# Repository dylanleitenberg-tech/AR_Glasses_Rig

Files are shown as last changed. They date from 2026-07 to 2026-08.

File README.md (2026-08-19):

# AR Eye Calibration Rig

AR glasses drift on your face all day, and every millimeter of slip moves where a display
pixel lands in the real world. This project is a camera rig and learning system that
measures how the glasses sit on your face in real time and corrects the overlay, so that
a pixel meant to land on a real object actually lands on it.

I designed and built this from scratch: the physics simulation, the calibration math, the
3D printed camera mount, the electronics and safety design, and the verification tooling
that checks all of it. 

I was able to achieve results with 4 cams so 6 may not be necessary. 
I mostly did this because the 6th cam arrived weeks later. 
Also, my power hub struggled on four so unless you have 
some heavy-duty hardware, 4 may be the way to go.

## Build overview and results

The rig is a 6-camera clip-on carrier for the XREAL One Pro AR glasses:

- 2 forward color cameras (global shutter) that triangulate a target drawn on paper
- 2 cameras watching the corners of your eyes, which is how the rig knows the glasses
  pose on your face at every instant
- 2 near-infrared cameras imaging each pupil, with 940 nm illumination behind hardware
  safety interlocks
- an IMU for slip and bump detection, all on one printed part that clamps to the glasses
  brow with padded jaws shaped to the measured curve of the frame

I drew up two versions of this carrier, an eight-camera one that adds a stereo pair and the
six-camera one above, and started with six. When the first cameras arrived I built a
four-camera rig from them, the two forward and the two watching my eye corners, and every
measurement in this repository so far was taken on those four. The fifth camera has arrived
and the sixth is on its way; the near-infrared pupil pair is the last thing to go in. The
parts lists still cost out the eight-camera version, which is where the sub-pixel work would
go.

Results so far, from a physics simulation built to be pessimistic about human error:

- With a naive calibration interface, deployed accuracy is about 13 pixels. Most of that
  error is the human in the loop, not the optics.
- With the interface I built instead (a vernier alignment task plus a per-user offset
  stage), simulated deployed accuracy is about 4.3 pixels as the user perceives it, on a
  1080p display per eye.
- The same pipeline with ideal inputs reaches 0.89 pixels, so the hardware and math
  support sub-pixel registration. Closing that gap requires a multi-distance
  calibration protocol that only works on real hardware, which is now implemented:
  the best measured result so far is 5.3 pixels median overlay error, cross-validated
  leave-one-out on a 33-sample run, using the physics geometry plus a quadratic
  learned residual. That is one evening on one seating, not a characterized average,
  and it sits close to the simulated 4.3.
- Just as important are the negative results. I tested and rejected several appealing
  shortcuts (bias-invariant fingerprints, richer per-user correction models, direct
  geometry refinement on user labels) because the simulation showed each one quietly
  overfits. The failures shaped the design as much as the successes.

 I also got the rig to draw an outline around a star shape on my wall, matching its 
 orientation and size, and the outline held on the shape as I moved my head. That is the closest
 the project has come to my end goal of real-world object overlay: not placing a marker at a point, 
 but tracing the boundary of an actual object and keeping it there under motion. My computer then 
 failed and that code was lost. I rebuilt it two days later on a replacement machine, and the
 new version is stronger than the one I lost: it traces the star's detected boundary point by
 point through the calibrated geometry, so orientation and size match by construction, and it
 held the outline on the shape for 99.8% of frames while my head moved.

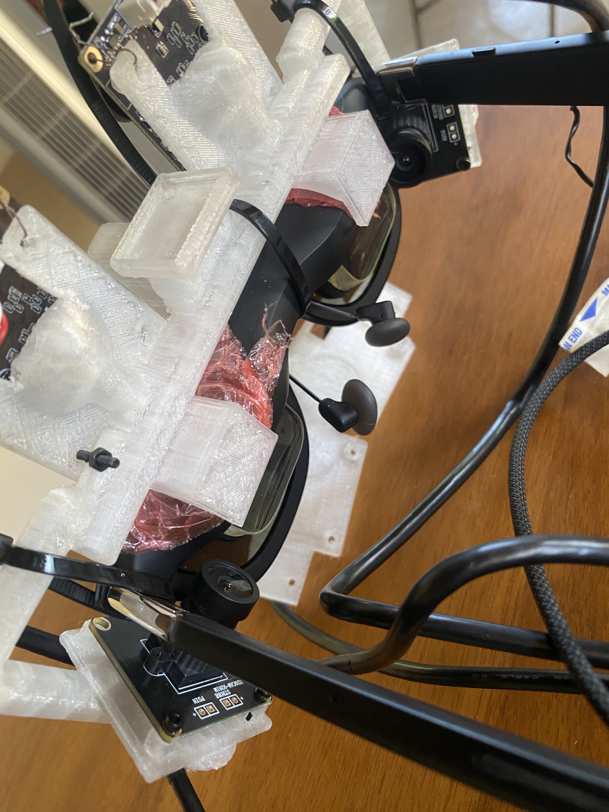
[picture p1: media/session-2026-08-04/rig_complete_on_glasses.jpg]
The rig


Current status: the rig is built and running on my face, now on a replacement computer
after the first one died. The forward pair finds the target and measures its distance at
30 frames per second with sub-pixel detection jitter, the calibration loop runs at over
80, and I have real calibration samples stored and a cross-validated overlay error rather
than a simulated one. The eye landmark model is trained on a fresh corpus of 2,588 frames
I captured and hand-labelled on the new machine, with a separate head that reports when
the eye is closed. One practical note from the rebuild: a single powered hub carries only
three of these camera streams at once, so calibration currently runs on the world pair
alone and the eye cameras run in their own sessions, until the cameras are split across
two host ports.

What the hardware phase actually produced, all measured on the rig:

- Overlay latency went from 196 ms to 62 ms once I worked out that most of it was my own
  smoothing rather than the cameras.
- I reverse engineered the IMU inside the glasses, which streams over TCP at about 1100 Hz.
  Nobody had documented the format, so I read raw packets and found the gyroscope and
  accelerometer by checking a stationary reading against gravity: 9.773 against 9.81.
- The overlay is now computed from physics rather than learned from scratch. A polynomial
  fit on few samples was throwing the marker across the display, so geometry became the
  backbone and learning became a correction that has to prove it helps before it is used.
- The display field of view had been assumed at 50 degrees since the project started. I
  measured it two ways and got closer to 48, which was worth more error than getting a
  user's eye spacing wrong by two standard deviations. Measuring again on the new machine
  went further: in follow mode the glasses render the desktop as a virtual screen of
  about 22 degrees, sitting below the forward axis, and both numbers depend on the
  glasses' display mode and screen-size setting. The constants are measured per session
  now, and every round of measuring this number has bought more accuracy than any model
  change.

## Why this problem

An AR display pixel corresponds to a ray leaving your eye through the optic into the
world. Where that ray lands depends on three things: the pixel you light up, the fixed
optics of the display, and where the glasses currently sit relative to your eyeball
(eye relief, slip down your nose, a few degrees of tilt, your IPD). That third item is
the killer. Shift the glasses 2 mm and the same pixel lines up with a different point in
the world. This is why one-time AR calibration never holds.

The key idea, which came out of an early design discussion with our robotics coach Chiem,
is to measure the glasses-on-face pose continuously by watching the corners of your
eyes. The inner canthus, the tear duct corner, is a stable facial landmark fixed to the
skull rather than to the eyeball, so its position in a glasses-mounted camera tells you
exactly how the glasses are seated right now without being confused by where you are
looking. I checked that property rather than assuming it: the landmark my model tracks
correlates with pupil position at 0.19, where the hand-tuned tracker it replaced sat at
0.99.

Reading the eye tracking literature later confirmed this was the right call for a reason
I had not known. Trackers that build a 3D model of the eye can compensate for the headset
sliding around, and purely 2D video methods have no known solution for it. Since my mount
is zip tied and does not sit the same way twice, that compensation is not a nice extra.
It is the only thing keeping a calibration valid for more than one session. The
system then learns a function from (target direction, eye corner geometry) to the
display pixel that lands on the target, using samples the user labels:

1. The forward camera pair finds a dot drawn on paper and triangulates it.
2. The model predicts a pixel and renders a red dot there.
3. You nudge with the arrow keys until the red dot sits on the real dot.
4. On approve, the rig snapshots the eye corner cameras at that instant and stores the
   sample.
5. Retrain, move the dot, re-seat the glasses, repeat.

After enough samples the function generalizes and places pixels correctly on its own,
even as the glasses move. Precision comes from the interface: the alignment task is a
vernier judgment (lining up segments, which people do several times more precisely than
covering a dot), because the simulation showed calibration accuracy is gated by the
quality of human corrections more than by any sensor.

## Why the XREAL One Pro

I originally wanted to modify Meta glasses, since they already carry cameras. They turn
out to be closed systems: Ray-Ban Meta has no display, and Meta Ray-Ban Display exposes
no framebuffer or camera access. The XREAL One Pro presents to the host as a normal
USB-C DisplayPort monitor, so the overlay renders to it with zero reverse engineering.
It is see-through with a display per eye, and it has a rigid front frame the printed
carrier clamps onto. The software is display-agnostic, and the CAD supports the Rokid
Max as a drop-in alternative.

## What is in the repo

- `software/` is the simulation and application code. The physics simulator models eye
  anatomy across a population, glasses slip, camera noise, lens distortion, blinks, and
  human error in the calibration loop. The application runs the live calibration with
  real cameras or fully simulated ones. Everything has self-tests.
- `cad/` is the parametric OpenSCAD model of the carrier. Camera positions are locked to
  the simulator's geometry file, and a parity check fails the build if the CAD and the
  simulation ever disagree about where a camera sits or points.
- `software/verify_all.py` is the release gate: one command that compiles everything,
  runs every self-test, checks CAD-to-simulation parity, verifies the printed solids
  against 35 pairwise clearance checks (parts against each other, the glasses body, the
  eyeballs, and the see-through view cones), exports the STL, and confirms it is a
  single connected solid.
- `ORDER_LIST.md`, `WIRING.md`, `ASSEMBLY.md`, `SAFETY.md`, and `EYE_TRACKING.md` cover
  parts, wiring with the power and interlock architecture, build steps, the hazard
  review, and the IR eye-safety design.
- `RESEARCH.md` maps the project onto the published state of the art (corneal-imaging
  calibration, PCCR gaze tracking, slippage-robust methods, synthetic training data,
  Quest Pro and Vision Pro benchmarks).

## The build

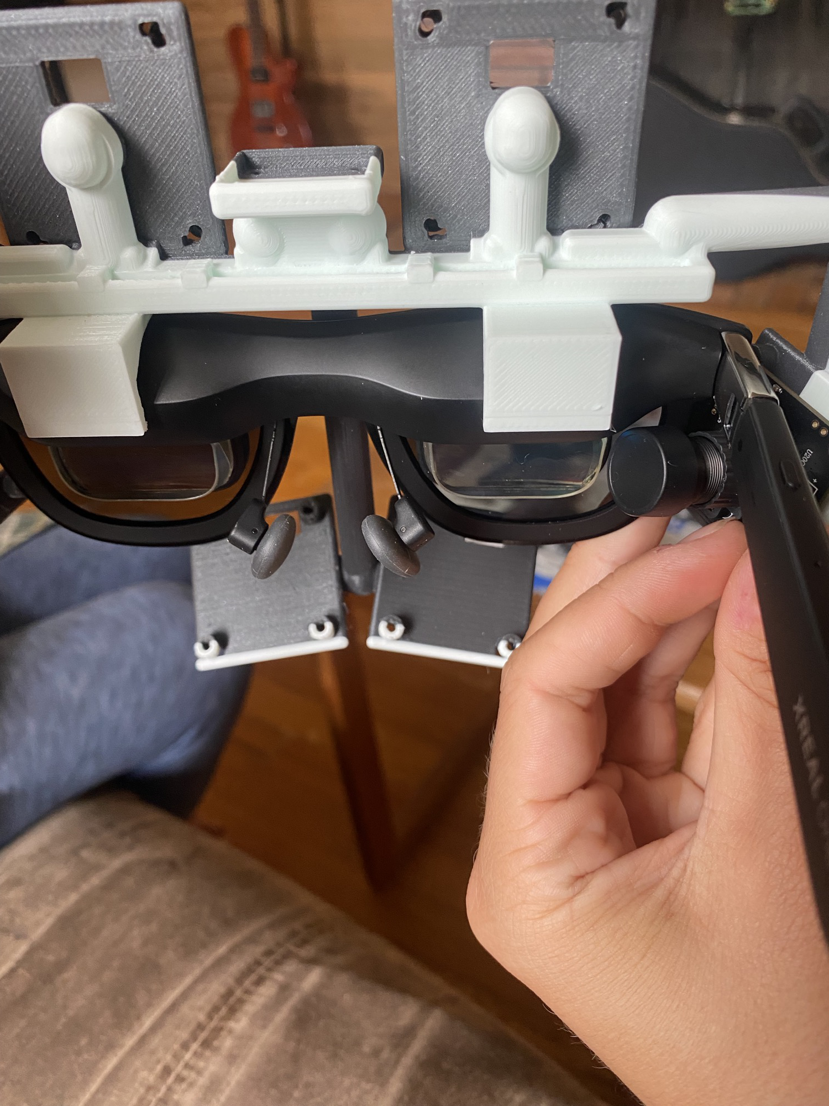
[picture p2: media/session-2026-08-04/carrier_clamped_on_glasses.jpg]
Carrier clamped on the glasses


Every mount dimension came off a pair of calipers rather than a datasheet, because the
camera boards did not match their published drawings closely enough to trust.

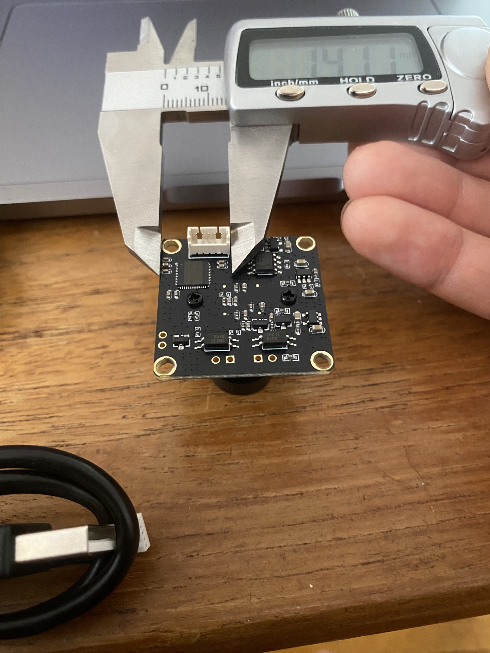
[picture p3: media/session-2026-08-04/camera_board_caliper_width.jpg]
Measuring a camera board


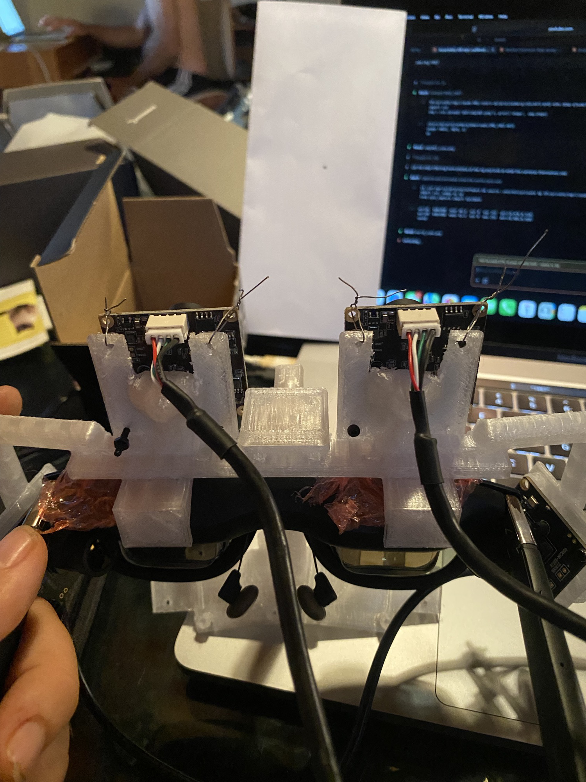
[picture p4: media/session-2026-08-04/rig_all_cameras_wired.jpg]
All cameras wired


The zip ties are load bearing. The carrier was designed for M3 thumbscrews and the printed
clamps did not hold well enough, so the working mount is zip tied. That is not tidy, but it
is honest about what the software has to survive: the mount does not sit the same way twice,
which is exactly the problem the eye corner cameras exist to solve.

More photos and what each shows: `media/session-2026-08-04/README.md`.

## Try it without hardware

The whole loop runs in simulation. It fakes the cameras and synthesizes ground truth, so
you can watch the model learn:

```bash
cd software
python3 -m venv .venv && source .venv/bin/activate
pip install -r requirements.txt
python3 main.py --simulate     # arrow keys nudge, ENTER approves, Q quits
```

`python3 verify_all.py --fast` runs the release gate's quick tier. See
`software/README.md` for the full module breakdown.

## Building the hardware

1. Print the carrier from `cad/xreal_one_mount.scad` and the IR rings as a second small
   print. The clamp jaws are shaped to caliper measurements of the actual glasses brow,
   taken from a hand-drawn dimensioned sketch and fitted with a spline.
2. Buy parts per `ORDER_LIST.md`. Cameras: 4 global-shutter mono modules for the eye
   side, 2 global-shutter color modules for the world side. Color matters there because
   the world cameras are the color reference for generated overlay content.
3. Clamp the carrier on, wire everything through a powered USB hub (one USB-C cable to
   the computer), and read `SAFETY.md` and the IR interlock section of `WIRING.md`
   before powering any LED.
4. Run the corner calibration once, then run the loop.

The safety design assumes failure: the IR LED current limits are set so that even a
stuck-on illuminator stays under conservative exposure limits, with the strobe and
watchdog as extra margin rather than the safety mechanism.

## Large-scale simulation studies

The repo includes the tooling I used to answer design questions with data instead of
guesses: population studies across thousands of simulated eyes, a pixel-by-pixel sweep
that walked 100 eye geometries times 100 glasses positions across the display (about
198 million labeled corrections), and ablations that measured what each sensor actually
contributes. Several cameras earned their place in the build this way, and one proposed
sensor (an IMU for pose estimation) was demoted to bump detection because the data said
it added nothing to registration.

That last conclusion turned out to be half right and worth revisiting. The IMU adds
nothing to registration accuracy, which the simulation had correctly shown. What it does
add is speed, and I only understood that after measuring latency on real hardware. The
cameras run at about 18 frames per second while the glasses' own IMU runs at 1100, and
overlay error from lag scales with how fast you turn your head. So the sensor the
simulation demoted came back as the fix for a different problem than the one I had
tested it against.

## What went wrong, and what that taught me

The most useful part of this project has been the failures, so they are documented in the
repo rather than quietly fixed.

The pattern that cost the most time, roughly ten separate instances, is a check passing for
a reason unrelated to what it claims to measure. A camera bring-up printed "BANK UP" with
two cameras returning nothing. A stereo geometry check took the absolute value of disparity
and so could not see that the two cameras were swapped. A template scored 0.99 on a patch of
blank skin. Three separate self-tests measured nothing at all until I rewrote them, one
because the synthetic signal ran off the edge of the frame within twenty frames and the rest
of the test window was a flat line.

The habit I built from that: when adding a check, write the failing case first and confirm
it actually goes red against the broken version. And when a number and an image disagree,
believe the image. Nearly every wrong turn I took came from trusting a measurement taken
while the glasses were sitting on my desk instead of on my face.

The second lesson is about tools versus problems. I spent a long time tuning a filter to fix
overlay lag, trading smoothness against delay and never getting both. A filter has one knob
and cannot do it. The answer, which the literature has known since the 1990s, is to predict
where your head will be when the light actually reaches your eye. That is not a better
filter, it is a different category of solution, and no amount of tuning would have found it.

## Acknowledgments

The eye-corner measurement idea came from our robotics coach, Chiem. Much of the early
speculation and problem-solving came out of design discussions with him.

I built this with AI assistance, which is why several commits carry a co-author trailer.
It wrote code alongside me and helped draft documentation. What it did not do is decide
what to build or what the results mean: the architecture, the experiments, the decision to
demote the IMU after an ablation showed it added nothing to registration, the negative
results above, and the corrections I have had to make to my own earlier conclusions are
mine. I have tried to write down the wrong turns as carefully as the working ones, because
on a project like this those are the part worth reading.

## License

Personal research project. Do what you like with it.

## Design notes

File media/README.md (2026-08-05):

# Media

CAD renders of the 6-camera binocular carrier, exported from
`cad/xreal_one_mount.scad` with the OpenSCAD CLI (2026-07-14):

- **`assembly_front34.png`**, `part="preview"`: the carrier on the XREAL One Pro
  stand-in (dark frame + translucent optic), with eyeball stand-ins. Orange = printed
  holders/booms, grey = rail + brow clamps, green = IMU pocket.
- **`assembly_top.png`**, the same preview from above (boom routing over the brow).
- **`carrier_only.png`**, `part="carrier"`: the single printable part, as sliced.

Regenerate: `openscad -o out.png --imgsize=1920,1440 --autocenter --viewall
-D 'part="preview"' cad/xreal_one_mount.scad`

## session-2026-08-04

Rig photos after the August software work: camera boards being measured with calipers, the
carrier clamped to the glasses, the eye corner camera on its boom, and the complete wired rig.
See `session-2026-08-04/README.md` for what each one shows.

## session-2026-08-03

Frames captured straight off the eye cameras during the August 3 session, including the
worn and not worn comparisons that the brightness normalisation work came out of. These are
raw sensor output, not photographs.

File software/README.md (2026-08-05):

# Software

Real-time human-in-the-loop calibrator that learns to place an AR pixel on a
real-world dot, using the corners of your eyes to sense how the glasses are seated.

## Install

```bash
cd ~/ar-eye-calibration/software
python3 -m venv .venv && source .venv/bin/activate
pip install -r requirements.txt
```

The learning core needs only `numpy`, so the **self-test runs without installing
opencv/pygame**:

```bash
python3 main.py --selftest        # prints a learning curve, should end in PASS
```

## Modules

| File | Role |
|---|---|
| `config.py` | all defaults + the canonical feature order |
| `calibrator.py` | polynomial-ridge regression `f(dot, eye-corners) -> pixel` (numpy only) |
| `dataset.py` | SQLite store of approved samples (numpy + stdlib) |
| `synth.py` | synthetic ground-truth physics for sim/self-test (numpy only) |
| `cameras.py` | OpenCV capture wrapper; `snapshot()` = the high-speed approval grab |
| `dot_detector.py` | finds the drawn dot in the world frame -> normalized (x,y) |
| `eye_tracker.py` | template-matches your eye corner -> normalized (x,y) |
| `pupil_tracker.py` | **eye-tracking upgrade**: IR pupil + glint detection -> gaze features (`--selftest`; see `../EYE_TRACKING.md`) |
| `overlay.py` | black canvas + red dot (+ green truth target in sim) on the AR display |
| `input_ctl.py` | keyboard nudge/approve/quit (gamepad optional via pygame) |
| `main.py` | the integrated loop + all the modes |

### Hardware bring-up layer (connect · sync · adjust · mesh)

The host-side stack that gets the 6 cameras running on the Mac, see **[../HARDWARE_BRINGUP.md](../HARDWARE_BRINGUP.md)**. Every module has a headless `--selftest` (in the release gate):

| File | Role |
|---|---|
| `connect.py` | auto-classify the 6 USB cams (color/mono, res), assign roles, persist `data/rig_cameras.json` |
| `sync_capture.py` | `SyncBank`: barrier-aligned **synchronized** grab across all cameras + measured jitter |
| `autoexpose.py` | per-role **continuous** exposure/gain control (world sharp, pupil glints hot / field dark) |
| `world_mesh.py` | **real-world mesh tracking**: stereo triangulate + robust Kabsch VO + IMU-fused pose + Delaunay mesh |
| `imu_serial.py` | `GyroIntegrator`: XIAO gyro → per-frame rotation increment for the mesh |
| `rig_test.py` | one-command bring-up test: enumerate · fps · sync jitter · IR test · focus |
| `snapshot.py` | save one synchronized frame-set (6 PNGs + trustworthy `meta.json`) |
| `live_rig.py` | the integrated driver: sync grab → auto-expose → mesh track → feature capture, live telemetry |

```bash
python3 connect.py --auto && python3 connect.py --identify   # map cameras -> roles (once)
python3 rig_test.py --run        # is the rig fit to calibrate on?
python3 live_rig.py --run --imu  # everything running together
```

## Running

```bash
# 1) See the model learn, no hardware:
python3 main.py --simulate            # align RED onto GREEN, ENTER approves

# 2) On hardware, one-time: teach it your eye corners
python3 main.py --list-cams
python3 main.py --calibrate-corners --eye-cam-left 1 --eye-cam-right 2

# 3) Run for real
python3 main.py --world-cam 0 --eye-cam-left 1 --eye-cam-right 2 --fullscreen
```

### Controls
- `w a s d`: fine (pixel-level) nudge · `W A S D`: coarse jump
- arrow keys, nudge (shift = fine) · ENTER/SPACE, approve · Q, quit (vernier.py UI; gamepad optional)
- `ENTER`: approve & snapshot · `R`: recalibrate corners · `Q`/`ESC`: quit

## How a sample is captured (the core loop)

1. `read_real_features()` → dot in both world cams (x,y ×2) + both eye corners (x,y ×2)
   = 8 numbers (the two world cams give stereo parallax on the dot).
2. `calibrator.predict()` → where it *thinks* the pixel should go.
3. You nudge the red dot onto the real dot.
4. `ENTER` → `snapshot_features()` does the **high-speed eye snapshot** (flushes
   the camera buffer, grabs the freshest frame so a small head move doesn't blur the
   canthus), pairs those features with the pixel you approved, writes it to SQLite,
   and refits the model. Nudge resets; draw/move the dot and go again.

As samples accumulate across different dot positions *and* different ways the glasses
sit on your face, the prediction in step 2 lands closer and closer to the real dot,
until you barely nudge at all. Inspect progress any time:

```bash
sqlite3 ../data/samples.db "SELECT COUNT(*), AVG(pixel_x), AVG(pixel_y) FROM samples;"
```

## The mapping model (calibrator.py)

Degree-2 polynomial regression from the 8 features to the display pixel, hardened so
it stays accurate on a small, human-collected, noisy dataset:

- **Standardized** features + polynomial terms → well-conditioned fit; the
  regularization means the same thing everywhere on screen.
- **Auto-regularization (GCV)**: the ridge penalty `lambda` is chosen automatically
  each refit via one SVD (Generalized Cross-Validation). No hand-tuning; it
  self-adjusts from 6 samples to thousands. The chosen `lambda` shows in the HUD.
- **Robust (Huber IRLS)**: a single mis-tracked eye corner or fat-fingered approve is
  down-weighted instead of warping the whole map. In the self-test, with 12% gross
  outliers, naive least-squares lands ~32 px off vs ~10 px for the robust fit.
- **Confidence-weighted**: each sample carries the eye-tracker's match score
  (`weight` column); crisp captures count more. Approvals below `eye_conf_min` are
  rejected outright so junk never enters the dataset.
- **Smoothing**: live eye features (`feat_smooth`) and the shown prediction
  (`pred_smooth`) are EMA-filtered to kill jitter.

Check the held-out accuracy any time with `holdout_error()` (k-fold; returns RMS +
median in normalized units), or watch it live in `--selftest`.

## Tuning notes
- Finer nudges: lower `nudge_gain` in `config.py`, or use the stick.
- Add features (pupil position, IMU tilt): extend `config.feature_names` and the
  readers, the calibrator adapts to any feature count automatically.
- Below `min_samples_for_model` (6) it predicts the confidence-weighted mean pixel;
  keep approving and it switches to the learned model.
- Robustness/where regularization can roam: `robust_iters`, `huber_k`,
  `lambda_lo/hi/steps` in `config.py`.

```bash
sqlite3 ../data/samples.db "SELECT COUNT(*), AVG(weight) FROM samples;"   # dataset health
```

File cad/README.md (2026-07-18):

# CAD, the camera carrier

The build needs `xreal_one_mount.scad`: the **removable clamp-on carrier** (padded brow clamps
+ M3 thumbscrews; bonding is the later rigid-phase upgrade) that holds all 6 cameras and the IMU.
Print TWO parts from it: `part="carrier"` and `part="ir_ring"` (the rings mount at the lens rims).

| File | Status | What it is |
|---|---|---|
| **`xreal_one_mount.scad`** ⭐ | **THE part, print this** | Removable clamp-on **6-camera BINOCULAR** carrier for the **XREAL One Pro**: 2 world (outward) + 2 eye-corner + 2 NIR pupil (one of each per eye) + the IMU tower; separate `part="ir_ring"` print for the 940 nm rings (baffled, ≥10 mm standoff). `build_stereo=true` adds the 2 stereo cams → 8-cam FULL upgrade. |
| `eye_tracking_bridge.scad` | optional / legacy | A clip-on nose + IMU support. **Not required**: the IMU and face padding are on the carrier now; the XREAL's own nose pads carry the face. |
| `glasses_frame.scad` | legacy / Path B | A full from-scratch Meta-style frame for the DIY-combiner fallback (no XREAL display). |

> **Default display = XREAL One Pro** (57° diag FOV, 87 g, flat X-prism optic, front frame
> ~11 mm, IPD size M 57-66 / L 66-75 mm). Set `target` (`"xreal_one_pro"` / `"xreal_one"` /
> `"rokid_max"`) and `xr_size`. XREAL publishes no mechanical CAD, **confirm gripped edges with
> calipers** before printing.

The authoritative camera geometry is `software/rig.py`; `xreal_one_mount.scad` places each
camera's optical centre at `sim2cad(rig.py position)`, and `software/cad_fit.py` verifies every
real board clears the see-through cone, the eyeball, and the face.

## Install OpenSCAD

```bash
brew install --cask openscad        # macOS  (or download from https://openscad.org)
```

## Preview

Open `xreal_one_mount.scad` and press F5 (preview) / F6 (render). `part = "all"` shows the
assembly with translucent glasses + eye stand-ins, colored by subsystem:

- grey = rail + brow clips      · green boards = the camera modules you buy
- orange = camera holders/booms · red = IR LED rings (baffled)
- seagreen = IMU pocket         · gold = epoxy bond pads

The red cone is each eye's see-through keep-out (no camera may sit inside it).

## Export STLs for printing

One print covers everything (cameras + IR baffles + IMU pocket are all on the carrier):

```bash
cd ~/ar-eye-calibration/cad
openscad -D 'part="carrier"'   -o carrier.stl   xreal_one_mount.scad   # the whole carrier
openscad -D 'part="bond_pads"' -o bond_pads.stl xreal_one_mount.scad   # (optional, separate pads)
# build_stereo=true on the carrier export adds the 2 stereo cams (8-cam FULL upgrade)
```

`part` options: `all` | `carrier` | `board_cam` | `bond_pads` | `imu_mount`.

## Tune before you print (important)

Measure your unit and edit the parameters at the top of `xreal_one_mount.scad`:

| Parameter | What to measure | Typical |
|---|---|---|
| `target`, `xr_size` | your XREAL model + size | `"xreal_one_pro"`, `"M"` |
| `ipd` | your interpupillary distance | 64 (M) / 69 (L) mm |
| `xr_brow_z` | front-to-back thickness of the brow edge the clip grips | ~11 mm |
| `clip_x` | a flat span on the brow to clamp | ~38 mm |
| `OPTIC_DROP` | how far the optic centre sits below the brow rail | measure |
| `cf_rod_d` | carbon-fibre stiffening rod diameter (0 = none) | 1.5 mm |
| `ir_ring_r`, `ir_min_standoff` | IR ring radius + min LED-to-eye clearance (safety) | 13 / ≥10 mm |

Print one cheap draft, dry-fit on the brow, confirm in OpenSCAD that the eye-facing lenses
frame the pupils/canthi and no camera enters the cone (run `python3 software/cad_fit.py` after
any position change). The pupil/canthus aim is the part most worth iterating.

## Material & print notes

- **Stiff material, SLA resin or PC / nylon-CF filament, NOT plain PETG/PLA** (the carrier must
  hold camera-to-frame motion < 0.2 mm). 0.2 mm layers, 3 perimeters / high infill.
- Glue **1.5 mm carbon-fibre rods** into the boom channels (`cf_rod_d`) for stiffness; the booms
  are trussed so they can't sag/resonate.
- **Pad any printed surface that touches the face** (the `brow_pad` recess) with soft
  silicone/foam, the XREAL's own pads carry the nose. No bare hard plastic on skin.
- **IR safety is mechanical too:** each LED sits in a baffle (`ir_baffle`) that recesses it and
  keeps the ring ≥ `ir_min_standoff` mm from the eye, see `EYE_TRACKING.md §3`.

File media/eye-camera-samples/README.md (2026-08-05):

# What the eye cameras see

Raw frames from the two inward-facing cameras, with the tracker's lock drawn on.

These are the input to the whole glasses-on-face measurement. The green box is where the
model thinks the inner eye corner is. The dark shape at the top of each frame is the nose
bridge support, which blocks the top third of the view and is the reason the search band
sits below it.

The left and right frames look different because the room is lit from one side. That
asymmetry is not a fault, it is the normal case, and it is why every frame is brightness
normalised before the model sees it.

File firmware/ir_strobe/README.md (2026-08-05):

# firmware/ir_strobe: IR strobe + safety interlock MCU

Reference firmware for the strobe MCU (**Seeed XIAO** RP2040/SAMD21, or any Arduino) that
drives the 940 nm IR LED rings and **enforces the eye-safety envelope**. It is the concrete
implementation of the interlocks documented in `WIRING.md` and `EYE_TRACKING.md §3`.

## What it does (all fail-safe: default IR OFF)

| Interlock | How |
|---|---|
| **Strobe in sync with the shutter** | IR fires only as a bounded **pulse** on a host `P <us>` command issued at each exposure |
| **USB/host drop kills IR** | heartbeat watchdog, no host line within `HB_TIMEOUT_MS` forces both gates low (and aborts a pulse mid-flight) |
| **Voltage safeguard** | the 5 V rail is read every loop; outside `[VMIN,VMAX]` IR is disabled |
| **IR cutoff on blinks** | host `B L|R|0` flags a closed eye; that ring is held off |
| **Dose / duty caps** | pulse clamped to `MAX_PULSE_US`; `MIN_OFF_US` enforces a low duty cycle |
| **Any anomaly / reset → OFF** | gates default LOW + an external **100 k gate pull-down** guarantees OFF through power-up and MCU reset |

The **300 mA PTC polyfuse** (overcurrent) and the **TVS clamp** (transients) are hardware on
the IR branch, see `WIRING.md`. The MOSFET is a **2N7002** (logic-level, not a 2N2222 BJT).

## Host serial protocol (115200 baud, newline-terminated)

```
HB            heartbeat (send at >= 20 Hz so the watchdog stays satisfied)
EN  / DIS     arm / disarm strobing
P <us>        fire one IR pulse of <us> microseconds at the current exposure (clamped)
B L | R | 0   blink state: left / right eye closed, or 0 = both open
```

Any recognized line also refreshes the heartbeat. The host loop: send `EN` once, then each
camera frame send `P <exposure_us>` right before grabbing, send `HB` if idle, and send `B …`
from `software/blink.py`. On exit send `DIS` (and just closing the port trips the watchdog).

## Wiring (summary: full topology in WIRING.md)

- `IR_GATE_L/R` → 2N7002 gates (each with a **100 k pull-down to GND**); LED ring sources on
  the drains, rings to the 5 V rail **through the 300 mA polyfuse**.
- `RAIL_SENSE` → the 5 V rail through a **2:1 divider** into an ADC pin (set `RAIL_DIV`/ADC
  scaling to your board; XIAO ADC ref 3.3 V).
- IR power pair **twisted + star-grounded**, routed away from the USB data cables.
- IMU (ICM-20948) on I2C → the XIAO bridges it to USB (stub at the bottom of the sketch).

## Bring-up

1. Flash, set the pin numbers / ADC scaling for your board.
2. **Verify fail-safe FIRST:** with no host connected, gates read LOW (IR off). Open a serial
   monitor: `EN` then `P 1000` pulses; stop sending and the watchdog cuts IR within
   `HB_TIMEOUT_MS`.
3. Only then enable in the live pipeline, at the lowest IR current that tracks (see
   `EYE_TRACKING.md §3`).

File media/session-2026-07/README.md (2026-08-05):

# Session images: July 2026 (build + overlay work)

| Image | What it shows |
|---|---|
| `rig_mounted_on_glasses.jpg` | The printed **v9 carrier** clipped onto the real **XREAL One Pro**, with a camera mounted, physical proof the mount fits the frame (the shot that showed the eye-cam sits tight at the hinge). |
| `carrier_led_shelves.png` | Carrier render (underside), the **LED mounting shelves** on the two pupil holders that the separate bracket bolts onto. |
| `led_bracket.png` | The separate `led_bracket` print, **2 baffled 940 nm LED pockets per eye**, flush arm roots (no domes through the plate). |
| `carrier_underside.png` | Carrier underside (plates + boom bosses). |
| `overlay_monkeys_demo.png` | `augment_rig.py` output, two people rendered as **world-locked monkeys** (nearer one larger, depth-sorted), on the black = transparent overlay canvas. |
| `monkey_sprite.png` | The procedural monkey placeholder asset (swap a PNG / rigged 3D model for "realistic"). |

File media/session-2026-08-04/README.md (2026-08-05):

# Rig photos, August 2026

The rig as it stands after the software work of August 3 and 4.

| photo | what it shows |
|---|---|
| `camera_board_bare.jpg` | One of the global shutter camera boards before mounting |
| `camera_board_caliper_width.jpg` | Measuring the board so the CAD pocket fits it, not a datasheet drawing |
| `camera_board_caliper_thickness.jpg` | Same board, thickness. Every mount dimension came from calipers |
| `carrier_clamped_on_glasses.jpg` | The printed carrier clamped onto the XREAL One Pro brow |
| `eye_camera_mounted_on_boom.jpg` | An eye corner camera on its boom, aimed at the inner canthus |
| `sabrent_usb_hub_six_ports.jpg` | The hub every camera shares. One USB 2.0 bus is the reason capture modes matter |
| `rig_wired_bench_test.jpg` | All cameras wired, running on the bench |
| `rig_all_cameras_wired.jpg` | The full four camera bank before a calibration run |
| `rig_complete_on_glasses.jpg` | The complete rig, which is what actually goes on my face |

The zip ties in these photos are load bearing. The carrier was designed for M3 thumbscrews,
but the printed clamps did not hold well enough, so the working mount is zip tied. That is
why the software has to measure how the glasses sit rather than assume it: the mount is not
repeatable between sessions, and a calibration that assumes a fixed seat expires the moment
the rig shifts.

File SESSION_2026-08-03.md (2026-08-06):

# SESSION 2026-08-03: what changed, why, and the numbers

Written so none of it has to be re-derived. Every figure here was measured on this rig or against
its simulator; assumptions are labelled as such.

*Working notes, written up with AI assistance as the session happened. The measurements, the
decisions, and the conclusions are mine.*

---

## THE ARC OF THE SESSION
Started trying to run a calibration. Found and fixed **six distinct blockers**, then discovered the
architecture itself was wrong (a learned polynomial where physics belonged), then measured the
constant that had been guessed since the project began.

## BLOCKERS FOUND AND FIXED

| # | blocker | evidence | fix |
|---|---|---|---|
| 1 | `CanthusTracker.__init__` never created `self.anchor` | `--use-model` raised on frame ONE of both eye cams, while 38 checks stayed green | init the state; selftests build through `__init__`; added a PRODUCTION-PATH check |
| 2 | Loop discarded every keypress on a not-live frame | polled `.quit` only, then `continue`d before nudge and approve | one input path with a `live` flag; the reason NAMES the failing camera |
| 3 | `_gate_dot` had no escape | a jump returned `prev` without updating it → feature froze forever; ruined a 35-sample set (all 8 features spanned 0.013–0.052) | `DOT_MAX_HELD=8`: a sustained new position is accepted |
| 4 | Model trained at one seating | offline error 224 px; live miss ~0.12 frame | retrained on 87 fresh clicks → **23 px** |
| 5 | Per-sensor capture modes | asking AR0234 for 640×400 silently returns NATIVE 1920×1200 → starved half the bank ("only 2 cams running") | `cameras.ROLE_MODE` table + a warning when requested ≠ actual |
| 6 | Dot detector picked per-camera | the real dot ranked 2nd/3rd; two cams locked different furniture | `detect_pair` chooses the stereo pair JOINTLY |

## THE ARCHITECTURAL INVERSION
A 45-term quadratic over 8 features was **replacing** geometry once 6 samples existed. Fitted to a
cluster, it extrapolated violently: the dot flew off with the smallest movement.

Measured, trained on a clustered set and tested across the whole field:

| samples | polynomial replaces geometry | **geometry + residual** |
|---|---|---|
| 8 | median 383 px, **p95 999 px** | median **122**, p95 **319** |
| 15 | 349, **1037** | **172**, **352** |
| 35 | 212, 660 | 202, **399** |

A p95 of 999 px on a 1080-tall display is off-screen. **Geometry is now the backbone**, learning a
bounded residual, and `Calibrator.fit` k-folds the residual against geometry-alone and **discards
it unless it wins**. On the real 17 samples it discards (pure geometry, 27 px); in the 240-sample
sim it keeps it (11.8 px).

## LATENCY: the largest registration error
Holloway (Presence 6, 1997): system delay is the **largest single registration error**, because
every other term is constant while latency scales with **head angular velocity**.

| source | before | after |
|---|---|---|
| capture + process (17.9 fps) | 56 ms | 56 ms |
| `feat_smooth` EMA | 84 ms | **0** (world dot now unsmoothed, it IS the fast signal) |
| `pred_smooth` EMA | 56 ms | 6 ms |
| **total** | **196 ms** | **62 ms** |

Then, because a causal filter can only trade lag against jitter, **prediction** replaced filtering.
Measured at PHOTON time (against where the target *will* be, comparing to "now" rewards lag):

| | fast | turns | overall | jitter@rest |
|---|---|---|---|---|
| raw | 40 px | 6 | 30 | 0.0040 |
| One Euro only | 74 | 9 | 57 | 0.0014 |
| **predicted** | **23** | 10 | **21** | 0.0018 |

## THE XREAL IMU: decoded from scratch
**Not HID** (those interfaces open and produce nothing). The glasses are a **USB network device**:
`en8`, host 169.254.2.10, **glasses at 169.254.2.1, TCP 52998**, streaming on connect.

```
134-byte records, magic 28 36 00 00, ~1100-1400 Hz
offset 0x22  3x float32 LE  GYRO   rad/s
offset 0x2e  3x float32 LE  ACCEL  m/s^2
```
**Confirmed by physics:** stationary |accel| = **9.773 m/s²** vs gravity 9.81, 0.38% off. A wrong
offset would still decode to finite floats, which is why `--live` re-checks it.

**Axis map measured** (`--map`): `du←wy(yaw) +`, `dv←wx(pitch) −`, |corr| **0.99**, fitted/theoretical
0.97, independently confirming `WORLD_FOV=70`. Three fixes got it from 0.13 to 0.99: **optical flow
not the dot**, **integrate not differentiate**, **constrain the fit to the physics** (a free 2×3 fit
attributed u to ROLL with a coefficient of −2.76 where the whole plausible range is 0.82).

## LIGHTING: solved in software, no hardware
Corpus spanned brightness **139–161**. Live eyeR sat at **49**, entirely outside it.

| | normal | dark ×0.5 | dark ×0.34 |
|---|---|---|---|
| none | 25 px | 206 | 715 |
| mean-normalised | 26 | 25 | 23 |
| **median-normalised** | **21** | **21** | **21** |

Median beats mean because a blown-out corner drags the mean up (eyeL: mean 39, **median 11**).

Then **gradient augmentation** at retrain, ramps 0.15–0.75, gamma 0.6–1.4, gain 0.30–1.50:

| model | clean | dark | **side-lit** |
|---|---|---|---|
| old | 24 px | 25 | **269** |
| new | 34 | 29 | **76** |

3.5× better where it was catastrophic, 42% worse where it was fine. **Illumination flattening was
tested and REJECTED**, fixes gradients but destroys clean (26→243 px), because the model never saw
flattened images.

## DISPLAY SCALE: the constant that had been guessed
Two methods: wall (46.71°) and fitting to the 17 ground-truth samples (**48.25°**, 27 px vs 32 px at
the old 50.0). They do **not** fully reconcile, D was measured from the cam lens, 50.5 mm forward of
the eye, which pushes the physical value *down* to ~45.2°.

**Resolution: `DISPLAY_FOV_DEG` is an EFFECTIVE SCALE, not the physical FOV.** It is the only free
scale between direction and pixel, so it absorbs unmodelled distortion (k1/k2 still placeholders),
the eye-position assumption, and residual world-camera error. **Do not "fix" it to the physical
value**, that is more faithful and measurably worse (43 px vs 27 px).

## THE EYE-CORNER FEATURES: wired in, inert, and why
`geometric_pixel` had been reading only `x[0:4]` and **discarding the eye features entirely**. The
whole canthus pipeline was gating frame usability and contributing nothing to where the pixel goes.
Now implemented (`eye_offset_mm`), guarded, and **`EYE_SHIFT_GAIN = 0.0`**.

Swept against the real samples: gain 0.00 → **26.9 px** (best), 0.50 → 27.3, 1.00 → 27.6.
**The reason is in the data:** eye-feature spread was sd **0.032 / 0.0085**, the glasses barely
moved. A glasses-position correction cannot help when the glasses did not move.
**→ RE-SEAT THE GLASSES between batches next run, then re-run the sweep.**

## SENSITIVITY OF THE GEOMETRY (px of 1920)
| perturbation | cost |
|---|---|
| IPD wrong 3.5 mm (1 sd) | 4 px |
| IPD wrong 7 mm (2 sd) | 7 px |
| eye depth wrong 5 mm | 2 px |
| eye height wrong 3 mm | 11 px |
| **DISPLAY_FOV wrong 2°** | **18 px** |
| **DISPLAY_FOV wrong 5°** | **49 px** |

## NEW MODULES
`depth.py` (metric stereo depth + uncertainty), `geometry.py` (closed-form pixel),
`smoothing.py` (One Euro), `predictor.py` (latency compensation), `xreal_imu.py` (IMU driver),
`eye_check.py` (worn-rig diagnostic). New docs: `LATENCY_AND_TRACKING.md`, `DOMAIN_REFERENCE.md`,
`CAPABILITIES.md`.

## THINGS I GOT WRONG (kept so they are not repeated)
- Claimed saturation detects worn-vs-desk. It does not, a dim room read 0.2% and passed.
- Claimed flat-skin separates worn from room. Classes **overlap** (worn 83–92, room 77–83); it
  false-negatived a rig locking 88%. Now an advisory corroborated by lock state.
- Claimed `cameras.py`'s 4:3 assumption "measured not to matter", I had tested a software resize,
  not the camera.
- Inferred an eye-camera swap from OFF-FACE data and had to withdraw it.
- Switched the display to Extended with the mirror master/follower backwards.
- Re-aimed at a target that was already correctly in frame, at 1–3 m it is ~30 px wide,
  and a full-frame glance cannot settle presence. **Zoom before doubting the setup.**
- Three separate selftests measured nothing until rewritten (a ramp that clipped; a steady ramp
  where a fixed EMA looks fine; nominal values taken from the wrong source).

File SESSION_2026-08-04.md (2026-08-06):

# SESSION 2026-08-04: the 17 samples were 13, and last session ran in the wrong display mode

*Working notes, written up with AI assistance as the session happened. The measurements, the
decisions, and the conclusions are mine.*

**Two parts.** PART 1 was offline (the XREAL was unplugged): re-analysis of the stored samples,
closed-form properties of `geometry.py`, and simulation, **none of it a worn measurement, and
labelled as such throughout.** PART 2 is the hardware session that followed, written up at the
bottom, and it contains the single most consequential finding of the day:
**last session was run in LOCKED (anchor/3DoF) mode, not follow**, which my notes had recorded
the opposite way, and which taints the 17 samples and the constant fitted to them.

Part 1 turned out to be the right place to look anyway, because two of the things this project
believed about its own only real dataset are wrong.

---

## 1. FOUR OF THE SEVENTEEN SAMPLES ARE UNSTORABLE, AND THEY CARRIED THE SPREAD CLAIM

`data/samples.db` samples **1, 11, 14, 15** have the world dot at u≈0.96-0.97, v≈0.05-0.07, the
extreme corner of the world frame. That is **36-37° off axis, against a display half-angle of
24.1°**. The display physically cannot show anything there.

**Why nobody saw it:** `geometry.geometric_pixel` CLIPS to [0,1]. An off-screen target silently
became an edge pixel, the operator nudged the overlay onto whatever they could actually see, and
the sample stored looking entirely ordinary. Sample 1 even scored the **best error in the set,
0.9 px**, because the human had pushed the dot into the same corner the clip produced. *A check
agreeing with a clamp is not a check.* This is the ninth-and-tenth instance of a pattern I have
been logging all along: a number went green for a reason unrelated to what it claimed to measure.

| | all 17 | the clean 13 |
|---|---|---|
| world-dot u span | **0.467** | **0.056** |
| approved display-u span | 0.617 | 0.126 |
| geometry error, median | 26.9 px | 25.9 px |
| geometry error, p95 | **693 px** | 60 px |

**The recorded claim "world dot span 0.37-0.48 … the feature spread is finally healthy" was
produced entirely by the four poisoned samples.** Without them the run covered **5.6% of the
world field**, barely better than the 0.026-0.052 of the runs it was being contrasted against as
"degenerate". Three of the four also carry the only gross errors in the set (640, 690, 706 px).

**FIXED, and it cannot recur:**
- `geometry.offscreen(features)` / `geometry.offaxis_deg(features)`, with
  `geometric_pixel_raw` exposing the unclipped pixel. `geometric_pixel` still clips, because a
 render loop cannot draw off-canvas, the bug was never the clip, it was that nothing else could
  see it had happened.
- `main.py` **refuses the approve** and says why, and draws it **on the display** , 
 `TARGET IS 37 DEG OFF AXIS / OUTSIDE THE 48 DEG DISPLAY / turn towards it`, because the
  operator is wearing the rig and the terminal does not reach them.
- The `geometry.py` selftest pins the **four literal stored feature vectors** as must-reject and
  four real good ones plus a legitimate display-edge target as must-keep. A guard that throws away
  real data would be worse than the problem.
- `reseat.py --check` reports contamination FIRST, before any statistic computed over the samples.

## 2. `DISPLAY_FOV_DEG = 48.25` IS NOT PINNED TO ±0.1: IT IS PINNED TO ABOUT ±3°

Bootstrapping the fit that produced it (400 resamples):

| set | best fit | 95% CI |
|---|---|---|
| clean 13 | 49.00° | **47.2 – 52.8** |
| all 17 | 49.00° | 46.7 – 52.8 |

The profile is not a parabola, it is bumpy noise: 25.9 px at 47.0°, 26.5 at 48.0, 20.6 at 49.0,
25.6 at 50.0. **Thirteen samples spanning 5.6% of the field cannot pin an angular scale**, there
is almost no lever arm.

**What stays true:** 48.25 beats the old assumed 50.0 *in sample*, and the "keep the fitted value,
do not substitute the physical one" reasoning in `geometry.py` is unchanged and still right.
**What changes:** the *precision* implied by quoting "48.25" was never there, and since 2° of FOV
error costs 18 px, the constant carries roughly as much uncertainty as the residual it was
credited with removing. **Removing the 4 poisoned samples does not move it** (48.20 → 49.00, both
deep inside the CI), so the contamination did not bias this constant, it just never had the
spread to determine it. **Pinning it needs a run that spans the field**, which is now the second
requirement on the next calibration.

## 3. THE EYE-CORNER CORRECTION IS A NEAR-FIELD TERM. IT IS PARALLAX, AND IT DIES AS 1/DISTANCE

Measured off `geometry.py`, overlay shift for a **3 mm** change in how the glasses sit:

| target distance | 0.4 m | 0.7 m | 1 m | 2 m | 5 m | **20 m** |
|---|---|---|---|---|---|---|
| overlay shift | 14.3 px | 8.6 px | 6.1 px | 3.1 px | 1.3 px | **0.3 px** |

**This is strategically important and was not previously written down.** The end goal is overlaying
people and cars that are FAR AWAY. Out there the eye-corner correction is worth **a third of a
pixel**, it cannot be an accuracy lever for the actual product goal. Its value is near-field, plus
what it already does: gating whether a frame is usable, and detecting slippage on a zip-tied mount.
This is the same shape as the existing far-field note (the ~34 mm camera-to-eye offset subtends
0.096° at 20 m), and for the same reason: both are parallax.

## 4. THE 2026-08-03 GAIN SWEEP WAS UNDERPOWERED, NOT A NULL RESULT: AND NOW IT SAYS SO

`reseat.py --check` reproduces the old sweep exactly (26.9 px at gain 0.00, rising monotonically , 
the recorded numbers) and then shows why it decided nothing:

```
seat span            0.00 mm across 1 seating
effect of gain 1.0   median 0.85 px, max 1.91 px
regression gain      23.22 +- 61.77
VERDICT              CANNOT DECIDE
```

The term could move the overlay by **less than one pixel** on that data. Writing "the eye-corner
correction does not help" would have been a claim the data cannot support, and `EYE_SHIFT_GAIN`
would have stayed 0.0 for a reason that was never tested.

**`reseat.py` can now return three answers, and the third is the one the old sweep could not
express: SET IT, LEAVE IT OFF (a real null), or CANNOT DECIDE.**

## 5. THE MEDIAN-ERROR GRID IS THE WRONG ESTIMATOR. USE THE REGRESSION

Sweeping gains and taking the lowest median error is far too blunt for a term worth a few px under
a ~27 px systematic. Instead, fit the gain directly:

```
Y - pixel(gain=0)  =  A . [1, world_u, world_v]  +  g . (pixel(gain=1) - pixel(gain=0))
```

The affine term absorbs every registration error that is a smooth function of target direction , 
display scale, distortion, kappa, world-camera error, i.e. exactly the ~27 px this project has
been unable to see past. `g` is then identified only by samples pointing the same way whose eye
features differ, which is what re-seating creates and a single seating does not contain.

Measured over 10 seeds per design, recovering a **planted gain of 1.0**:

| protocol | grid rms error | **regression rms error** |
|---|---|---|
| recommended (6 mm re-seat, 0.4-1 m, n=32) | 0.34 (mean 0.90) | **0.12 (mean 0.99)** |
| marginal (3 mm re-seat, 1-3 m, n=32) | 0.56, **mean 0.53** | 0.54, mean 0.91 |

The grid does not merely scatter, **it reads LOW**, towards zero, because a small term cannot move
the median of a widely-scattered distribution. That is the shape of the 2026-08-03 result.

## 6. THE PROTOCOL FOR THE NEXT RUN, DERIVED RATHER THAN GUESSED: `reseat.py --power`

| protocol | n | effect | recovered gain | SE | detects a true gain |
|---|---|---|---|---|---|
| 2026-08-03 (no re-seat, 1-3 m) | 17 | 0.2 px | 1.17 | 3.50 | **0%** |
| off-and-on re-seat, 1-3 m | 32 | 1.8 px | 0.86 | 0.38 | **50%** |
| off-and-on re-seat, 1-3 m | 64 | 2.1 px | 0.97 | 0.20 | 100% |
| **re-seat BIG (6 mm), 1-3 m** | 32 | 3.6 px | 0.90 | 0.19 | 83% |
| **re-seat BIG, CLOSE 0.4-1 m** | **32** | **9.3 px** | **0.94** | **0.09** | **100%** |

**The handoff's plan, "take them off and put them back on between batches", would have been a
coin flip** (50% at 32 samples). Two free changes make it certain at the same sample count:

1. **RE-SEAT DELIBERATELY DIFFERENTLY, not just off-and-on.** Move the glasses up/down/left/right
   on the nose by several mm between batches. The mount is zip-tied, so this is easy and it is
 also realistic, it is the slippage the correction exists for.
2. **KEEP THE TARGET CLOSE, 0.4-1.0 m, for this measurement.** The term is parallax; at 2-3 m it
   is worth ~3 px and is invisible. (This is only for measuring the gain. The gain is a
   dimensionless constant, so it transfers to far targets even though its *effect* there is small.)
3. **COVER THE SAME PART OF THE FIELD AT EVERY SEATING.** If each seating looks at only one
   target, the seat is perfectly aliased with target direction and no estimator can separate them
, measured: independence drops to 1%, gain scatter to ±1.2. `reseat.py` detects this and
   refuses to answer rather than reporting a confident wrong number.
4. **SPAN THE FIELD** (item 2 above): the last run covered 5.6% of it.

## WHAT WAS BUILT

| | |
|---|---|
| `software/reseat.py` | the whole analysis: contamination, seat spread in mm, effect size, regression gain with SE + aliasing diagnostic, power table. `--check --joint --power --selftest`, 15 checks incl. 3 negative controls |
| `geometry.offscreen` / `offaxis_deg` / `geometric_pixel_raw` | the clip is now visible to callers |
| `main.py --reseat-every N` | on-screen re-seat prompt, per-batch seating index, approve blocked until confirmed |
| `Overlay.render(banner=...)` | large centred instructions for someone wearing the rig |
| `dataset.samples.seat` | migrated column + `load_seats()`; pre-existing rows read 0, which is correct |
| approve guard | refuses an off-screen target, names the angle, on screen and in the terminal |

## WHAT IS STILL UNVERIFIED: DO NOT LET THIS BE READ AS DONE

- **Nothing here was measured on a worn rig.** The XREAL was not plugged in.
- **The world-pair order is NOT verified for this session.** `--scan` gave
  `worldL=2 worldR=3 eyeL=0 eyeR=1`; last session it was `worldL=3 worldR=2`, i.e. the scan's
  guess was reversed. Run `calib_preflight.py --run` and check the `world dot` row before storing
  a single sample.
- `EYE_SHIFT_GAIN` is **still 0.0**, correctly: no data yet exists that can set it.
- The re-seat loop path has been exercised by `--input-test` and compile checks, **not by a run**.

---

# PART 2: THE HARDWARE SESSION (rig worn, XREAL connected)

Recorded as it happened.

## >>> THE BIG CORRECTION: LAST SESSION RAN IN **LOCKED** MODE, NOT FOLLOW <<<

My notes from 2026-08-03 said I had follow mode on and that this was correct. **I had LOCKED
on.** I never verified it at the time; I wrote it down as settled and then reasoned from it for
a day.

**This reaches further than the note:**
- **The 17 real calibration samples were captured in ANCHOR/3DoF**, the mode my own argument says
  makes the map ill-posed, because the optics displace the image by a head-pose-dependent amount
  before it reaches the eye. They are not a clean (features -> pixel) set.
- **`DISPLAY_FOV_DEG = 48.25` was fitted to those samples**, so it absorbed the glasses' internal
  stabiliser too. A candidate explanation for the unreconciled gap between the wall measurement
 (46.71 deg) and the data fit (48.25), previously blamed on distortion and eye position alone.
- **It explains today's regression with no software cause.** On the first run in FOLLOW mode the
  overlay followed my head movements instead of countering them. That is what follow mode plus a
  17.9 fps / 62 ms loop does. Last session the glasses' stabiliser did the counter-rotation in
  hardware at near-zero latency. **Tracking felt better in locked mode because the hardware was
  doing the work, not because anything was better calibrated.**

## THE HARDWARE FAULTS FOUND AND FIXED, IN ORDER

| # | symptom | diagnosis | evidence |
|---|---|---|---|
| 1 | all 4 rig cameras vanished when the XREAL was plugged in | hub off the bus entirely | `ioreg` listed 9 devices, no SABRENT, no `USB Camera`, no `Global Shutter Camera`. Recovered after re-plugging |
| 2 | `--scan` gave `worldL=2 worldR=3` | **REVERSED, as last session** | preflight: −42.5 px disparity at 2/3; swapped to `worldL=3 worldR=2` and the warning cleared, depth 723 mm ±4 mm, epipolar rows agreeing |
| 3 | whole bank at ~1 fps, eyeL dead | **eyeL's CABLE, not the bus** | dropping eyeL took the other three to 38 fps / 0 misses / 7.13 ms jitter; eyeL then gave 0/30 frames opened ALONE at 640x400, 640x480 and 1280x800, each read blocking a full second. **Intermittent**, it fed `--scan`, died, and came back on its own |
| 4 | preflight `world dot` at u=0.987 | detector locking a dark fitting on the white door | the target was not in frame at all, confirmed by opening the PNG |
| 5 | preflight `model lock` failing | **the rig was on a desk** | eyeR's frame showed a framed picture on a wall, cables and a desk edge. Caught by looking at the image, which is the rule |

Once worn and aimed: **preflight 6/6 READY**, dot at (0.538,0.395)/(0.504,0.383), **depth 1384 mm**,
eyeL u=0.109 (0.891 mirrored), eyeR u=0.810.

## WHAT WAS MEASURED WHEN THE RUN CAME BACK EMPTY (0 samples, no ENTER pressed)

Two hypotheses raised and **both killed by measurement**, recorded because the wrong fix was
nearly applied twice:

1. **"My off-screen banner is hiding the dot."** `Overlay.render` does suppress the red dot while a
   banner shows, which would look exactly like the reported fault. **Measured: `offscreen` fired on
   0% of 89 live frames.** Not the cause.
2. **"Deleting the 4 outliers let the learned residual survive cross-validation."** Plausible, a
   residual fitted to 13 samples spanning 5.6% of the field would extrapolate violently.
   **Measured: `W is None`, `_residual_helps = False`, pure geometry.** Not the cause.

A third scare was self-inflicted: `cal.predict` measured **438 px** of scatter against
`geometry.geometric_pixel`'s 4 px, from two runs taken minutes apart. Re-measured **on the same
frames in the same loop**, they are **bit-identical (max diff 0.000000)**, both at 7 px. The 438 px
was real head motion. *Never compare two live measurements taken at different times.*

**Everything measurable is healthy and matches last session:**

| | 2026-08-04 | 2026-08-03 |
|---|---|---|
| dot detector | sd 0.004, 40/40, 0 edge picks | "stable when well framed" |
| eye lock | eyeL **93%** (99% in band), eyeR **91%** (100%) | ~90% |
| saturation worn | 4.1% / 1.0% | 0.7% / 0.7% |
| geometry vs `cal.predict` | bit-identical, sd 7 px | pure geometry |
| IMU | ON, R² 0.99/0.85, velocity sd 0.025 frame/s at rest | same |

**So there was no software regression. The difference was the display mode**, which no measurement
of ours could have found because it happens inside the glasses.

## THE RUN SIZED AT THE MEASURED DISTANCE (1384 mm, not the assumed 0.4-1.0 m)

| protocol at 1.38 m | n | effect | SE | detects |
|---|---|---|---|---|
| plain off-and-on re-seat (~3 mm) | 32 | 2.0 px | 0.40 | **38%** |
| **deliberate ~6 mm re-seat, 4 seatings** | **32** | **4.0 px** | **0.20** | **100%** |
| deliberate ~6 mm, 6 seatings | 48 | 5.3 px | 0.12 | 100% |
| big ~9 mm, 4 seatings | 32 | 3.5 px | 0.17 | 100% |

So 1.38 m is workable **provided the re-seat is deliberate**. A plain off-and-on at that distance
fails 62% of the time.

## HOUSEKEEPING
- 4 off-screen rows purged from `data/samples.db` (ids 2, 12, 15, 16); backup at
 `data/samples_pre20260804.db.bak`. 13 remain, **and per the correction above, all 13 were
  captured in locked mode and should be treated as suspect.**
- `main.py` now starts a run at `max(existing seat) + 1`: a new run is a new seating by definition,
  and merging it into the previous one would destroy the between-seat contrast the protocol creates.
- `bank_bringup` no longer blames the bus unconditionally when a camera dies, see
  `dead_camera_advice`, with the bus case kept as a negative control.

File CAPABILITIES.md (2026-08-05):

# RIG + XREAL CAPABILITY INVENTORY

**Why this file exists.** I was underutilizing what I had already built. Capability was
scattered across 78 modules, `rig.py`, three hardware docs and several sessions' worth of
measurements, so it was genuinely hard to know what the rig could already do. Every number here is
either measured on this hardware or read from `rig.py` (the single source of truth), where
something is **assumed or unverified it says so explicitly**, because an inventory that mixes the
two is worse than none.

Regenerate the depth figures with `python3 software/depth.py --table`.

---

## 1. WHAT THE HARDWARE PHYSICALLY IS

| | spec | source |
|---|---|---|
| Glasses | XREAL One Pro, birdbath optical see-through | |
| Display to host | second monitor, **1920×1080** | measured |
| Display FOV | ~50° (used for px↔deg) | assumed, **not measured** |
| World cams | 2× ELP **AR0234**, 1920×1200 native, global shutter | |
| World FOV / res used | **70°**, 1280 px → focal **914 px** | `rig.py` |
| World baseline | **67.0 mm** (= `NOMINAL_IPD`) | `rig.py` |
| World cam position | x ±33.5, up 49.0, fwd 22.0 mm | `rig.py` |
| Eye cams | 2× **OV9281**, 1280×800 native, mono **NoIR**, global shutter | |
| Eye FOV / res | **45°**, 640 | `rig.py` (measured, was wrongly 90) |
| Eye cam position | x ±69.5, up −5.0, fwd −6.0 mm; aim down 6.0, out 3.0 | `rig.py`, as printed |
| Tracked landmark | **inner canthus** (`rig.TRACKED_LANDMARK`) | settled |
| Pantoscopic tilt | −3.5° | `rig.py` |
| Carrier | ASA/PETG, **FINAL, no printer access** | settled |
| Mount | **ZIP TIES**, not the M3 thumbscrews `ASSEMBLY.md` describes | measured 2026-08-03 |
| IMU | mount exists in CAD, **NOT wired** | |
| IR LEDs | **none wired** | settled |
| Bus | one SABRENT hub, **USB 2.0**, all four cams share it | measured |

### Hard limits, all measured
- **Four streams do not fit at native.** Three at native ≈ 37 fps is the ceiling; a fourth starves
  and stalls the bank to ~1 fps via `sync_capture`'s barrier.
- **640×400 for four streams**, *not* 640×480, see §5, this is a correctness issue, not just bandwidth.
- **No software exposure control on macOS.** AVFoundation rejects `CAP_PROP_EXPOSURE`,
  `AUTO_EXPOSURE`, `GAIN`, `BRIGHTNESS`; every `set()` returns False. Exposure is a physical lever only.
- **Full-load profile:** track 45.7 ms / sync 19.6 ms / overlay 8.8 ms = **73.6 ms/frame**, CPU 9%
 of 16 cores. The loop is **I/O-bound, not CPU-bound**, throwing quality away does not buy speed.

---

## 2. WHAT THE RIG CAN DO THAT THE GLASSES CANNOT

This is the section that matters for architecture.

| capability | rig | XREAL alone |
|---|---|---|
| Cancel head **rotation** | yes (IMU once wired, or world cams) | **yes**, near-zero latency, in the display pipeline |
| Cancel head **translation / parallax** | **yes, stereo depth** | **no**, needs a depth it cannot obtain |
| Measure **metric depth** | **yes**, 67 mm baseline | **no** built-in world cams (believed; *verify*) |
| Know **where a real object is** | yes | no, anchor holds where it was *placed* |
| Know **how the glasses sit on the face** | **yes, eye cams**, unique to this rig | no |
| Sub-50 ms motion-to-photon | no (73.6 ms loop) | yes |

**Why the glasses cannot get depth:** an IMU integrates rotation cleanly, but translation requires
double-integrating acceleration, which drifts quadratically, metres within seconds. Physics, not
firmware. A 3DoF stabiliser therefore cancels rotation *exactly* and translation *not at all*.

**Consequence (decided 2026-08-03):** keep the XREAL in **head-following (0DoF)**, never
anchor/locked, and do low-latency rotation compensation with **my own IMU** as late as possible
before drawing. Anchor mode inserts a transform we can neither query nor calibrate, which breaks
the calibration *and* the rendering.

---

## 3. DEPTH SENSING: what the stereo pair is actually good for

`software/depth.py`. Regenerate with `--table`.

| distance | disparity | depth σ (0.5 px) | needed for 1 px parallax | uncorrected parallax per 10 cm |
|---|---|---|---|---|
| 0.3 m | 204 px | 1 mm | 0.4 mm | **708 px** |
| 0.5 m | 122 px | 2 mm | 1 mm | **434 px** |
| 1 m | 61 px | 8 mm | 5 mm | 219 px |
| 2 m | 31 px | 33 mm | 18 mm | 110 px |
| 5 m | 12 px | 204 mm | 114 mm | 44 px |
| 20 m | 3.1 px | 3.3 m | 1.8 m | **11 px** |
| 100 m | 0.6 px | 82 m | 45 m | 2 px |

**The design result:** stereo depth error and the depth accuracy *required* for sub-pixel parallax
**both scale as Z²**, so their ratio is **constant with range**, 1.80 at a realistic 0.5 px
disparity precision, 0.90 at an optimistic 0.25 px. The 67 mm baseline is matched to the task at
*every* distance, not merely up close. "Stereo dies at range" is only a problem if you forget that
distant objects are correspondingly forgiving of depth error.

**Honest reading:** at 0.5 px the ratio is 1.8, i.e. **~2 display px** of parallax error, fine to
look at, not "sub-pixel". Only the optimistic 0.25 px reaches sub-pixel, with 10% headroom. Both
are reported; neither is hidden.

**Refusals are first-class.** `StereoDepth.measure` returns `ok=False` with a named cause for an
epipolar violation, a **negative disparity** (reversed pair, never `abs()`'d, that bug let a
swapped pair pass a full preflight at 2054 mm), or disparity below the noise floor.

---

## 4. SOFTWARE CAPABILITY INVENTORY (78 modules)

**Perception**
- `depth.py`, metric stereo depth + uncertainty + refusal *(new 2026-08-03)*
- `world_mesh.py`, stereo VO/mesh tracking, `triangulate_stereo`, Kabsch. **0 map points on real
 frames**, a geometry problem (rotation-dominant motion, far landmarks vs 67 mm baseline), not a bug
- `world_memory.py`, rolling TSDF, forgets old geometry
- `people_track.py`, detect + track people in 3D
- `dot_detector.py`, calibration target; `detect_pair()` picks the stereo pair **jointly**
- `canthus_net.py`, learned inner-canthus landmark, pure numpy 13 ms/frame, + mount fiducial
- `pupil_tracker.py` / `pupil_sensor.py`, IR pupil + glint (**no IR LEDs wired**)
- `blink.py`, `eye_tracker.py`, closure detection, classical corner tracker
- `imu.py`, `imu_serial.py`, IMU filter + XIAO serial feed (**not wired**)

**Calibration**
- `calibrator.py`, `main.py`, the learning core and live loop
- `calib_preflight.py`, six preconditions, names the failing one
- `eye_check.py`, worn-rig eye diagnostic *(new)*
- `canthus_data/label/train/auto`, corpus → labels → model
- `intrinsics.py`, checkerboard per-camera calibration
- `display_calib.py`, measure real XREAL FOV + distortion
- `kappa*.py`, `vernier.py`, angle-kappa study, hyperacuity alignment
- `preset.py`, `identify.py`, `match.py`, `complete_geometry.py`, per-user eye geometry ID

**Rendering**
- `overlay.py`, the AR surface (black = transparent)
- `anchor.py`, world-locked projection
- `content_anchor.py`, surface placement + occlusion + persistence
- `avatar.py`, `augment_rig.py`, the people→monkeys runtime

**Infrastructure**
- `cameras.py`, `sync_capture.py`, `snapshot.py`, `bank_bringup.py`, `connect.py`, `rig_view.py`
- `perf.py`, frame budget, adaptive quality with an **effectiveness probe** (reverts a down-step
 that does not buy frame time, this rig is I/O-bound)
- `autoexpose.py`, per-role control (**inert on macOS**, see §1)
- `verify_all.py`, the release gate, **40 checks**

**Simulation**, `autosim.py`, `optics.py`, `anatomy.py`, `rig.py`, `megarun.py`, `accuracy_map.py`,
`pixel_sweep.py`, `autotrain.py`, `realtime.py`, `stereo_test.py`, `binocular.py`

---

## 5. UNDER-USED RESOURCES: the actual point of this file

1. **The IMU is unwired and solves THREE problems at once:** late-stage reprojection latency
   (73.6 ms loop = **283 px** of lag at a normal 100 °/s glance), `WorldTracker`'s 0 map points,
   and the rotation-dominant motion the SLAM literature says breaks stereo init. Mount is in the
   CAD. **Highest-value unbuilt work in the project.**
2. **The world cams were never used as a depth sensor** until `depth.py`, only for the dot and a
   mesh that returns 0 points. Depth is the rig's unique advantage over the glasses.
3. **640×480 wastes 70% of the eye sensor.** It is a **CROP** at scale 1.00, not a downscale , 
   eyeL's 640×480 covers only x[288..928], y[50..530] of 1280×800. `640×400` is a true 2× downscale
   keeping the **full FOV**, at **less** bandwidth. Fixed in `cameras.py`, `rig_view`, `eye_check`.
4. **Native resolution is available for 2-camera work.** The bus limit applies to four streams; the
   corpus is captured at full 1280×800.
5. **A pupil head on the canthus net is free**, auto-labelled by `pupil_tracker` (96–100% reliable).
   Literature: presence/absence 92.8% → 99.6%, which is exactly the weak closed-eye head. Do **not**
   expect registration gains (`eyetracker.py`: 9.9 px corner-only vs 10.1 px +pupil).
6. **The mount is a free fiducial.** Bolted to the camera, so it lands on the same pixels regardless
 of the face, `canthus_net.MountAnchor` uses it for drift. With a **zip-tie mount that is not
   repeatable between sessions**, making the plausibility band **mount-relative** rather than
   sim-derived would cancel seating entirely.
7. **Global shutter on all four cameras**, unexploited. Enables motion-robust capture and, with
   the IMU, proper rolling-shutter-free reprojection.
8. **`perf.py`'s effectiveness probe** already knows the loop is I/O-bound; the real speed lever is
   fewer/smaller reads, not lower quality.

---

## 6. KNOWN-UNVERIFIED: do not treat as fact
- **Display FOV ~50°** is assumed. `display_calib.py` exists to measure it and has not been run.
- **XREAL has no built-in world cameras** (XREAL Eye believed to be a clip-on), reasoned, not verified.
- **Whether follow mode is rigid or damped.** If damped, the image lags during fast head turns,
  which would fit "big head shifts make it not work". Unmeasured.
- **The 0.09 eye asymmetry is real geometry** (two independent labelling passes, gap 0.102 and
 0.084), but *why* the rig is asymmetric is unknown, and `rig.py`'s symmetric prior does not
  describe it.
- **The accuracy corpus is STALE**, `data/mega_prior*`, `calibration_db.npz`, the 1.88 px
  `accuracy_map` figure were all generated at `EYE_FOV=90` tracking the **outer** canthus.

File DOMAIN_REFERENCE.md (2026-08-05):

# DOMAIN REFERENCE: eye anatomy, eye tracking, optics, and overlay mechanics

Written 2026-08-03 to give myself depth across the fields this rig sits in. Organised
around **what changes a decision here**, not around textbook completeness. Every section ends with
what it implies for my hardware.

Three findings up front, because they matter most:

1. **The canthus approach is the literature's answer to slippage, not a workaround.** 3D
   model-based trackers compensate for headset slip; 2D video-based ones have *no known solution*.
   We built the right thing for the right reason.
2. **The correct rendering viewpoint depends on what you are optimising**, and our design has
   already implicitly chosen. That choice explains a measurement we took but never accounted for.
3. **Display FOV is not a constant.** Pupil swim makes it vary with eye position in the eyebox , 
   which means `geometry.DISPLAY_FOV_DEG = 50.0` is wrong in a way no single number can fix.

---

## 1. THE EYE: the anatomy that actually enters the maths

### 1.1 Two axes, not one
- **Optical axis**, the line through the eyeball centre, corneal centre, iris centre and pupil
  centre. It is what a camera can *see*.
- **Visual axis**, the line from the **fovea** through the corneal centre to the fixation point.
  It is where the person is actually looking.
- They are **not the same line.** The offset is **angle kappa** (its components alpha and beta),
  typically **~5° horizontal and ~1.5° vertical**, and it **varies between individuals**.

**Why it matters:** any tracker that measures the pupil measures the *optical* axis. Converting to
gaze requires kappa, which is a per-person constant needing at least single-point calibration.
This is exactly what `kappa.py` and `KAPPA.md` are about, and why the project measured
cross-distance error of 13 px → 2.4 px with multi-distance calibration.

### 1.2 The eye rotates around a point ~10 mm behind the pupil
The centre of rotation sits roughly **10 mm behind the pupil**. So as gaze changes, the **pupil
sweeps an arc of ~10 mm radius** while the rotation centre stays put.

This is the single most consequential fact in §3.

### 1.3 The canthus
The inner canthus (medial, tear-duct side) is a **skin/soft-tissue landmark fixed to the skull**,
not to the globe. It moves with the face and not with gaze. `rig.TRACKED_LANDMARK = "inner"` and
the measured pupil-correlation drop from **+0.99 (classical tracker) to +0.19 (learned model)** is
precisely the property being exploited: a face-fixed reference is only useful if it is genuinely
gaze-independent, and that number is the proof it is.

Limitation to keep honest: it is **soft tissue**. `rig.SOFT_TISSUE_SD = 0.15 mm` is a
"holding still" placeholder, and squinting, talking or smiling exceed it. Hence the standing
instruction to hold a neutral face while calibrating.

---

## 2. EYE TRACKING: the methods, and where each breaks

### 2.1 The dominant method: PCCR (pupil–corneal reflection)
IR LEDs make **glints** on the cornea; the vector between pupil centre and glint gives gaze.
**Dark pupil** (off-axis illumination, pupil appears dark) vs **bright pupil** (on-axis, retroreflection
makes it glow), many systems alternate to segment the pupil robustly by differencing.

Universal in commercial trackers, and IR is used for a reason that is **not** about the pupil: an
IR bandpass filter makes the eye image **independent of ambient light**. Our rig has no IR LEDs, no
filter, and **no software exposure control on macOS**, which is why exposure is a physical lever
here and why blowout has repeatedly wrecked measurements.

### 2.2 2D vs 3D, and the finding that matters most
- **2D / appearance-based**, regress gaze directly from image features. Simple, but the mapping is
  only valid for the head-to-camera geometry present at calibration.
- **3D / model-based**, reconstruct an eye model (corneal centre, optical axis) in 3D, then apply
  kappa.

**The slippage result:** eye trackers using **3D models of the eye can compensate for slippage**,
and there is **no known solution for slippage compensation in 2D video-based eye tracking.**
Measured slippage penalties in the literature run **0.8–3.1° of added gaze error**, and slippage
happens constantly, pushing glasses up the nose, brushing hair, talking.

**This is the strongest external validation of our architecture.** We do not track gaze at all; we
track a **face-fixed landmark to recover the glasses' pose on the head**, which is the slippage
term itself. With a **zip-tied, non-repeatable mount**, that is not a nice-to-have, it is the only
thing standing between us and a calibration that expires the moment the rig shifts.

### 2.3 What a canthus tracker cannot do
It gives **glasses-relative head geometry**, not gaze. So it cannot supply the entrance-pupil
position for a given fixation (§3), cannot apply kappa, and cannot know where the user is looking.
My own `eyetracker.py` study measured the consequence honestly: corner-only **9.9 px** vs
+pupil **10.1 px** for registration, i.e. **no registration gain from adding the pupil.** §3
explains *why* that result is not surprising.

---

## 3. THE VIEWPOINT QUESTION: where the virtual camera actually goes

This is the deepest item here and it has a real consequence for us.

To render an overlay you need a **projection centre**: the point the virtual camera sits at. There
are three candidates and they are not interchangeable:

| candidate | property | cost |
|---|---|---|
| **Entrance pupil** | **highest angular accuracy** | **moves with gaze** (~10 mm arc, §1.2) |
| **Centre of rotation** | **gaze-independent**, stable | slightly worse angular accuracy |
| Optics' nodal point | matches the lens design | not where the eye is; mismatch causes distortion |

The literature states it directly: depending on whether **angular** or **positional** accuracy
matters, either the centre of rotation or the centre of the entrance pupil is chosen, and **the
entrance pupil yields higher angular accuracy.** Distortion, separately, results from the pupil
sitting away from the **nodal points of the optics**.

### What this means for our rig
**We render from a gaze-independent point, because that is the only thing a canthus can give us.**
That is a real choice with real consequences:

- ✅ It is stable, needs no gaze tracking, and does not require kappa.
- ✅ **It explains the 9.9 vs 10.1 px result.** Adding a pupil feature did not help registration
 because our whole formulation is built around a gaze-independent viewpoint, the pupil's
  information has nowhere to go. That measurement was never a fluke; it is structural.
- ❌ It gives up angular accuracy at **large gaze angles**, where the entrance pupil has swung
  furthest from the rotation centre. Worst case: a 10 mm displacement. At **0.5 m** that subtends
  **~1.1°** (44 px); at **20 m**, **~0.003°** (negligible).

**And that maps onto the stated goal.** The end goal is people and cars **far away**, where the
entrance-pupil-vs-rotation-centre distinction is worth ~0 px. **The design choice is well matched
to the application**, near-field content is where it would cost, and near-field is not the target.

---

## 4. THE DISPLAY: birdbath optics, and why FOV is not a number

The XREAL One Pro is a **birdbath**: a display panel, a beamsplitter, and a spherical
mirror/combiner. It is the same family as XREAL Air, Rokid Air, Huawei Vision Glass.

Key parameters, all of which we currently treat as constants and none of which are:
- **Eye relief / exit pupil distance**, the design distance from eyepiece to eye.
- **Eyebox**, the region the eye may occupy and still see the full FOV. Move outside it and the
  image vignettes or vanishes.
- **Pupil swim**, **aberrations across the pupil mean the image distorts as the eye moves within
  the eyebox.** The literature is explicit that this **exists in all near-to-eye display systems**.

### The uncomfortable implication for us
`geometry.DISPLAY_FOV_DEG = 50.0` is (a) **assumed, never measured**, and (b) **not even a
constant**, the effective mapping from angle to pixel varies with where the eye sits in the
eyebox. A single scalar cannot represent it.

**But our architecture can absorb this, and here is the part worth noticing:** the learned residual
takes the **eye-corner features as inputs**. Those features encode *where the glasses sit relative
to the eye*, which is exactly the variable pupil swim depends on. So a residual model on top of
geometry can in principle learn a **position-dependent** correction that no fixed FOV constant
could. That is a genuine architectural argument for geometry-plus-residual over either alone, and
it was not the reason we adopted it.

**Action:** `display_calib.py` exists to measure real FOV and distortion (K1/K2) and **has never
been run.** It is the highest-value unrun tool in the repo.

---

## 5. REGISTRATION ERROR: the budget, and what dominates

From Holloway's end-to-end analysis (already in `LATENCY_AND_TRACKING.md`, restated because it
frames everything above):

1. **System latency, the largest single term.** Unlike the rest, it scales with **head angular
   velocity**, so it is invisible standing still and dominant in motion. We measure 62 ms against a
   modern target of <20 ms.
2. **Eye position / viewpoint error**, §3. Bounded by ~10 mm, and negligible in the far field.
3. **Optical distortion**, §4. Currently unmodelled and unmeasured.
4. **Tracker noise**, measured ~0.003–0.004 frame-units on our dot detection.
5. **Calibration/parameter error**, what the sample-driven fit addresses.

**Priority follows directly:** latency first (in progress), then measure the display, then worry
about the rest. Chasing calibration accuracy while (1) and (3) are unaddressed is optimising the
smallest terms.

---

## 6. CONSOLIDATED IMPLICATIONS FOR THIS RIG

**Validated by the literature, keep doing:**
- Tracking a **face-fixed landmark for slippage compensation**. This is the 3D-model approach, and
  2D methods have no answer to slippage. With a zip-tied mount it is essential.
- **Gaze-independent viewpoint.** Well matched to a far-field application; costs ~nothing at 20 m.
- **Geometry as backbone + learned residual.** §4 gives an additional, stronger reason: the
  residual has access to eye-position features and can therefore learn pupil-swim-like effects.

**Corrected or newly explained:**
- The **9.9 vs 10.1 px pupil result is structural**, not a null finding, a gaze-independent
  formulation has no way to use gaze information.
- **Display FOV is not a constant**, so no single `DISPLAY_FOV_DEG` is right; the residual must
  carry the position-dependent part.

**Now clearly worth doing, in order:**
1. **Finish latency work**, the dominant term (§5).
2. **Run `display_calib.py`**, measure real FOV and distortion. It is written, unrun, and feeds
   the second-largest unmodelled term.
3. **Wire the XREAL IMU**, serves latency *and* `WorldTracker`.
4. **Pupil head on the canthus net**, worth it for **blink/presence detection and geometry ID**,
   explicitly *not* for registration (§3 says why it cannot help there).

**Known-unverified, do not treat as fact:**
- Display FOV ~50° (assumed), eyebox size and eye relief (unmeasured), our actual position within
  the eyebox, and whether the One Pro's follow mode is rigid or damped.

---

## 7. HOW OTHERS FIX THE LIGHTING PROBLEM (researched 2026-08-03)

My room is lit from one side, so `eyeL` shadows while `eyeR` does not, mean 94 vs 49, and
`eyeL` fluctuating 94→39 within minutes. That is an ordinary operating condition, not a fault, and
the field has three answers. We have implemented the cheapest; the other two are the real ones.

### 7a. WHAT WE DID: normalise the input (free, done, measured)
Median-normalise every frame to the corpus median before inference. **21 px flat across a 3×
brightness range**, versus 715 px unnormalised at ×0.34. See §4 of `canthus_net.predict`.

**Limit:** it corrects a LEVEL, not a GRADIENT, and cannot invent signal. `eyeL` at median 11/255
is past saving by any preprocessing.

### 7b. WHAT THE ML LITERATURE DOES: augment the training data
Every serious CNN eye tracker trains with **photometric augmentation**, because a model trained in
one lighting band is brittle outside it, exactly our failure. Published recipes
([Improving real-time CNN-based pupil detection through domain-specific data augmentation](https://dl.acm.org/doi/10.1145/3314111.3319914),
ETRA 2019) use:

- **random gamma** γ ∈ {0.6, 0.8, 1.2, 1.4}
- **exposure offset** up to **±25 levels**
- **Gaussian blur** 2 ≤ σ ≤ 7
- random brightness/contrast, plus noise

Related work ([EllSeg](https://arxiv.org/pdf/2007.09600),
[LEyes](https://arxiv.org/pdf/2309.06129)) reports the same theme: models tested on high-appearance-
variability data benefit from multiset training, while narrow-band training generalises only within
its band.

**Directly applicable to us.** Our corpus spans **139–161**, a range of 22, which is precisely a
narrow band. Retraining with gamma and exposure jitter costs **no new labelling** (augment the
frames we already have, keep the same 87 clicks) and would harden the model where normalisation
cannot. **This is the cheapest remaining robustness win and should be done when the model is next
retrained.**

### 7c. WHAT THE HARDWARE PEOPLE DO: and it is the real answer
**Active NIR illumination plus a matched bandpass filter**, which is universal in commercial
head-mounted eye tracking. The point is not the pupil: it is that **the eye image stops depending
on the room at all.**

- **850 nm** is the standard choice, among the brightest IR LED wavelengths, and just outside
  visible so it does not distract.
- A **narrow 850 nm bandpass filter** between lens and sensor blocks visible light, so sunlight,
  lamps and side-lighting simply do not reach the sensor. Transmission ≥85–90%
  ([Edmund 54809](https://www.edmundoptics.com/p/narrow-nir-850nm-c-mount-bandpass-filter/54809/),
  [MidOpt BP850](https://fjwoptical.com/products/bp850)).
- Consumer headsets do exactly this: the user sees a display while the tracking cameras see a scene
  lit only by invisible NIR, **regardless of display content or ambient light**
  ([KUPO Optics guide](https://www.kupooptics.com/en/blogs/optics-playbook/ir-pass-filters-vr-ar-tracking-guide)).

**Why this matters so much for us specifically:** our eye cams are **NoIR** (IR-sensitive, no IR-cut
filter), already the right sensor, and macOS gives us **no software exposure control at all**
(AVFoundation rejects every `set()`). So we have neither of the two software levers a normal system
would use, and the one hardware lever that removes the problem entirely is unfitted. IR LEDs are
listed in `WIRING.md` and `SAFETY.md` but **none are wired**.

### 7d. Order of value for this rig
1. **Photometric augmentation at next retrain**, free, no labelling, hardens the 139–161 band.
2. **Fill light on the right side**, LED not daylight; getting `eyeL`'s median from 11 to ~40 puts
   it inside what normalisation already handles.
3. **850 nm LEDs + bandpass filters**, the actual fix, and the one that makes lighting irrelevant
   forever. Note it also delivers the pupil/glint path the incoming pupil cams need, so the two
   upgrades share the same hardware work.

**Safety note, non-negotiable:** IR is invisible, so the blink reflex does not protect the eye.
`SAFETY.md` and `WIRING.md` already specify the power-anomaly cutoff and exposure limits, follow
them before energising anything near the eye.

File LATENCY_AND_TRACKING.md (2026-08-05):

# HOW EVERYONE ELSE SOLVES THIS: and what it means for our rig

Written 2026-08-03 after a session spent fighting overlay lag and jitter by tuning filters. The
short version: **filtering is the wrong class of tool for latency, and the field has known this
since the 1990s.** A filter can only trade lag against jitter. The standard answer is to
**predict forward, then reproject late**, which removes lag *without* adding jitter, because it
adds information rather than smoothing it away.

Our measured numbers are in §6. Everything before that is what other people do.

---

## 1. THE FRAMING: latency is not one error among many, it is THE error

Holloway's *Registration Error Analysis for Augmented Reality* (Presence 6, 1997) did the
end-to-end error budget for an optical see-through HMD and found **system delay is the largest
single contributor to registration error**, larger than tracker noise, larger than calibration
error, larger than optical distortion. The reason is simple and applies exactly to us: every other
error is roughly constant, while the latency error is **proportional to head angular velocity**.
Stand still and a laggy system looks perfect. Turn your head and it is the only error you can see.

That reframes our whole session. We measured 196 ms and treated it as a tuning problem. In this
literature 50 ms was considered typical for a mid-range 1990s system, and modern XR targets
**under 20 ms motion-to-photon**. We were 10x off the modern target and calling it smoothing.

**Consequence for us:** effort spent on calibration accuracy is wasted while latency dominates.
My instinct, that this must run perfectly before anything else can be done, matches the
literature exactly.

---

## 2. WHAT EVERYONE ACTUALLY DOES: predict, then reproject late

Two distinct mechanisms, usually stacked. Neither is a filter.

### 2a. POSE PREDICTION (removes lag before rendering)
Estimate where the head **will be** when the photons actually land, and render *that* pose. The
look-ahead equals the measured end-to-end latency. This is why every XR runtime's tracking API
takes a **target display time** rather than "now", OpenXR's `xrLocateViews` is explicitly
predictive, and the runtime is expected to extrapolate.

The reference open implementation to read is **[`fraunhoferhhi/pred6dof`](https://github.com/fraunhoferhhi/pred6dof)**
(Gül et al., ACM MM 2020), which is a Kalman-filter 6DoF head-motion predictor evaluated at
**20/40/60/80/100 ms** look-ahead against an autoregressive baseline and a no-prediction baseline,
over 14 real HoloLens motion traces. Reported: the Kalman predictor beats autoregression by
**~0.5° at 60 ms look-ahead**. Structure is small and readable, `runners.py` holds the predictors,
`evaluator.py` the MAE/RMSE metrics, and the traces are resampled to 200 Hz.

The critical property, and the reason this beats filtering: **prediction removes lag without
adding jitter.** A filter must smooth to reduce noise, and smoothing *is* lag. A predictor
extrapolates, so it can be simultaneously smooth and current. It fails differently, badly at
turn onsets and reversals, where extrapolation overshoots, which is why the recent work
([Predictability-Aware Motion Prediction, arXiv 2507.13179](https://arxiv.org/html/2507.13179))
is about knowing *when* the motion is predictable and backing off when it is not.

### 2b. TIMEWARP / LATE-STAGE REPROJECTION (removes the lag that remains)
Just before the display scans out, take the frame that was already rendered and **warp it using
the freshest tracker data**. Rotation-only warp is a cheap 2D homography, which is why it is
affordable at field rate. This is Asynchronous Timewarp (ATW) on the consumer headsets, and the
literature describes early+late two-stage variants that additionally fix pose error in the
received frame and cut colour separation.

The key insight for us: **the warp runs at display rate and is decoupled from the render loop.**
Our render loop is 17.9 fps; a reprojection stage does not care, because it only needs the latest
rotation and the last completed frame. That is precisely the structure that makes a slow camera
loop acceptable.

Open-source runtime to read: **[Monado](https://monado.freedesktop.org/)**, the FOSS OpenXR
runtime, `src/xrt/compositor` is where distortion and reprojection live, `src/xrt/auxiliary` has
the tracking/filtering utilities. It is the most directly readable production implementation of
this whole stack.

---

## 3. THE SENSOR ARCHITECTURE: fast IMU + slow camera, fused

Nobody tracks head motion at camera rate. The universal pattern is:

- **IMU at 100–1000 Hz** → propagation. Gyro integrates cleanly over short intervals; this is what
  gives low-latency rotation.
- **Camera at 10–60 Hz** → correction. Fixes the drift the IMU accumulates, and supplies absolute
  position/scale.

This is Visual-Inertial Odometry. The three open implementations worth reading, all with published
comparisons ([arXiv 2108.01654](https://ar5iv.labs.arxiv.org/html/2108.01654)):

| system | approach | note |
|---|---|---|
| **[OpenVINS](https://docs.openvins.com/)** | MSCKF (filter): IMU propagates, camera updates | cleanest reference for the filter formulation; best-in-class monocular |
| **[VINS-Mono / VINS-Fusion](https://github.com/HKUST-Aerial-Robotics/VINS-Mono)** | sliding-window optimisation | IMU pre-integration with bias correction, online extrinsic calibration, loop closure |
| **Basalt** | graph-based | fastest of the three; best stereo accuracy |

**This is the same conclusion the project already reached from the other direction.** My earlier
notes record that `WorldTracker` builds 0 map points because stereo initialisation degrades under
rotation-dominant motion with far landmarks, and that an IMU is the standard fix. The latency work
and the SLAM work want *the same component*.

---

## 4. FILTERING: what it is legitimately for

Filtering is not useless, it is for **sensor noise on an interaction signal**, not for latency.

The One Euro filter (Casiez, Roussel & Vogel, CHI 2012) is the standard here and is what we now
use: `cutoff = min_cutoff + beta * |velocity|`, smoothing hard when still and opening up when
moving. It is ~20 lines and is in `software/smoothing.py`.

But note what it does **not** do: it cannot remove the 56 ms our pipeline takes to capture and
process a frame. No causal filter can. That is what §2 is for.

---

## 5. THE CALIBRATION SIDE, for completeness

- **SPAAM** (Tuceryan & Navab), align a marker to a single 3D point from many viewpoints, solve
  the projection. This is what our calibration loop is. Known weakness: user alignment noise, and
  the need for varied viewpoint *and distance*.
- **INDICA** (Itoh & Klinker, 3DUI 2014), split calibration into an **offline display part** and
  an **online eye-position part**, so a re-seat does not require recalibration. Directly relevant
  to our zip-tied, non-repeatable mount.
- **Corneal-imaging calibration** (Itoh & Klinker, TVCG 2015), uses the display's reflection on
  the cornea, removing landmark tracking entirely.
- **Parallax-free OST-HMD work** ([PMC7806030](https://www.ncbi.nlm.nih.gov/pmc/articles/PMC7806030/))
, conditions under which short-focal-distance OST displays mitigate parallax registration error.

---

## 6. WHAT THIS MEANS FOR *THIS* RIG, with our measured numbers

Measured on hardware 2026-08-03:

| quantity | value |
|---|---|
| full pipeline (4 cams + dot pair + 2 canthus) | **55.9 ms/frame = 17.9 fps** |
| overlay latency after the smoothing fix | **62 ms** |
| overlay latency before it | 196 ms |
| lag at a gentle 30 °/s head turn | 72 px (was 225 px) |
| modern XR motion-to-photon target | **< 20 ms** |

**We are ~3x over the target, and no amount of filter tuning will close it.** The remaining 56 ms
is capture-and-process; a causal filter cannot remove it, and the One Euro filter is already at the
point where reducing jitter costs lag back.

### The three things the field says to do, in order of value to us

1. **PREDICT FORWARD BY THE MEASURED LATENCY.** We know the number (62 ms). The literature says
   head motion is predictable at that horizon and that a Kalman predictor at 60 ms look-ahead is
   accurate to well under a degree. This is a software change with no new hardware, and
   `pred6dof` is a readable reference. **Highest value per unit of work.**
2. **USE THE XREAL'S IMU FOR LATE-STAGE ROTATION CORRECTION.** Already established as readable:
   the glasses enumerate as USB VendorID 13080 with HID interfaces, and there is working prior art
   (`SamiMitwalli/One-Pro-IMU-Retriever-Demo`, `adidoes/xrealair-sdk-macos`). An IMU at 100–1000 Hz
   against our 17.9 fps loop is exactly the fast/slow split in §3. **This is the piece that makes
   the slow camera loop stop mattering.**
3. **THEN the camera loop speed is nearly irrelevant**, which is the whole point of the
   architecture. Do not optimise the vision pipeline for latency before doing 1 and 2.

### What we should stop doing
- **Tuning filters to fix lag.** We now have the measurement to know it cannot work.
- **Treating calibration accuracy as the bottleneck** while 62 ms of latency dominates the
  registration error (§1). Holloway's analysis says the latency term swamps the rest under motion.

### Honest caveat
Prediction has a characteristic failure: it overshoots at motion onset and reversal, which will
look like a *different* kind of instability from what we have now. The recent literature is
explicitly about detecting when motion is unpredictable and reducing the look-ahead then. Expect
to need that, and expect the first naive implementation to feel worse at turn reversals before it
feels better overall.

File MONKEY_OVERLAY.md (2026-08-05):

# Real-world overlay on moving people ("turn people into monkeys")

A world-locked AR effect: detect and track people through the world cameras, place a monkey on
each one, and keep it glued to them as **they and your head move**, rendered through the
**calibrated** glasses.

```bash
cd ~/ar-eye-calibration/software && source .venv/bin/activate
python3 augment_rig.py --selftest     # whole pipeline, headless (no cameras)
python3 augment_rig.py --run --imu    # live on the glasses (needs calibration + cameras)
python3 avatar.py --save-texture ~/Desktop/monkey.png   # see the placeholder sprite
```

## Precondition (important)

**The glasses must already be calibrated.** This runtime *consumes* the calibration, it does not
create it. Before it works you need:

1. `connect.py --auto && --identify`, cameras mapped to roles.
2. The human-in-the-loop calibration loop run (`main.py`) so the pixel map (`calibrator`) is
 trained, this is what turns "a person at 3D point X" into "the right display pixel."
3. A rigid, bring-up-tested rig (`rig_test.py`).

## The pipeline (per frame)

| Stage | Module | What it does |
|---|---|---|
| synchronized grab | `sync_capture` | all cameras captured together, with jitter |
| adjust image | `autoexpose` | keep the world frames well-exposed + sharp |
| head pose in world | `world_mesh` | where the glasses are in the world (VO + IMU) |
| find + track people | `people_track` | detect in both world cams → stereo 3D → **stable IDs**, dead-reckon through dropouts |
| world-lock | `anchor` | 3D world point → display pixel via mesh pose + the **calibrated map** (parallax-correct, uses stereo depth) |
| monkey | `avatar` | pose/scale/orient a monkey billboard to each person, depth-sorted for occlusion |
| display | `augment_rig` | composite (black = transparent) → AR display |

Because every corner of each monkey is a **world point re-projected each frame**, the monkeys stay
locked to the people. A fixed display pixel would smear off as the head turns (proven in
`anchor.py --selftest`: 252 px drift over one head move, 0.00 px with re-projection).

## Honest scope: what's real, what's a placeholder

- **Registration + tracking are complete and proven in sim** (stereo 3D recovery, stable IDs,
 occlusion coasting, parallax-correct world-lock, all in the release gate). This is the hard part.
- **Detector**: the default is OpenCV's built-in HOG pedestrian + Haar face (no downloads), it
  *works* but is modest (misses odd poses, ~real-time). Drop a YOLO/MediaPipe model into the
  `detect(frame) -> [Detection]` seam for robust, full-pose detection. The geometry is
  detector-agnostic.
- **"Realistic" monkey**: the asset is a **procedural billboard sprite** (a placeholder, see
  `monkey_sprite.png`). Realistic means swapping in (a) a real textured PNG via
  `MonkeyAvatar(texture=...)`, or (b) a **rigged 3D monkey** articulated to body-pose keypoints
  (feed keypoints as extra anchor points). A billboard already tracks position/scale/orientation;
  articulation (matching limb motion) needs a body-pose model.
- **Display FOV**: the AR display is ~50°, a person closer than ~3.3 m won't fit head-to-toe, so
  the monkey is **clipped** to the display window (their visible part still shows).
- **Nothing has run on hardware yet.** All sim-validated.

## Making it look good later

1. Swap the sprite for a real monkey texture / 3D model.
2. Add a body-pose model (MediaPipe Pose / YOLO-pose) → articulate the monkey to the person's limbs.
3. Add face-landmark alignment so the monkey face maps onto the real face (head turns, expressions).
4. Temporal smoothing on the monkey pose (already have velocity prediction) to kill jitter.

The registration backbone doesn't change for any of these, they're all asset/detector swaps at
the seams this pipeline already exposes.

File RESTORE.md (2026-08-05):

# Restore / backup guide: AR eye-calibration project

This is the full project: the **XREAL One Pro eye-calibration rig**, parametric CAD, the
simulation + calibration + capture + world-mesh/overlay software, firmware, wiring/assembly
docs, and the parts list. This file explains how to restore it on any computer.

## What's in the backup archive

- **Everything committed to git** (full history, `.git/` is included).
- `cad/`, OpenSCAD parametric carrier + LED bracket (`xreal_one_mount.scad`).
- `software/`, all Python (sim, calibrator, capture, world_mesh, people_track, avatar,
  augment_rig, verify_all, etc.) + `requirements.txt`.
- `firmware/`, the XIAO IR-strobe firmware.
- Docs: `README.md`, `HARDWARE_BRINGUP.md`, `WIRING.md`, `ASSEMBLY.md`, `ORDER_LIST.md`,
  `EYE_TRACKING.md`, `SAFETY.md`, `KAPPA.md`, `MONKEY_OVERLAY.md`, `RIGID_MOUNT_BUILD.md`, …
- `data/`, the **distilled** artifacts kept (trained prior/identifier `*.npz`, `meta.db`,
  `calibration_db.npz`, `pixel_map.npz`, templates, checkerboard, logs).
- `_printable_stls/`, the ready-to-print parts (also regenerate from `cad/`, see below).

## What's intentionally EXCLUDED (regenerable: to keep the archive small)

| Excluded | Size | How to regenerate |
|---|---|---|
| `software/.venv/` | ~200 MB | `pip install -r requirements.txt` (below) |
| `data/mega_samples.npz` | ~227 MB | `python3 software/megarun.py 100000` (~2.5 h; research only, not needed to build) |
| `data/pixel_sweep_guesses.bin` | ~38 MB | `python3 software/pixel_sweep.py` (research only) |
| `data/*.old_geom_*`, `*.old_fwd12` | ~36 MB | superseded DB backups; not needed |
| `__pycache__/`, `*.pyc` | | recreated on run |

None of the excluded files are needed to **build the hardware** or run the release gate.

## Restore on another computer

1. **Extract** the archive:
   ```
   tar xzf ar-eye-calibration-backup-*.tar.gz
   cd ar-eye-calibration
   ```
2. It's a live **git repo** with full history:
   ```
   git log --oneline | head        # see the commit history
   ```
3. **Recreate the Python environment** (needs Python 3.9+):
   ```
   cd software
   python3 -m venv .venv && source .venv/bin/activate
   pip install -r requirements.txt        # numpy + opencv
   ```
4. **Verify everything works** (headless, no hardware):
   ```
   python3 verify_all.py --fast           # should end: RELEASE GATE: ALL CHECKS PASS
   ```

## Where to start (entry points)

- **Build the rig:** `ORDER_LIST.md` (parts) → print `cad/` → `ASSEMBLY.md` + `WIRING.md`.
- **Bring up the cameras on a Mac:** `HARDWARE_BRINGUP.md`
  (`connect.py` → `rig_test.py` → `live_rig.py`).
- **The overlay app:** `MONKEY_OVERLAY.md` (`augment_rig.py`).
- **The science / accuracy:** `README.md`, `KAPPA.md`, `software/AUTOTRAIN.md`.

## Regenerate the printable STLs from CAD

```
OSC=~/Applications/OpenSCAD.app/Contents/MacOS/OpenSCAD    # or your openscad path
$OSC -D 'part="carrier"'     -o carrier.stl     cad/xreal_one_mount.scad
$OSC -D 'part="led_bracket"' -o led_bracket.stl cad/xreal_one_mount.scad
```

## Making a fresh backup later

From the project root, re-run the same archive command (see the parent folder), or simplest , 
because it's all in git, `git bundle create ../ar-eye-cal.bundle --all` makes a single-file,
full-history backup you can restore with `git clone ar-eye-cal.bundle`.

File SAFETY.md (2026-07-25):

# Safety review, 6-cam binocular clip-on (2026-07-03 design)

Hazard-by-hazard review of the CURRENT design (removable clamp carrier, L-booms, IMU tower,
separate IR rings). IR specifics live in `EYE_TRACKING.md §3/3a`; electrical interlocks in
`WIRING.md`. This file is the consolidated checklist, walk it before every wear session
during bring-up, then before any change.

## 1. IR / eye (the governing hazard) , engineered, verify at build
- 940 nm only, ≥10 mm rim standoff (enforced by an `assert` in the CAD), recessed baffles,
  per-LED resistor 330-470 Ω (≈5-15 mA), 300 mA polyfuse branch, low-side MOSFET with
  default-OFF gate + watchdog. **NEW RULE 7 (EYE_TRACKING §3): resistor current must be
  safe for CONTINUOUS stuck-on**, never lean on the strobe/watchdog for safety.
- The interlock **logic** is verified in simulation: `firmware/ir_strobe/safety_model.py`
  self-tests every fault condition (host drop, under/over-voltage, blink, dose/duty caps,
  disable/reset) and asserts IR is forced OFF on each, all checks pass (2026-07-13). That
  proves the logic only; the same conditions must be bench-tested on real hardware at bring-up.
- ✅ At build: verify fail-safe FIRST (host app off ⇒ IR off; USB unplug ⇒ IR off), then
  **measure corneal-plane irradiance with the IR power meter** (ORDER_LIST), aggregate of
  ALL 2 LEDs per eye (on the under-eye illuminator bracket), target ≪ 1 mW/cm² average, and check the stuck-on (continuous) case.
- ⚠️ The retina cannot feel IR, never "check by feel"; never substitute security-camera
  IR illuminators.

## 2. Mechanical, near the face
- **Impact:** the carrier is rigid and worn on the face. Mitigations: desk use only , 
  do NOT walk around, drive, or do anything athletic wearing the rig; the padded clamps are
  a friction mount that can shear off upward in an impact (do not convert to the bonded
  mount until the desk-use phase is done); all printed ends are rounded (spheres/rbox).
- **Pointy bits audit:** M2 screw tips end inside the standoff bores (point away from skin);
  the clamp thumbscrews point FORWARD (away from the face); CF rod ends, trim flush and
  bury in the channel with adhesive, never leave a proud rod end (splinter hazard).
- **Nose-bridge drop legs** (pupil booms at x=±6): they hang 14.6 mm FORWARD of the lens
  plane, clear of the nose, but they are near the midline. ✅ Dry-fit check: put the draft
  on, look down/converge (reading posture) and confirm no contact at the nose in any pose.
- **Resin prints:** if SLA, fully wash + post-cure, uncured resin is a skin sensitizer.
  Pad every skin-contact surface (the jaws get silicone pads; the One Pro's own nose pads
  carry the face).

## 3. Electrical
- All logic/camera power is USB bus 5 V through the self-powered hub; no LiPo, no mains on
  the head. The 12 V brick stays on the desk.
- IR branch behind its own 300 mA polyfuse; star ground; twisted pair for the IR run
  (see WIRING). Insulate every joint near skin (heat-shrink, not tape).
- ✅ Before first wear: continuity + short check of the IR branch with LEDs disconnected;
  power the rig OFF-face for 10 min and touch-check every board.

## 4. Thermal
- 6 cameras ≈ 1-2 W each worst case; boards sit millimetres from skin at the temple and
  under-eye. ✅ During the first ON-face session, break every 10 min and touch-check the
  eye-corner + pupil boards; if any board is more than warm (>40 °C-ish), add standoff foam
  or reduce resolution/framerate. PLA softens ~55 °C, another reason drafts are PLA but
  the wear version is PETG/resin.

## 5. Weight + ergonomics
- The loaded carrier adds roughly 100-150 g to 87 g glasses, cantilevered forward. Expect
  nose-pad pressure and neck fatigue: limit early sessions to ~15-20 min, stop on pressure
  marks or headache. ✅ Weigh the loaded rig at build and record it (affects slip modelling
  too, heavier rig slips more).
- Cable drag: route per WIRING (groove + tie slots, one temple), leave a service loop at
  the temple tip, and make the hub-side connector the breakaway point (a snagged cable
  must unplug at the desk, not yank the head).

## 6. Vision
- The see-through cone is verified clear of every solid (cad_overlap.py), but only within
  the modelled 50°/29° display FOV, booms and boards DO obstruct far peripheral vision.
  Treat the rig as tunnel-vision equipment: seated desk use, no locomotion.

## 7. Hygiene
- NIR cams + IR rings sit close to the eyes: wipe the pads and any near-eye surface with
  isopropyl between users; don't share during illness; lash-contact with any lens = stop
  and re-fit (also ruins the images).

## Session checklist (run before every wear session at bring-up)
1. Verify the IR fail-safe (app off ⇒ dark on the NIR view).
2. Check thumbscrews snug, pads present, nothing loose (shake test off-face).
3. Run the 10-min thermal touch-check for this configuration.
4. Confirm seated use, cables strain-relieved, breakaway at the hub.
5. Set a timer (≤20 min early sessions).

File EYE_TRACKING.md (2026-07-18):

# Eye-tracking upgrade, design, placement, comfort, and safety

This **adds** real **eye tracking**: near-infrared (NIR) cameras + IR LEDs that image each
eye's **pupil and corneal glints**: **alongside** the eye-**corner** (canthus) cameras. In
the canonical **6-camera binocular** build (XREAL One Pro, a display per eye) the four
eye-facing cameras are **2 eye-corner + 2 NIR pupil** (one of each per eye); the two outward
world cameras see the AR dot. The pupil/glint cameras are an upgrade, not a detour, because
they give exactly what the AR registration needs, and more, while the corner cameras keep
pinning the glasses-on-face pose.

---

## 0. Why this is the right move (not just a cooler sensor)

The whole project's goal is: place an AR pixel so it lands on a real point, surviving the
glasses shifting on your face. That needs two things about the eye:

1. **Where the eye is** relative to the optic (eye relief, how the glasses sit).
2. **Where the eye is looking** (so the overlay can be foveated / registered to gaze).

Eye-corner cameras gave a weak proxy for (1) and nothing for (2). **Pupil + corneal
glints give both, directly:**

- **Glint geometry** (reflections of known IR LEDs off the cornea) pins the eyeball's 3D
  position relative to the glasses, far better than canthi.
- **Pupil-center → glint vector** gives gaze direction.

So this single sensor change makes the calibration *more* solvable, and unlocks foveated
rendering, auto-IPD, slip detection, and iris biometrics as free byproducts.

### Honest scope of "see inside the eye"
- **Iris** (the colored ring) and **pupil/limbus**: **yes**: NIR iris imaging is standard
  (it's how iris biometrics work). With a close camera + IR light you get a usable iris.
- **Retina / fundus** (back of the eye): **no.** That requires ophthalmoscope optics, a
  camera whose axis passes *through* the pupil with coaxial illumination, using the eye's
  own lens to focus on the retina. It cannot be done with a tiny off-axis camera on
  glasses. Anyone claiming glasses-mounted retinal imaging is overselling. We image the
  **anterior** eye (iris, pupil, sclera, glints). That is plenty.

---

## 1. Camera placement, the real analysis

The eye is a ~12 mm sphere with the cornea bulging at the front; the pupil sits at the
front center and the eyeball rotates (typically ±30°, up to ±50° at extremes) to fixate.
A tracking camera must keep the pupil + glints in view across that range. The constraints:

- **Occlusion:** the **upper lid + lashes** are the worst offenders (they cover the eye
  from above, especially when looking down). The lower lid moves less. The **nose** and
  medial canthus occlude from the nasal side.
- **Viewing angle:** the closer to on-axis (looking along the gaze), the rounder the pupil
  and the easier/more accurate the detection. Oblique angles make the pupil an ellipse
  (still trackable by ellipse-fitting) but at *extreme* angles the limbus edge clips it.
- **Comfort + optics intrusion:** cameras must not sit in your forward view, must not add
  pressure points, and must be light and balanced.

### The three candidate placements

| Placement | Pupil view | Occlusion | Comfort | Build difficulty | Notes |
|---|---|---|---|---|---|
| **Lower rim, looking up** (industry standard: Quest Pro, Pupil Labs, Varjo) | good, mild ellipse | **best**: lashes point away from a bottom-up view | good (weight on rim, not nose) | easy | the proven default |
| **Nose bridge / nasal**, looking out at the eye | ok, but oblique nasal view; worse when looking nasally; caruncle/nose can clip | medium | weight on the nose (already the contact point), must be light | easy, compact, central, hidden, one module feeds both eyes | the compact/central option |
| **Temple + hot mirror** (IR-reflective fold on the lens) | **best**: on-axis | low | good | **hard**: needs an IR mirror coating on the lens you don't own | best optics, worst DIY |

### Decision (SUPERSEDED): originally a nose-bridge module with camera arms, the CURRENT
### design mounts the NIR pupil cams UNDER-EYE on the one-piece carrier (see
### `cad/xreal_one_mount.scad` + RIGID_MOUNT_BUILD.md); the optical reasoning below still applies

The original nose-bridge design put the module at the bridge while borrowing the
lower-rim advantage:

- **Mount on the nose bridge** (central, hidden, one small module, short symmetric wiring,
  sits where the glasses already contact).
- **But the camera sits at the lower-nasal corner of each eye and looks up-and-out**, so it
  inherits the bottom-up placement's low lash occlusion and a workable pupil angle , 
  instead of a pure nasal side view (which struggles when you look toward your nose).
- Each eye gets its **own** camera (one bridge cam trying to cover both eyes is too
  wide-angle and too oblique for either). The bridge module carries both.

Net: central/comfortable mounting + near-lower-rim tracking quality. The NIR pupil cameras
sit under each eye looking up-and-out at the pupil, realised on the bonded carrier
(`cad/xreal_one_mount.scad`, `pupil_cam`, aimed with a look-at at the eye's centre of
rotation). The carrier is the single printed part, it also carries the eye-corner and world
cams, the IR rings, and the IMU.

### IR LED placement
Tracking quality depends more on **illumination** than on the camera. Place **3-4 IR LEDs
per eye**, spread around the eye (some on the bridge module, some on the lens rim) so you
get **multiple glints** (better eye-pose solve) and **even, shadow-free** pupil
illumination. Spread > clustered. Aim them at the eye, diffuse them slightly.

---

## 2. Comfort

The nose bridge is the comfort-critical contact, so:

- **Keep it light.** The two micro-cameras (~1 g each) + LEDs + thin wiring is only a few
  grams. Print the module thin-walled. Don't over-build the arms.
- **Soft, broad nose pads.** The module carries **stick-on silicone nose pads** (or
  reuses the XREAL One pads) on a slightly widened footprint to spread pressure, narrow
  hard plastic on the nose is what hurts.
- **Balance.** Mount cameras symmetrically; route the cable bundle straight back over the
  bridge so it doesn't tug one side.
- **No skin contact from hot/sharp parts.** Round all edges (the CAD does), keep LEDs and
  camera bodies off the skin, strain-relieve the cable so a snag doesn't yank the nose.
- **Removable.** It clips to the existing bridge, take it off without tools.

---

## 3. ⚠️ IR EYE SAFETY, read before powering any IR LED

You are putting infrared light next to the eye. **The retina cannot feel IR**, so there is
no pain or blink reflex to warn you of overexposure, this is exactly why IR sources can be
dangerous and why you must be conservative.

Rules this design follows:

1. **Use 940 nm LEDs**, not 850 nm. 940 nm is invisible (no red glow) and more of it is
   absorbed by the eye's water before reaching the retina. (850 nm has better camera SNR
   but a faint visible glow and slightly higher retinal hazard.)
2. **Low power.** Drive each LED at a **low current (≈5-15 mA)**, not its max. Commercial
   eye trackers sit far below safety limits; so do we. The BOM sizes resistors for this.
3. **Diffuse and spread** the light (multiple low-power LEDs, frosted) rather than one
   bright point, lower peak irradiance, better images.
4. **Strobe, don't stare.** Ideally pulse the LEDs only during the camera's exposure
   (sync), so average power is a fraction of continuous. At minimum, don't leave them on
   when not tracking.
5. **Stay well under the limit.** The relevant standard is **IEC 62471 / ICNIRP** infrared
   ocular exposure. As a conservative DIY rule of thumb, keep corneal irradiance **well
   under ~1 mW/cm²** average. If you can, measure it with an IR power meter; if you can't,
   stay at the low end of the current range and keep LEDs ≥10 mm from the eye.
6. **No high-power IR emitters.** Do **not** substitute IR illuminator modules meant for
   security cameras (hundreds of mW, meters of range), those are unsafe near the eye.
7. **Size the hardware for STUCK-ON.** The per-LED resistor must set a current that is safe
   for CONTINUOUS exposure at the mounted distance, never rely on the strobe duty cycle or
   the software watchdog for safety. Failure model: MOSFET fails short / MCU crashes with the
   gate asserted → the LEDs run continuous at the resistor-set current, and that state must
   already be under the limit. Strobing then only buys SNR and headroom, not safety.

If in doubt, use fewer/dimmer LEDs. The cameras are sensitive; you need less light than you
think. When you build it, verify the eye is comfortably illuminated in the camera at the
*lowest* current that works.
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

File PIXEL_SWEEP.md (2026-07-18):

# Pixel-by-Pixel Calibration Sweep

`software/pixel_sweep.py`: the large-scale data-generation run, stated as an algorithm
and grounded in the same physics as the rest of the rig.

## The protocol

100 eye geometries. Place the glasses (the CAD) on each face, use the glasses' own
cameras to make position guesses, and generate 100 different glasses positions on each
face. Then go pixel by pixel: guess a point that lies on a straight line that intersects
the dot, the pixel, and the location where light enters the eye. A user-AI corrects the
guessing-AI until it guesses correctly twice in a row, then the sweep moves to the next
pixel, for every pixel, for each of the 100 eye geometries, and within each eye
geometry, the 100 glasses positions.

The resulting dataset is **100 faces × 100 glasses positions × pixels × avg
guesses-to-correct**; `sum(guess_counts)` *is* that product.

## How each clause is realized (and where it comes from)
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

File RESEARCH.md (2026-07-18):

# State of the art, how others approach this, and what we should take

A survey of the relevant literature and products, mapped to *our* project (auto-calibrating
an optical see-through display using eye tracking). The short version: **what we're building
is a recognized research problem with a 20-year literature, the design choices here mostly
match it, and there are specific, proven techniques we should adopt.** Sources are linked inline.

---
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

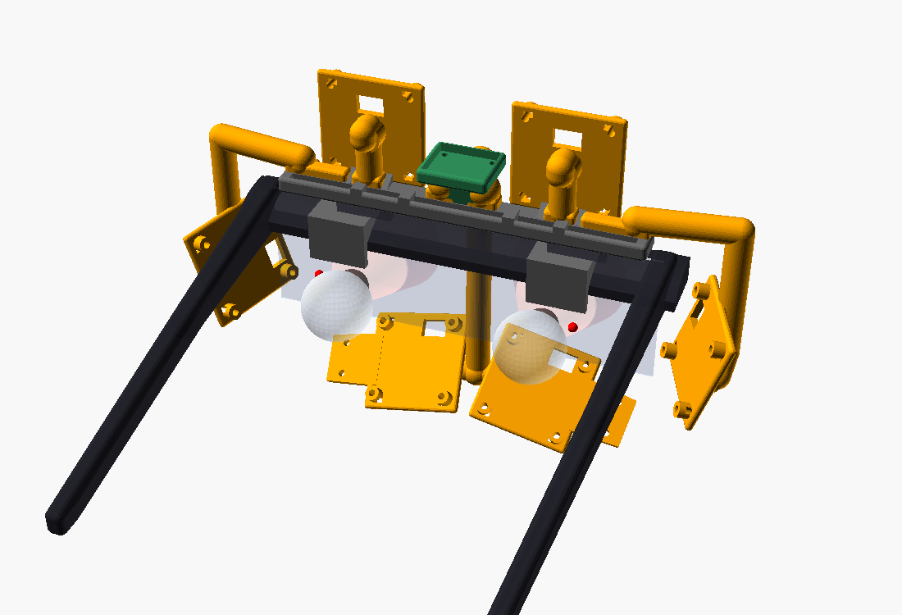
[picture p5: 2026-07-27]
media/session-2026-07/carrier_underside.png

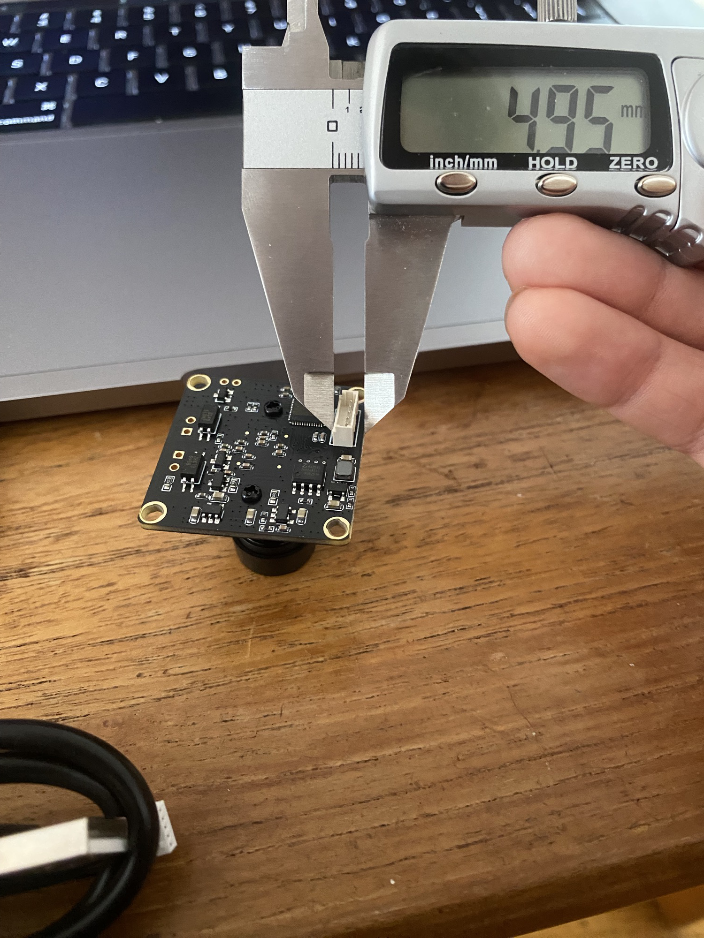
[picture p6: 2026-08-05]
media/session-2026-08-04/camera_board_caliper_thickness.jpg

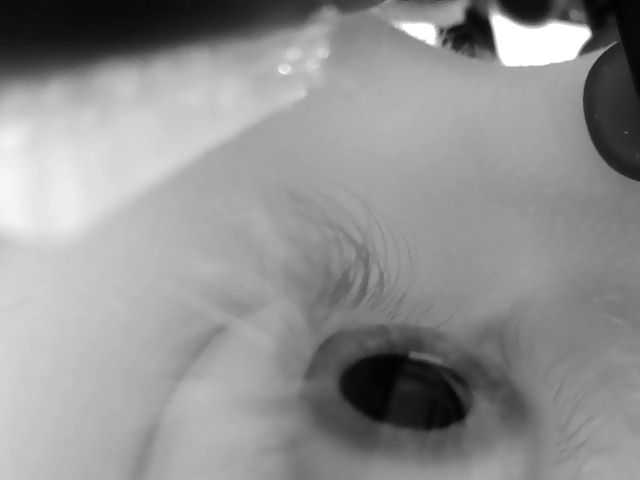
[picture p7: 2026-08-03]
media/session-2026-08-03/eyeR_worn.png

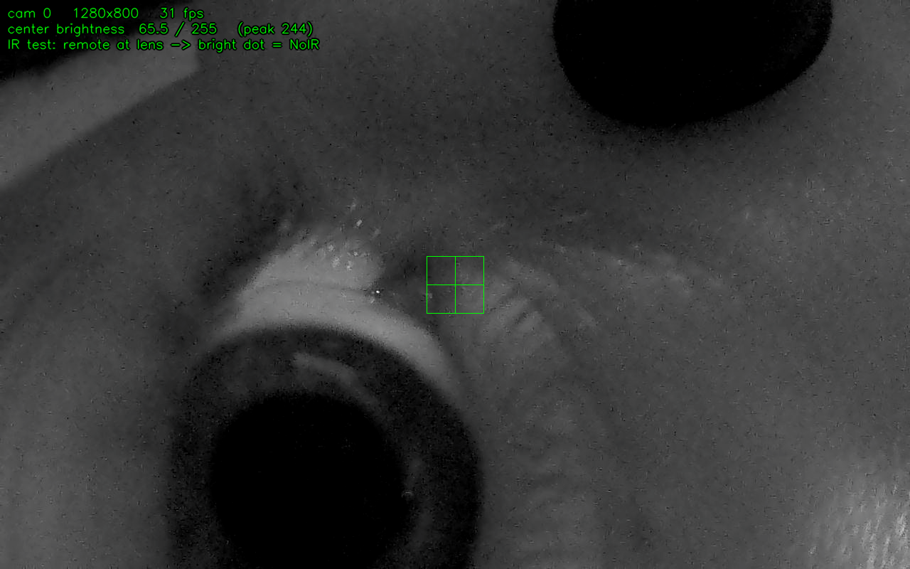
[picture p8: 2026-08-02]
media/eye-camera-samples/eyeL_canthus_tracked_2.png

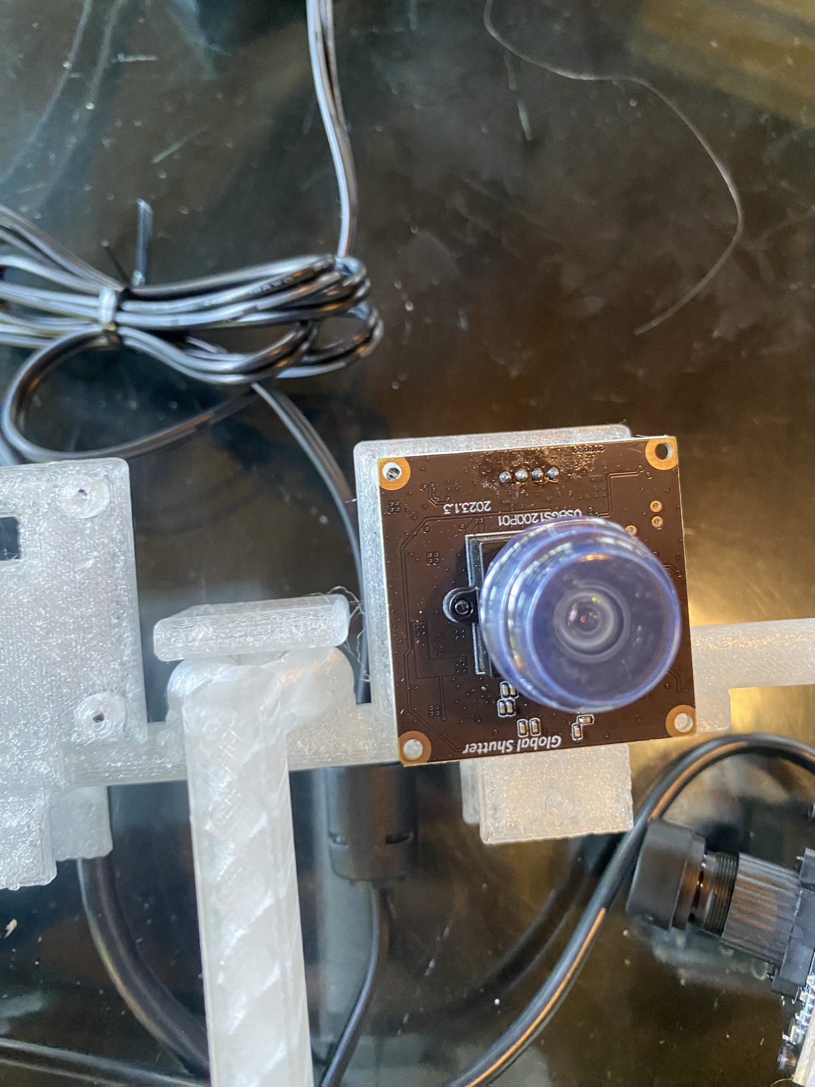
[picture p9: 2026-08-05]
media/session-2026-08-04/eye_camera_mounted_on_boom.jpg

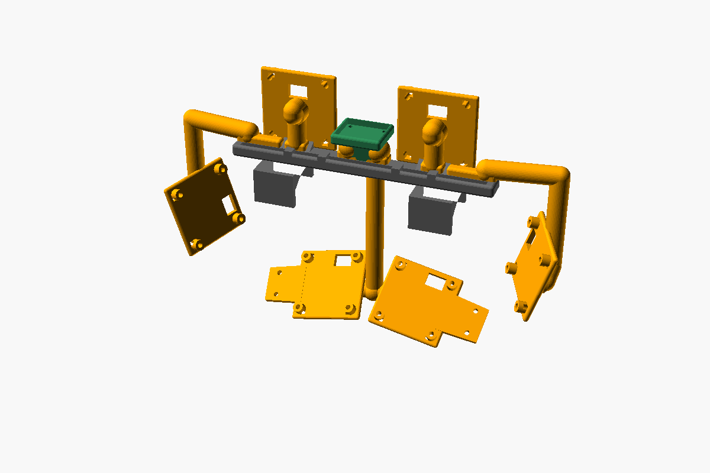
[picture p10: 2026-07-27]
media/session-2026-07/carrier_led_shelves.png

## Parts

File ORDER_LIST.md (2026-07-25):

# Order list, every part, with links

Sourced for **Canadian delivery**. Confirmed products link to the vendor; everything else is an
**Amazon.ca search link** (always resolves to current in‑stock Canadian listings, no stale
URLs). Verify price/stock/variant at checkout. **CORE** = 6‑camera binocular build; **▲** = upgrades
(stereo 8‑cam accuracy upgrade; Jetson; kinematic mount; power meter).

> Camera variant warning: get the **USB / UVC** version of every camera (for the Mac). The
> Arducam OV9281 and ELP AR0234 also come in **MIPI/CSI** versions, those are for a Pi/Jetson.

## A. Display + compute
| ✔ | tier | part | qty | link |
|---|---|---|---|---|
| ☐ | core | **XREAL One Pro** (US$599; 1080p, 57° diag) | 1 | https://us.shop.xreal.com/products/xreal-one-pro · https://www.amazon.ca/s?k=XREAL+One+Pro |
| ☐ | core | Mac (host), runs the **6‑cam binocular CORE** over 1-2 powered USB3 hubs | have |, |
| ☐ | ▲ | NVIDIA Jetson Orin Nano dev kit, for the **8‑cam FULL** (USB bandwidth; cameras stay UVC) | 1 | https://www.amazon.ca/s?k=NVIDIA+Jetson+Orin+Nano+developer+kit |

## B. Cameras + lenses , **BINOCULAR** (XREAL One Pro has a display PER EYE; both eyes are tracked)
| ✔ | tier | part | qty | link |
|---|---|---|---|---|
| ☐ | core | **Arducam OV9281** 1MP global‑shutter **mono NoIR USB**: eye‑corner ×2 + NIR pupil ×2 (**one per eye**) | 4 | https://www.arducam.com/product/arducam_ov9281_1mp_global_shutter_usb_camera_evaluation_kit_ek026/ · https://www.amazon.ca/s?k=Arducam+OV9281+USB+global+shutter+mono |
| ☐ | ▲ | OV9281 NoIR USB, **stereo** eye‑corner pair (one per eye; the FULL accuracy upgrade) | +2 | (same link) |
| ☐ | core | **ELP AR0234** 2MP global‑shutter wide‑angle **USB** world cam (**shared** by both eyes) | 2 | https://www.amazon.ca/s?k=ELP+AR0234+global+shutter+USB+camera |
| ☐ | core | M12 lens assortment (90° eye / 55° pupil / 70° world, if stock lenses don't match) | 1 |
| ☐ | core | M12 **lens locking rings** (verify included with the camera modules first) or removable threadlocker, lock focus after calibration | 1 | https://www.amazon.ca/s?k=M12+lens+kit+camera+module |

> **Camera count:** binocular CORE = **6 cams** (2 world + 2 eye‑corner + 2 NIR pupil); FULL =
> **8 cams** (+2 stereo). Honest accuracy: ~4.3 px PERCEIVED deployed (vernier UI + per-user offset, simulated with realistic user error), 0.89 px pipeline bound; the <1 px pathway (stereo + multi-vergence kappa) awaits hardware validation. 2 world + 2 eye‑corner already register
> BOTH eyes; the 2 NIR cams add per‑eye geometry‑ID + the inter‑eye (dichoptic) alignment.

> **Module dimensions the printed holders are built for (verify with calipers before printing):**
> ELP AR0234 USB = **38 × 38 mm** PCB + M12 lens; Arducam OV9281 USB = **36 × 36 mm** PCB (≈28 mm
> mount‑hole pattern) + M12. The carrier (`cad/xreal_one_mount.scad`) holds each as a real board:
> a backing plate + 4 M2 standoffs at the mount pitch, lens clearance, cable notch, NOT an abstract
> pocket. `software/cad_fit.py` verifies every real board clears both the see‑through cone AND the
> eyeball at its rig.py position (the camera positions were nudged so the 36-38 mm boards fit; the
> 24 mm **Mini OV9281 is MIPI** and would need the Jetson, so it's not the USB/Mac path).

## C. NIR illumination
| ✔ | tier | part | qty | link |
|---|---|---|---|---|
| ☐ | core | 940 nm IR LEDs, 3 mm (NOT 850): **2 per eye = 4** on the under-eye `led_bracket` (buy a pack for spares) | 1 pack | https://www.amazon.ca/s?k=940nm+IR+LED+3mm |
| ☐ | core | IR‑pass filter 850-1000 nm, one per NIR **pupil** cam (**2** binocular; +stereo optional) | 2 | https://www.amazon.ca/s?k=IR+pass+filter+850nm+10mm |
| ☐ | core | Resistor kit (need 330-470 Ω for the LED strings **+ one 10 kΩ MOSFET-gate pull-down**) | 1 | https://www.amazon.ca/s?k=1%2F4W+resistor+assortment+kit |
| ☐ | core | **Seeed XIAO** (RP2040/SAMD21), strobes **both** LED rings + IMU I²C→USB bridge + safety watchdog | 1 | https://www.amazon.ca/s?k=Seeed+XIAO+RP2040 |
| ☐ | core | **2N7002 logic‑level MOSFET** (low‑side IR strobe switch, NOT a 2N2222 BJT) | 1 pack | https://www.amazon.ca/s?k=2N7002+MOSFET |
| ☐ | core | **300 mA PTC resettable polyfuse** (overcurrent protection on the IR branch) | 1 pack | https://www.amazon.ca/s?k=300mA+PTC+resettable+fuse |
| ☐ | core | **470 µF 10 V electrolytic caps** + 0.1 µF ceramics (5 V rail decoupling) | 1 pack | https://www.amazon.ca/s?k=470uF+10V+electrolytic+capacitor |
| ☐ | core | **TVS diode / 5 V clamp** (rail transient protection, voltage safeguard) | 1 pack | https://www.amazon.ca/s?k=5V+TVS+diode+SMBJ5.0A |
| ☐ | core | Perfboard | 1 | https://www.amazon.ca/s?k=perfboard+prototype+board |

## D. IMU
| ✔ | tier | part | qty | link |
|---|---|---|---|---|
| ☐ | core | **SparkFun ICM‑20948** 9‑DoF IMU (Qwiic), I²C | 1 | https://www.sparkfun.com/sparkfun-9dof-imu-breakout-icm-20948-qwiic.html · https://www.amazon.ca/s?k=ICM-20948+9DoF+IMU |

## E. Rigid mount / structural
| ✔ | tier | part | qty | link |
|---|---|---|---|---|
| ☐ | core | Rigid **resin** or **PC / nylon‑CF filament** (carrier; not plain PETG/PLA) | 1 | https://www.amazon.ca/s?k=nylon+carbon+fiber+filament · https://www.amazon.ca/s?k=rigid+3D+printer+resin |
| ☐ | core | **Carbon‑fibre rod 1.5 mm** (boom reinforcement) | 1 pack | https://www.amazon.ca/s?k=carbon+fiber+rod+1.5mm |
| ☐ | core | **Structural plastic‑bonding epoxy** (e.g. JB Weld PlasticWeld) + isopropyl + abrasive | 1 | https://www.amazon.ca/s?k=plastic+bonding+epoxy+JB+Weld |
| ☐ | core | M2 SELF-TAPPING screw assortment (6-10 mm; the printed bosses are bored 1.8 mm, heat-set inserts DON'T fit the d=5 bosses) | 1 | https://www.amazon.ca/s?k=M2+self+tapping+screws+assortment |
| ☐ | core | M3 thumbscrews (~8-12 mm) + M3 nuts, the 2 brow-clamp tighteners (screw_d 3.2 in the CAD) | 1 | https://www.amazon.ca/s?k=M3+thumb+screw+knurled |
| ☐ | ▲ | Kinematic kit: 6 mm precision steel balls + neodymium magnets (removable mount) | 1 | https://www.amazon.ca/s?k=6mm+precision+steel+balls · https://www.amazon.ca/s?k=neodymium+magnets+6mm |

## F. Wiring / connectivity
| ✔ | tier | part | qty | link |
|---|---|---|---|---|
| ☐ | core | **Industrial powered USB 3.0 hub w/ its own 12 V PSU**: the 5 V/3 A (15 W) main rail for the 6‑cam CORE (1 hub) | 1 | https://www.amazon.ca/s?k=industrial+USB+3.0+hub+12V+powered |
| ☐ | ▲ | 2nd powered USB 3.0 hub **or** Jetson, only for the **8‑cam FULL** (bandwidth) | +1 | https://www.amazon.ca/s?k=powered+USB+3.0+hub+4+port |
| ☐ | core | USB‑C multiport dock (free Mac ports) | 1 | https://www.amazon.ca/s?k=USB-C+hub+multiport+adapter |
| ☐ | core | Short USB camera cables / micro‑USB leads (one per cam: 6 core / 8 full) | ~8 | https://www.amazon.ca/s?k=short+micro+USB+cable+pack |
| ☐ | core | **24 or 26 AWG silicone wire**: the main 5 V trunk (hub → carrier, full 3 A) | 1 | https://www.amazon.ca/s?k=24AWG+silicone+wire+kit |
| ☐ | core | **30 AWG silicone wire** + heat‑shrink, individual component branches only | 1 | https://www.amazon.ca/s?k=30AWG+silicone+wire+kit |
| ☐ | core | JST‑SH connector kit | 1 | https://www.amazon.ca/s?k=JST+SH+connector+kit |
| ☐ | core | Kapton / foam tape | 1 | https://www.amazon.ca/s?k=Kapton+tape |

## G. Calibration + tools
| ✔ | tier | part | qty | link |
|---|---|---|---|---|
| ☐ | core | Digital calipers | 1 | https://www.amazon.ca/s?k=digital+calipers |
| ☐ | core | Checkerboard calibration target (rigid) | 1 | https://www.amazon.ca/s?k=camera+calibration+checkerboard+target |
| ~~☐~~ | ~~core~~ | ~~Wired gamepad~~, NOT NEEDED: Mac arrow keys drive the alignment UI (vernier.py: arrows 1 px, shift 0.25 px) | 0 | https://www.amazon.ca/s?k=8BitDo+wired+controller |
| ☐ | core | Soldering iron kit (if needed) | 1 | https://www.amazon.ca/s?k=soldering+iron+kit |
| ☐ | ▲ | IR / optical power meter (eye‑safety check) | 1 | https://www.amazon.ca/s?k=optical+power+meter |

## H. Comfort / face-contact padding
| ✔ | tier | part | qty | link |
|---|---|---|---|---|
| ☐ | core | Adhesive silicone nose pads (for the bridge pad recesses) | 1 | https://www.amazon.ca/s?k=adhesive+silicone+nose+pads+eyeglasses |
| ☐ | core | **Thin PTFE/felt tape (~0.5 mm)** for the clamp jaws (fit is sized for 0.5 mm linings) + **soft pad stock**: pad every printed surface that touches the face (nose pads, any brow/cheek contact) | 1 | https://www.amazon.ca/s?k=adhesive+silicone+foam+pad+sheet |

Electronic components (resistors, MOSFETs, JST, IMU) are also on **digikey.ca / mouser.ca** if you
prefer a single‑order electronics supplier with guaranteed parts.

---

## Where to buy, best sources per part class (Canadian sourcing)

| Part class | First choice | Backup | Notes |
|---|---|---|---|
| XREAL One Pro | xreal.com direct | Amazon.ca | Direct gets current firmware/revision; check DDP (duties prepaid) at checkout |
| Arducam OV9281 USB (eye/pupil, NoIR) | Arducam official store (arducam.com) | UCTRONICS storefront on Amazon.ca | Official store guarantees the exact SKU (USB, NoIR, no IR-cut); Amazon faster but verify the listing is the USB UVC variant, not MIPI |
| ELP AR0234 USB (world) | ELP/Ailipu official AliExpress store | Amazon.ca ELP listings | AliExpress = the manufacturer, ~2-3 wk; Amazon ~1 wk but fewer lens options, confirm M12 wide lens variant |
| Small electronics: XIAO MCU, ICM-20948 breakout, 2N7002, resistors, 300 mA polyfuse, 940 nm LEDs, JST, perfboard | **Digi-Key Canada (digikey.ca)**: one cart for all of it | Mouser.ca | fast Canadian shipping, CAD pricing, no surprise duties, free ship over ~$100, put every loose component in this one order |
| M12 940 nm IR-pass filters | Arducam (with the cams) | AliExpress "M12 940nm IR pass" | Ordering with the cameras avoids thread-size guessing (M12x0.5) |
| Industrial powered USB 3.0 hub | StarTech (Canadian; startech.com or Amazon.ca) | Anker on Amazon.ca | Buy the 12 V self-powered industrial model, not a travel hub, the 5 V rail is the whole power budget |
| M2 self-tapping screws, M3 thumbscrews + nuts, zip ties | Amazon.ca assortment kits | Bolt Depot (US) for exact sizes | Kits cover the sizes; nothing exotic |
| CF rods 1.5 mm, silicone pads, structural epoxy | Local RC-hobby shop (carbon rod) + Amazon.ca |, | RC shops stock 1.5 mm carbon rod cut lengths; epoxy only needed at the later bonded phase |
| SLA/rigid printing (if not printing at home) | Local print farm / library makerspace (draft PLA) | JLC3DP / Craftcloud for the resin/nylon-CF final | Draft in PLA locally first; ship out only the final rigid print |
| Odds and ends: calipers, IR power meter, Kapton | Amazon.ca | Canadian Tire (calipers) | The IR power meter is the one "trust but verify" purchase, get one that lists a 940 nm calibration point |

**Ordering strategy:** three carts, (1) Digi-Key for every component-drawer item (fast, one
shipment), (2) the two camera vendors (longest lead, order FIRST), (3) Amazon.ca for the
mechanical/consumables. The cameras gate the schedule; everything else arrives faster.

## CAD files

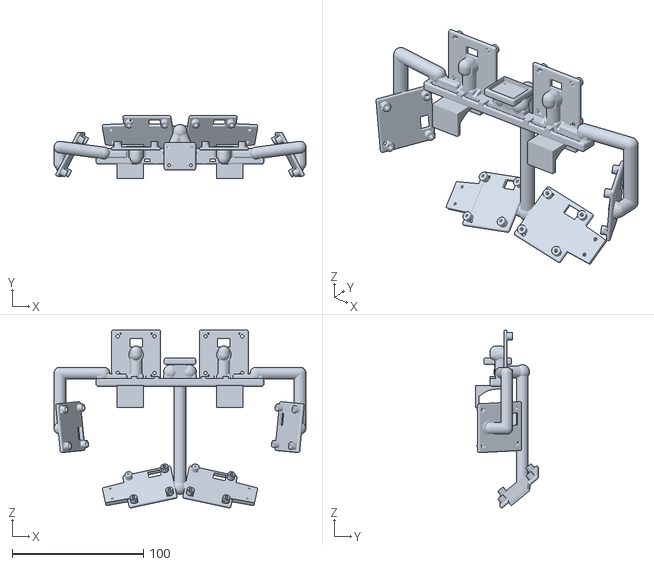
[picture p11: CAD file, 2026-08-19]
_printable_stls/xreal_carrier_draft_reaim.stl
192.3 x 47.9 x 135.8

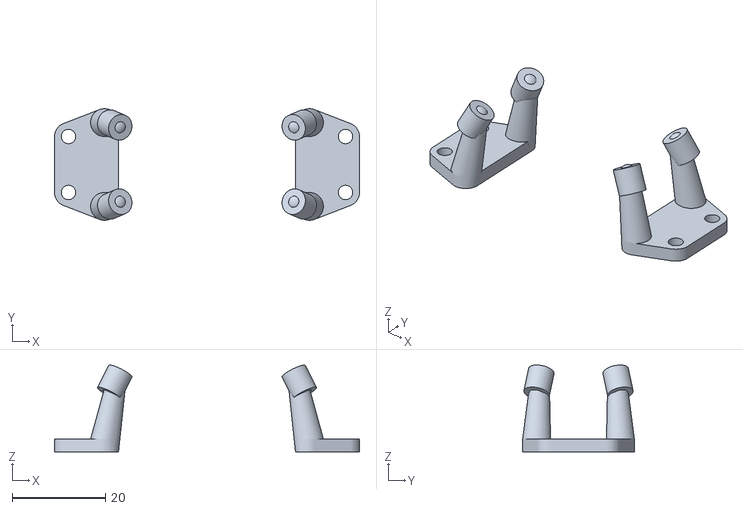
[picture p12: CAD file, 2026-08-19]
_printable_stls/xreal_led_bracket.stl
65.5 x 24.0 x 18.7

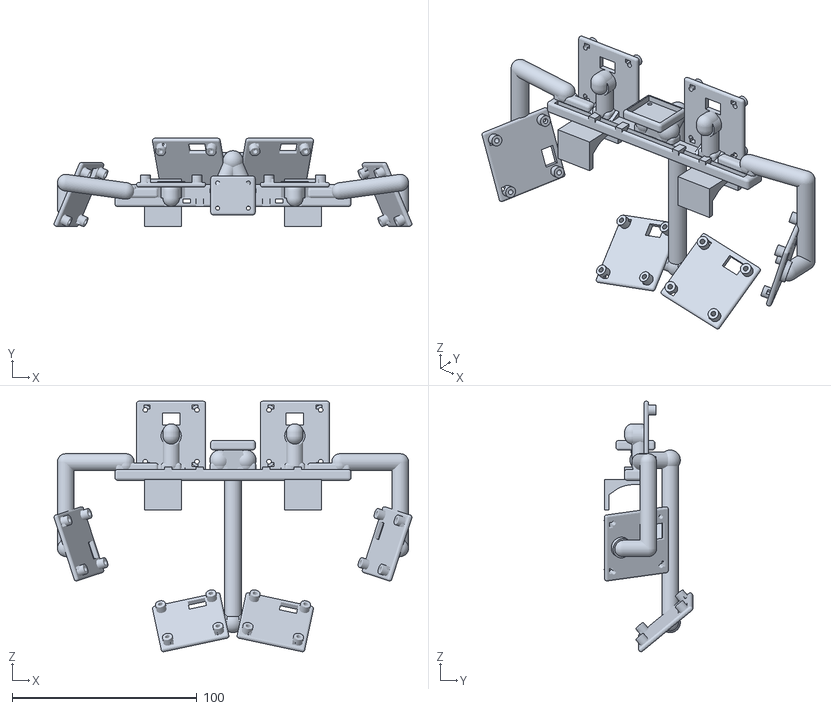
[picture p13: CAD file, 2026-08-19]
_printable_stls/xreal_carrier_v9.stl
194.0 x 48.0 x 135.8

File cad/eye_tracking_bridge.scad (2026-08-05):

// =====================================================================
//  Nose-bridge NOSE / IMU SUPPORT  (clips to XREAL One Pro / One / Rokid bridge)
// =====================================================================
//  ⚠️ NOT REQUIRED FOR THE BUILD. The whole rig needs ONLY cad/xreal_one_mount.scad:
//  the bonded carrier now holds all 6 cameras, the IR rings, AND the IMU
//  (module imu_mount). The XREAL One Pro's OWN padded nose pads carry the face. This
//  file is kept as an OPTIONAL accessory (a separate clip-on nose/IMU support if you'd
// rather not put the IMU on the carrier), it is legacy and not part of the canonical
//  single-part build.
// =====================================================================
//  ⚠️ NOT A CAMERA MODULE. The 6-camera BINOCULAR build keeps ALL cameras on the single
// bonded carrier in cad/xreal_one_mount.scad, including the TWO NIR pupil cameras
//  (pupil_cam, one per eye) and the IR LED rings around BOTH eyes (ir_leds), at the
//  software/rig.py positions (the ONE source of truth for camera geometry). The old
//  camera modules in THIS file have been removed from the assembly to avoid a stray cam.
//
//  This file is the NON-camera nose support: the bridge body, soft (PADDED) nose pads, the
// bridge clip, and the IMU shelf (tilt/slip + the Kalman drift filter, see imu.py /
//  WIRING.md). cam_holder()/ir_unit()/cam_arm() are kept only as reference and are NOT
//  rendered. Same Z-up frame as xreal_one_mount.scad:
//    +x = right, +y = FORWARD (world), +z = UP, origin at the optic center. mm.
//
//  ⚠️ MEASURE + tune the bridge-clip thickness and nose-pad fit. Print in a STIFF material
//    (SLA resin or PC / nylon-CF, NOT plain PETG/PLA), 0.2 mm. The nose pads carry a soft
// silicone/foam pad in the recess, no bare hard plastic on the nose.
//    openscad -D 'part="all"' -o bridge_support.stl eye_tracking_bridge.scad
//    openscad -D 'part="all"' -o bridge_support.stl eye_tracking_bridge.scad
// =====================================================================

part = "all";   // "all" | "support" | "imu_mount"  (camera parts removed; see xreal_one_mount.scad)
$fn = 56;

// ---------- which glasses? (sets the bridge-bar thickness preset) ------
target = "xreal_one_pro";   // "xreal_one_pro" | "xreal_one" | "rokid_max"

// ---------- eye / face fit (MEASURE) ----------------------------------
ipd       = 64;     // interpupillary distance (One Pro: M 57–66 / L 66–75 mm)
eye_back  = 18;     // pupil sits this far BEHIND the optic plane (-y)
eye_drop  = 2;      // pupil this far below optic center (-z)

// ---------- eye camera (OV9281-class tiny module) ---------------------
ov_w = 9;  ov_h = 9;  ov_d = 6;   // module footprint + depth (tune to your cam)
lens_d = 3.6;                     // lens clear-aperture hole
wall   = 1.6;                     // thin walls = light on the nose

// (REFERENCE ONLY, not rendered.) These old bridge-camera offsets are STALE; the live NIR
// pupil-camera geometry is software/rig.py PUPIL_POS (now [24, -30, 6]) realised on the bonded
// carrier in xreal_one_mount.scad. Do not treat the numbers below as current.
cam_nasal_in = 6;    // |x| inset toward the nose from the pupil (so x = 26 at ipd 64)
cam_fwd      = 6;    // in front of the optic plane  (sim z = 6)
cam_below    = 14;   // below the optic center        (sim y = -14)
arm_w        = 6;    // camera-arm thickness (thicker = stiffer; rigidity matters, see flex.log)

// ---------- IR LEDs (940 nm, low power, see EYE_TRACKING.md safety) ---
led_d     = 3.2;     // 3 mm LED + clearance (use SMD pockets if smaller)
led_wall  = 1.0;
led_depth = 4.5;

// ---------- bridge body + nose pads -----------------------------------
bw = 30;  bd = 12;  bh = 9;       // central body block
body_y = -4;  body_z = -13;       // body center (below + behind the optic)
arm_root_x = 8;                   // where each arm leaves the body
pad_x = 7;  pad_splay = 18;       // nose-pad lateral offset + inward cant (deg)
pad_w = 9;  pad_h = 13;  pad_t = 3;

// ---------- IMU (6/9-axis MEMS breakout: tilt/slip detection, NOT geometry ID) ----
//  Rigidly mounted to the body (which clips to the frame), so it reads the GLASSES'
// pitch/roll vs gravity. Its job is robustness, bump/re-seat detection + inter-frame
// motion + a gravity "down" reference, NOT identifying eye geometry (the sim showed a
//  level adds ~0 there). Mount FLAT with the board's X along +x and Y along +y so the
//  reading maps directly to pose dev[0] (pantoscopic pitch) / dev[2] (roll); see imu.py.
imu_w = 21;  imu_h = 18;  imu_t = 2.0;   // typical 9-DoF breakout PCB (e.g. ICM-20948/BNO055)
imu_wall = 1.6;  imu_screw_d = 2.2;      // M2 mount holes
imu_drop = 5;                            // sits this far below the body bottom, on a shelf

// ---------- clip onto the glasses bridge bar (MEASURE xr_bridge_t) -----
xr_bridge_t = (target == "rokid_max") ? 4.5 : (target == "xreal_one") ? 4.0 : 3.6; // bridge-bar thickness (One Pro flat optic ≈ 3.6; MEASURE)
clip_w = 10;  clip_reach = 11;  clip_wall = 2.2;  clip_clear = 0.4;
clip_up = 9;         // how far up from the body the clip reaches to the bridge

// =====================================================================
//  PRIMITIVES (shared style with the main bracket)
// =====================================================================
module rbox(w, d, h, r) {
    hull() for (sx=[-1,1]) for (sy=[-1,1]) for (sz=[-1,1])
        translate([sx*(w/2-r), sy*(d/2-r), sz*(h/2-r)]) sphere(r);
}
module capsule(p0, p1, dia) {
    hull() { translate(p0) sphere(dia/2); translate(p1) sphere(dia/2); }
}
// orient children's +z from `from` toward `to`
module aim_z_at(from, to) {
    v = [to[0]-from[0], to[1]-from[1], to[2]-from[2]];
    L = norm(v);
    rotate([-asin(v[1]/L), atan2(v[0], v[2]), 0]) children();
}

function pupil(side) = [side*ipd/2, -eye_back, -eye_drop];
function campos(side) = [side*(ipd/2 - cam_nasal_in), cam_fwd, -cam_below];

// =====================================================================
//  CAMERA HOLDER  (local +z = optical axis; lens faces +z toward the eye)
// =====================================================================
module cam_holder() {
    ow = ov_w + 2*wall;  oh = ov_h + 2*wall;  od = ov_d + wall;
    difference() {
        translate([-ow/2, -oh/2, -od]) cube([ow, oh, od]);        // body, front at z=0
        translate([-ov_w/2, -ov_h/2, -od-0.5]) cube([ov_w, ov_h, ov_d+0.5]); // board pocket (back)
        translate([0, 0, -wall-0.5]) cylinder(h = wall+1, d = lens_d);       // lens hole (front)
    }
}

// one IR-LED boss aimed at the eye, on a short stalk from the camera
module ir_unit(side, pos) {
    capsule(campos(side), pos, 3);
    translate(pos) aim_z_at(pos, pupil(side))
        difference() {
            cylinder(h = led_depth, d = led_d + 2*led_wall);
            translate([0, 0, -0.5]) cylinder(h = led_depth + 1, d = led_d);
        }
}

// =====================================================================
//  CAMERA ARM  (strut from the body + aimed camera + two IR LEDs)
// =====================================================================
module cam_arm(side) {
    root = [side*arm_root_x, body_y, body_z];
    color("steelblue") {
        capsule(root, campos(side), arm_w);
        translate(campos(side)) aim_z_at(campos(side), pupil(side)) cam_holder();
    }
    color("orange") {
        ir_unit(side, campos(side) + [side*7, 0,  3]);    // lateral LED
        ir_unit(side, campos(side) + [-side*3, 0, -6]);   // lower LED
    }
}

// =====================================================================
//  BODY + NOSE PADS + BRIDGE CLIP
// =====================================================================
module bridge_body() {
    translate([0, body_y, body_z]) rbox(bw, bd, bh, 2);
}

// Soft, broad nose pads. The face-contacting side is a RECESS sized to seat a stick-on
// SILICONE / foam pad (pad_soft_t thick) so the nose never touches bare hard plastic, required
// padding for every printed face-contact surface (EYE_TRACKING.md §2 comfort). Broad + canted to
// spread pressure; rounded edges.
pad_soft_t = 1.6;   // thickness of the soft pad that drops into the recess
module nose_pads() {
    for (s = [-1, 1])
        translate([s*pad_x, body_y, body_z - bh/2])
            rotate([0, 0, s*pad_splay])
                difference() {
                    rbox(pad_w, pad_h, pad_t, 1);
                    // full-face recess for the soft pad (covers the whole contact area, not a thin ring)
                    translate([0, 0, pad_t/2 - pad_soft_t/2 + 0.01])
                        rbox(pad_w-1.6, pad_h-1.6, pad_soft_t, 0.8);
                }
}
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

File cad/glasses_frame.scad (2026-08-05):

// =====================================================================
// AR Eye-Corner Calibration Rig, Meta-Ray-Ban-style frame, modified
// =====================================================================
//  NOTE: This is the LEGACY Path-B (DIY combiner) FALLBACK frame, NOT the canonical
// build. The canonical model is the 6-camera BINOCULAR rig on the XREAL One Pro , 
//  print `xreal_one_mount.scad` (bonded carrier: 2 world + 2 eye-corner + 2 NIR pupil)
//  + `eye_tracking_bridge.scad` (nose/IMU). Use THIS file only if you have no XREAL
//  display and are building a from-scratch Path-B combiner. The world cameras here are
//  placed at the PUPILS (±ipd/2), matching the XREAL mount, so the camera sees what the
//  eye sees.
//  ⚠️ This frame sits directly on the face: pad EVERY face-contact surface (nose pads,
// brow, temple ends) with soft silicone/foam, no bare hard plastic on skin.
//
//  Parametric, 3D-printable. A "Wayfarer"-ish frame with mounts added for:
//    - 2x forward "world" cameras (outer top corners, like Ray-Ban Meta)
//    - 2x inward "eye-corner" tube cameras (booms aimed at the canthi)
//    - 1x display combiner (Path B beamsplitter + microdisplay shelf)
//
//  This is a *starting* parametric model. Measure your own face / your real
//  Ray-Ban Meta frames and tune the parameters at the top before printing.
//  Print in PETG or ABS (lives on your face, near skin heat). Supports off,
// 0.2 mm layers. The eye-cam booms are thin, print slow or add a brim.
//
//  Render a single part for printing by setting `part` below, or "all" to
//  preview the assembly. Then: openscad -o frame.stl glasses_frame.scad
// =====================================================================

part = "all";   // "all" | "frame" | "world_pod" | "eye_boom" | "combiner"

$fn = 56;

// ---------- face / frame fit (MEASURE THESE on your face) -------------
lens_w        = 50;   // lens opening width
lens_h        = 40;   // lens opening height
lens_r        = 9;    // lens corner radius
bridge_gap    = 18;   // gap between the two lenses (over the nose)
ipd = 64; // YOUR interpupillary distance, mm, world cams sit here
rim_t         = 3.5;  // rim border thickness around each lens
front_depth   = 6;    // front-to-back thickness of the frame front
brow_h        = 5;    // height of the top brow bar
panto_tilt    = 8;    // pantoscopic tilt of temples, degrees

// ---------- temples (arms) --------------------------------------------
temple_len    = 132;
temple_h      = 9;
temple_t      = 4;
ear_bend_len  = 22;   // the part that curls behind the ear
ear_bend_deg  = 28;

// ---------- world camera pod (forward) --------------------------------
// Sized for a ~10x10 mm board camera (e.g. small USB module). Tune to yours.
wc_w = 11;  wc_h = 11;  wc_d = 9;  wc_wall = 2;
wc_lens_d = 5;          // hole for the lens barrel to see through

// ---------- eye-corner tube camera (inward) ---------------------------
// Sized for a 7 mm endoscope/borescope tube camera. Tune ec_tube_d to yours.
ec_tube_d   = 7.4;      // tube dia + clearance
ec_ring_t   = 2.4;      // clamp ring wall
ec_boom_len = 24;       // reach from frame edge toward the eye corner
ec_boom_w   = 5;
ec_boom_t   = 3;
ec_aim_in   = 34;       // yaw: point inward toward the outer canthus, deg
ec_aim_down = 12;       // pitch: a touch downward, deg

// ---------- display combiner (Path B) ---------------------------------
// 45-deg beamsplitter in front of the RIGHT eye + shelf for a microdisplay.
cb_glass_w  = 24;       // beamsplitter width
cb_glass_h  = 20;       // beamsplitter height
cb_slot_t   = 1.6;      // glass thickness + clearance
cb_disp_w   = 28;       // microdisplay board footprint
cb_disp_d   = 22;
cb_arm_t    = 3;
which_eye   = "right";  // which lens carries the combiner

// derived lens centers (x); +x is wearer's left in this model
lens_cx = bridge_gap/2 + lens_w/2;

// =====================================================================
//  PRIMITIVES
// =====================================================================
module rrect(w, h, r) {              // rounded rectangle, centered, 2D
    offset(r) offset(-r) square([w, h], center = true);
}

module lens_rim(cx) {                // one lens border, extruded
    translate([cx, 0, 0])
    linear_extrude(front_depth)
    difference() {
        rrect(lens_w + 2*rim_t, lens_h + 2*rim_t, lens_r + rim_t);
        rrect(lens_w, lens_h, lens_r);
    }
}

// =====================================================================
//  FRAME FRONT  (two rims + bridge + brow bar)
// =====================================================================
module bridge_bar() {
    bw = bridge_gap + 2*rim_t + 6;
    translate([-bw/2, lens_h/2 - brow_h, 0])
        cube([bw, brow_h, front_depth]);
}

module brow_bar() {
    bw = 2*lens_cx + lens_w + 2*rim_t;   // span outer-to-outer
    translate([-bw/2, lens_h/2 + rim_t - brow_h, 0])
        cube([bw, brow_h, front_depth]);
}

module nose_pads() {
    for (s = [-1, 1])
        translate([s * (bridge_gap/2 - 1), -lens_h/2 + 8, front_depth/2])
            rotate([0, s*12, 0])
                scale([1, 1.6, 0.6]) sphere(4);
}

// =====================================================================
//  TEMPLES (arms)
// =====================================================================
module temple(side) {                // side = -1 left, +1 right
    sx = side * (lens_cx + lens_w/2 + rim_t);
    translate([sx, lens_h/2 - temple_h, front_depth])
    rotate([panto_tilt, 0, 0])
    rotate([0, side*90, 0]) {        // run the arm backward (+z -> along x)
        // straight part
        cube([temple_len - ear_bend_len, temple_h, temple_t]);
        // ear bend
        translate([temple_len - ear_bend_len, 0, 0])
            rotate([0, 0, side*ear_bend_deg])
                cube([ear_bend_len, temple_h, temple_t]);
    }
}

// =====================================================================
//  WORLD CAMERA POD  (outer top corner, facing forward)
// =====================================================================
module world_pod_solid() {
    cube([wc_w + 2*wc_wall, wc_h + 2*wc_wall, wc_d + wc_wall]);
}
module world_pod_cavity() {
    translate([wc_wall, wc_wall, wc_wall])
        cube([wc_w, wc_h, wc_d + 1]);
    // lens see-through hole out the front (-y face here mapped below)
    translate([(wc_w + 2*wc_wall)/2, -1, (wc_d + wc_wall)/2])
        rotate([-90, 0, 0]) cylinder(h = wc_wall + 2, d = wc_lens_d);
}
module world_pod() {                 // standalone, origin at corner
    difference() { world_pod_solid(); world_pod_cavity(); }
}
module world_pod_on_frame(side) {
    // Place the world cam at the PUPIL (±ipd/2), just above the lens aperture,
    // so its viewpoint matches the eye's (minimal parallax). Pointing forward.
    px = side * ipd / 2;
    translate([px - (wc_w + 2*wc_wall)/2,
               lens_h/2 + rim_t - (wc_h + 2*wc_wall),
               front_depth - (wc_d + wc_wall)])
        world_pod();
}

// =====================================================================
//  EYE-CORNER CAMERA BOOM  (tube clamp on an angled boom)
// =====================================================================
module tube_ring() {
    difference() {
        cylinder(h = ec_boom_w + 2, d = ec_tube_d + 2*ec_ring_t);
        translate([0, 0, -1]) cylinder(h = ec_boom_w + 4, d = ec_tube_d);
        // slit so it clamps onto the tube
        translate([-0.6, 0, -1]) cube([1.2, ec_tube_d, ec_boom_w + 4]);
    }
}
module eye_boom() {                  // standalone, boom from origin
    // boom arm
    cube([ec_boom_len, ec_boom_w, ec_boom_t]);
    // ring at the far end, axis along boom so the tube looks back at the eye
    translate([ec_boom_len, ec_boom_w/2, 0])
        rotate([0, 0, 0]) tube_ring();
}
module eye_boom_on_frame(side) {     // side = -1 left, +1 right
    sx = side * (lens_cx + lens_w/2 + rim_t);
    translate([sx, lens_h/2 - temple_h, front_depth - ec_boom_t])
    rotate([ -ec_aim_down, 0, -side*(90 - ec_aim_in) ])
        eye_boom();
}
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

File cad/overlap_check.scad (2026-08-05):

// =====================================================================
// overlap_check.scad, pairwise solid-intersection harness for the clip-on carrier
//  Driven by software/cad_overlap.py:
//      openscad -D 'part="none"' -D 'compA="worldR"' -D 'compB="glasses"' \
//               --export-format binstl -o pair.stl overlap_check.scad
//  Renders intersection(compA, compB); an empty STL (or ~0 volume) = no overlap.
//  Component names mirror the carrier's real submodules; "glasses"/"cone*"/"eyeball*"
//  are the physical keep-outs (the glasses body stand-in, see-through cones, eyes).
// =====================================================================
compA = "rail";
compB = "glasses";

include <xreal_one_mount.scad>

module comp(name) {
    if      (name == "rail")     rail();
    else if (name == "clampR")   translate([ clip_x, 0, 0]) brow_hook();
    else if (name == "clampL")   translate([-clip_x, 0, 0]) brow_hook();
    else if (name == "imu")      imu_mount();
    else if (name == "worldR")   world_cam(1);
    else if (name == "worldL")   world_cam(-1);
    else if (name == "eyeR")     eye_cam(1);
    else if (name == "eyeL")     eye_cam(-1);
    else if (name == "pupilR")   pupil_cam(1);
    else if (name == "pupilL")   pupil_cam(-1);
    // split components: each camera's BOOM vs its own HOLDER / physical-PCB keep-out
    // (inside one module these were never checkable, the ball-end-through-plate bug hid here)
    else if (name == "worldR_boom") world_cam(1, render = "boom");
    else if (name == "worldR_hold") world_cam(1, render = "holder");
    else if (name == "worldR_pcb")  world_cam(1, render = "pcbzone");
    else if (name == "eyeR_boom")   eye_cam(1, render = "boom");
    else if (name == "eyeR_hold")   eye_cam(1, render = "holder");
    else if (name == "eyeR_pcb")    eye_cam(1, render = "pcbzone");
    else if (name == "pupilR_boom") pupil_cam(1, render = "boom");
    else if (name == "pupilR_hold") pupil_cam(1, render = "holder");
    else if (name == "pupilR_pcb")  pupil_cam(1, render = "pcbzone");
    else if (name == "pupilR_led")  pupil_led(1);                     // mounted LED bracket (right)
    else if (name == "glasses")  translate([0, 0, -wall]) glasses_dummy();  // preview() offset
    else if (name == "eyeballR") translate(sim2cad([ ipd/2, 0, -28.5])) sphere(12);
    else if (name == "eyeballL") translate(sim2cad([-ipd/2, 0, -28.5])) sphere(12);
    // See-through cone, ELLIPTICAL: the display is 16:9, so the vertical half-FOV (~14.6 deg)
    // is much smaller than the horizontal (25 deg). rig.py's import assert keeps the circular
    // 25-deg cone (conservative, for camera CENTERS); for printed SOLIDS near the brow the
    // circular cone over-flags vertically, so the harness scales z by tan(14.6)/tan(25).
    else if (name == "coneR")    translate(sim2cad([ ipd/2, 0, -28.5])) scale([1, 1, tan(14.6)/tan(25)])
                                     rotate([-90,0,0]) cylinder(h = 44, r1 = 2, r2 = 44*tan(25), $fn = 64);
    else if (name == "coneL")    translate(sim2cad([-ipd/2, 0, -28.5])) scale([1, 1, tan(14.6)/tan(25)])
                                     rotate([-90,0,0]) cylinder(h = 44, r1 = 2, r2 = 44*tan(25), $fn = 64);
    else assert(false, str("unknown component: ", name));
}

intersection() { comp(compA); comp(compB); }

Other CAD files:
_printable_stls/xreal_carrier_FINAL_leds.stl
cad/xreal_one_mount.scad

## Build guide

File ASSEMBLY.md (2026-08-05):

# Assembly, full build, step by step

Builds the **6-camera binocular** rig from the printed **carrier** (`cad/xreal_one_mount.scad`),
mounted with **removable padded brow CLAMPS + M3 thumbscrews** (no adhesive, bonding via
`bond_pads` is the later rigid-phase upgrade). The carrier holds all 6 cameras **and** the IMU
(midline tower); the **LED brackets are 2 separate prints** (`part="led_bracket"`). The XREAL One
Pro's **own padded nose pads** carry the face, no separate printed nose bridge is required.
Wire it to your host through the powered hub. Read `EYE_TRACKING.md` first, especially **§3 IR
eye safety**, and `WIRING.md` for the power + safety interlocks, and `ORDER_LIST.md` for parts.
Allow an afternoon; aiming/focus is the fiddly step.

Cameras (6-cam CORE): **2 world** (outward, on the brow), **2 eye-corner** + **2 NIR pupil**
(eye-facing, one of each per eye). The 8-cam FULL upgrade (+2 stereo) comes later, build the
CORE first.

Legend:  🔧 do  ·  ✅ check  ·  ⚠️ safety

---

## 0. Pre-flight, measure and tune (before printing)

1. 🔧 With **calipers**, measure on your glasses: the **brow thickness**, the **bridge bar
   thickness**, and roughly where each **pupil** sits. Measure your **IPD**.
2. 🔧 In `cad/xreal_one_mount.scad` set `target`, `xr_size`, `ipd`, `xr_brow_z`, `clip_x`,
   `OPTIC_DROP` for your unit (see `cad/README.md`). Leave `build_stereo = false` (6-cam CORE).
3. ✅ Open it in OpenSCAD, **F5 preview**: the eye-facing lenses point at the pupils/canthi,
   no camera sits in the see-through cone (the red cone is the preview guide; `software/cad_fit.py`
   enforces it), the LED brackets sit under each eye (baffled, aimed up at the pupil), and the
   IMU pocket is on the rail.

---

## 1. Print (stiff material, the frame must not flex)

1. 🔧 Print in **SLA resin or PC / nylon-CF** (NOT plain PETG/PLA), stiffness keeps
   camera-to-frame motion < 0.2 mm. 3 perimeters / high infill, brim on thin booms.
   ```
   openscad -D 'part="carrier"' -o carrier.stl  cad/xreal_one_mount.scad
   openscad -D 'part="led_bracket"' -o led_bracket.stl  cad/xreal_one_mount.scad   # both brackets, one file
   ```
   (The IMU tower is part of the carrier; the LED brackets print separately and **bolt onto the
 pupil-holder shelves**, 2 M2 each. `part="bond_pads"` exists for the LATER rigid/bonded phase only.)
   **Print a cheap PLA DRAFT first** (fast settings, supports under the horizontal boom legs),
   dry-fit it on the glasses + your face, and only then print the stiff version.
   ⚠️ **Brow heat (measured on this unit):** the One Pro's brow gets noticeably warm in use , 
   enough to soften PLA over a long session. Keep PLA-draft wear sessions SHORT (fit checks
   only, glasses powered off when possible); the PETG/resin final is unaffected.
2. 🔧 Glue the **1.5 mm carbon-fibre rods** into the boom channels (`cf_rod_d`) for stiffness.
3. ✅ Test-fit the carrier's clamps on the brow **before** populating electronics: jaws over
   the brow taper, silicone pads in, thumbscrews snug. Re-print with adjusted `brow_grip_t` /
   `clamp_clear` if tight/loose.

---

## 2. Prep the cameras (6)

1. ✅ Confirm each **eye-facing** camera (2 eye-corner + 2 NIR pupil) is **mono + global
   shutter + NO IR-cut** (NIR-sensitive). World cams are ordinary visible wide-FOV.
2. 🔧 Fit an **IR-pass filter** over each **NIR pupil** cam lens (passes 940 nm glints, blocks
   visible). The eye-corner cams stay NoIR (no filter).
3. 🔧 Set focus close-range (~2-4 cm to the eye); fine-tune on a live view in step 6.
4. 🔧 **LOCK each M12 lens after final focus** (step 6): tighten the lens locking ring
   (usually included with the module, check on arrival), or a dab of removable
   threadlocker / PTFE tape on the threads. Unlocked M12 lenses unthread with vibration
   and thermal cycling, silently ruining focus calibration.

---

## 3. Populate the carrier (cameras + LED brackets)

1. 🔧 Screw each camera board onto its holder's **4 M2 standoffs** with **SELF-TAPPING M2
   screws** (the 1.8 mm bores are sized for these, NOT heat-set inserts), cable out the notch,
   zip-tied to the strain-relief post. Six holders: worldL/R (brow), eyeL/R (temple),
   pupilL/R (under-eye). There is **no printed lens shroud**: after focusing, baffle stray
   light on the NIR cams with a slip-on collar or matte tape around the M12 barrel.
2. 🔧 Insert the **940 nm IR LEDs** into the **`led_bracket`'s baffled pockets** (2 per eye;
   the baffle keeps each LED recessed + off-axis and ≥ 10 mm from the eye); leads exit the back.
   **Bolt each bracket to its pupil-holder shelf** (2 M2 self-tap). Then twist the leads into
   the IR bundle.
3. ⚠️ **Wire each LED with its own current-limiting resistor (330-470 Ω → ~8-12 mA/LED, 4 LEDs
   ≈ 48 mA total).** Never connect an IR LED straight to 5 V. Low current, strobed, see
   `EYE_TRACKING.md §3`; run the IR 5 V off the **rail, not the XIAO**.
4. 🔧 Common the LED leads into the IR bundle (each LED with its own resistor). This bundle is
   the **strobed IR branch**: keep it as a twisted pair, separate from the data cables.

---

## 4. Mount the IMU (robustness sensor, slip/motion + Kalman drift filter)

1. 🔧 Seat the **MPU-6050** breakout flat in the carrier's IMU pocket (`imu_mount`, on the
   rail), **board X → +x (right), Y → +y (forward)**, M2 screws, so its tilt maps to pose
   `dev[0]`/`dev[2]` as in `software/imu.py`.
2. 🔧 Run the IMU's **I2C** leads (SDA/SCL/3V3/GND) back with the bundle to the strobe MCU.
3. ✅ It must be **rigidly** coupled (no wobble), any flex reads as false tilt that even the
   Kalman drift filter (`imu.py`) shouldn't have to fight.

---

## 5. Wire + power it up (strobed + interlocked, see WIRING.md)

Power tree: **12 V brick → industrial USB 3.0 hub → 5 V/3 A main rail**, split to (a) the 6
bus-powered cameras + hub, and (b) **a 300 mA PTC polyfuse → the IR branch**.

1. 🔧 Cameras (all 6) → the **industrial powered USB 3.0 hub**. Run MJPEG.
2. 🔧 Decouple the 5 V rail at the carrier: **470 µF 10 V electrolytic + 0.1 µF ceramic + a
   SMAJ5.0A TVS** across 5 V/GND.
3. 🔧 IR branch: 5 V rail → **300 mA polyfuse** → the **4 LEDs** (each via its own **330-470 Ω**,
   ~8-12 mA/LED, ~48 mA total); switch the **low side with a 2N7000 logic-level MOSFET** (NOT a
   2N2222) gated by the **MCU** through a 100 Ω series resistor, with a **10 kΩ gate pull-down**
   (fail-safe OFF). ⚠️ **Tap this 5 V from the rail, NOT from the XIAO's 5 V pin** (keeps the
   strobe pulses off the MCU).
4. ⚠️ **Rail monitor:** feed the 5 V rail into a XIAO ADC pin through a **2:1 divider** (two
   equal ~10 kΩ → 5 V reads 2.5 V; firmware ×2). **Never wire 5 V straight to the ADC** (3.3 V
 max, it will fry the pin).
5. 🔧 Trunk wire = **24/26 AWG silicone**; component branches = **30 AWG** only.
6. 🔧 Route the **IR twisted pair separate from the USB data cables**; give the IR branch its
   **own return to the rail's star-ground point** (EM + data-integrity).
7. ⚠️ **IMU: power from the XIAO 3V3 pin, NOT 5 V** (GY-521 boards pull I²C to VCC; 5 V would
   over-volt the XIAO's 3.3 V GPIO). Run its **I2C → the strobe MCU** (Mac path: bridges
   I2C→USB and runs the safety watchdog).
8. ✅ With the host running, all **6** cameras enumerate (+ the MCU as a serial device):
   ```
   cd software && source .venv/bin/activate && python3 main.py --list-cams
   ```

---

## 6. Mount to the glasses + pad + aim/focus (the important step)

1. 🔧 **Clamp** the carrier onto the brow: silicone pads lining both jaws, drop the clamps
   over the brow, tighten the **M3 thumbscrews** until snug (pads take up the brow taper, do
   not crank). Fully removable, no marks. (**Bonding** on the `bond_pads` hard-points is the
   later rigid-phase upgrade once the geometry is proven.)
2. 🔧 **Padding:** the XREAL One Pro's **own padded nose pads** carry the face. The carrier mounts
   to the glasses brow, not skin, but **pad any printed surface that does touch the face** (the
   `brow_pad` recess) with a soft silicone/foam pad. No bare hard plastic on skin.
3. 🔧 Put the glasses on. Open a live view of each eye-facing camera. For each eye:
   - ✅ The **pupil + at least 2 glints** (pupil cam) and the **outer canthus** (corner cam) are
     in frame across your normal gaze range.
   - 🔧 Re-aim the boom (or re-print with tweaked positions) until they stay framed.
   - 🔧 Adjust focus until the **iris texture / canthus is sharp**.
5. 🔧 **Route cables per WIRING.md:** thin leads (IR pair, IMU I2C) in the rail's wire
   groove under the tabs; the 6 fat camera USB cables on the rail's rear top edge, lashed by
   zip ties through the rail's through-slots; bundle exits one rail end, along that temple.

---

## 7. Exposure + IR setup (and the safety pass)

1. 🔧 Set a **short exposure** (global shutter) + gain: pupil reads **dark**, glints read
   **bright** and crisp.
2. 🔧 Flash `firmware/ir_strobe/` to the MCU. ✅ **Verify the fail-safe FIRST:** with the host
   app NOT running, the IR gate is **low (off)** and stays off; unplugging USB kills IR.
3. ⚠️ Now enable strobing and back the **IR current DOWN** to the lowest level that still gives a
   clean pupil + glints. Confirm 940 nm (invisible). Strobe sync ON (pulse only during exposure).
   If you have a meter, verify corneal irradiance well under ~1 mW/cm².
4. ✅ Confirm the interlocks: **blink cutoff** (IR drops when an eye closes), **voltage
   safeguard** (IR disables if the 5 V rail leaves ~4.5-5.5 V), **polyfuse** (a deliberate brief
   short on the bench trips and self-resets). See `WIRING.md §ELECTRICAL SAFETY INTERLOCKS`.

---

## 8. Software bring-up

1. ✅ **IMU drift filter** self-test (no hardware): `python3 main.py --imu-test` → the Kalman
   filter should cancel gyro drift (raw drift ≫ filtered).
2. ✅ **Pupil tracker** self-test: `python3 pupil_tracker.py` → detects the synthetic pupil ~1 px.
3. 🔧 Point it at a real pupil camera and confirm a live lock (`python3 pupil_tracker.py --cam <i>`).
4. 🔧 Capture eye-corner templates, then run the calibration loop:
   ```
   python3 main.py --world-cam-left 0 --world-cam-right 1 --eye-cam-left 2 --eye-cam-right 3 --fullscreen
   ```
   In the loop: **ENTER** approve, **U** undo the last (mis-stored) sample, **Z** cancel the
   current nudge, **Q** quit. `--reset-db` wipes all samples if the data got corrupted.
5. ✅ After ~20-40 corrections across the field, measure overlay error against a known target.

---

## 9. Validate

- ✅ **Tracking stability:** eyes still → steady pupil center (low jitter); during saccades it
  keeps up (global shutter earning its place). The live `GazeStabilizer` smooths fixation jitter.
- ✅ **Calibration accuracy:** overlay error vs a known target is your real result, compare
  honestly to the simulation, not the other way around.
- 🔧 Poor tracking? More even IR (re-aim/add bracket LEDs), better focus, IR-pass filter, shorter
  exposure, re-aim. Illumination usually matters more than the camera.

---

## ⚠️ Safety recap
- 940 nm only, low current (~5-15 mA), spread, **strobed in sync with the shutter**, recessed
  behind baffles **≥ 10 mm from the eye**, powered only while tracking.
- **Fail-safe IR-OFF:** USB/host drop, over/under-voltage, polyfuse trip, blink, or MCU reset all
  cut IR immediately (2N7000 gate pull-down). Verify this before trusting the rig.
- The retina can't feel IR, when unsure, use **less** light. Never use security-camera IR
  illuminators near the eye.

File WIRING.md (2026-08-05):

# Wiring, power & safety, the 6-camera binocular build (XREAL One Pro)

How every camera, LED, and the IMU connects, how the rig is powered, and the electrical
safety interlocks that protect the eye. The authoritative camera geometry is
`software/rig.py`; the carrier that holds them is `cad/xreal_one_mount.scad`; the IR-safety
rationale is `EYE_TRACKING.md §3`; the strobe/interlock logic is `firmware/ir_strobe/`.

---

## The model: 6 cameras, BINOCULAR

The XREAL One Pro has a **display per eye**, so both eyes are tracked and registered.

**CORE = 6 cameras = 2 outward + 4 eye-facing:**

| group | role | cams | sensor | purpose |
|---|---|---|---|---|
| **outward (2)** | `worldL`, `worldR` | 2 | ELP AR0234, visible, wide FOV | the AR dot / forward scene (shared by both eyes) |
| **eye-facing (4)** | `eyeL`, `eyeR` | 2 | OV9281 mono NoIR, global shutter | eye-corner (canthus), glasses-on-face pose |
| | `pupilL`, `pupilR` | 2 | OV9281 mono NoIR + IR-pass | NIR pupil + corneal glints (PCCR), one per eye |

\+ **940 nm IR LED brackets, 2 LEDs per eye = 4 total** (strobed; on the separate printed
`led_bracket` parts under each eye, aimed at the pupil) and a **6-axis IMU (MPU-6050;
ICM-20948 also works)** on the carrier's midline TOWER (flat shelf on the rail top,
board X→+x right / Y→+y forward, the `imu.py` axis contract, only accel + gyro are used).
Honest accuracy: ~4.3 px PERCEIVED deployed (vernier UI + per-user offset, simulated with realistic user error), 0.89 px pipeline bound; the <1 px pathway (stereo + multi-vergence kappa) awaits hardware validation.

> **FUTURE UPGRADE (separate tier, not the 6-cam model): 8-camera FULL.** Adds `eye2L`,
> `eye2R` (a stereo eye-corner cam per eye), the accuracy upgrade. Build and validate the 6-cam CORE
> first; the stereo pair is the higher-accuracy evolution that comes after. In software it is
> the `use_stereo` / `build_stereo` path and is off by default.

```
  carrier (bonded to the frame)                         host
   worldL,R ───USB──┐
   eyeL,eyeR ──USB──┤      ┌─ industrial powered USB 3.0 hub ─┐
   pupilL,R(NIR)USB─┤ 6×USB┤   (own 12 V PSU -> 5 V/3 A rail) ├─USB─► Mac
   IR bracketsL,R ─► MCU(XIAO): strobe + IMU I2C→USB ───────USB──┘
   IMU ──I2C──► MCU
```

The 6 UVC cameras run **MJPEG** so they fit one good industrial USB 3.0 hub's bandwidth.
(See the bandwidth note at the bottom; the 8-cam FULL upgrade is what pushes you to a Jetson
/ a second host controller.)

---

## Power architecture

One AC source feeds everything: a **single industrial USB 3.0 hub with its own 12 V power
supply**, which regulates down to a **5 V / 3 A (15 W) main rail**. Nothing is drawn from the
Mac's port for power.

> ### ⚠️ Three wiring details that protect parts (get these right)
> 1. **IMU on 3.3 V, never 5 V.** Power the MPU-6050 from the XIAO **3V3** pin. Many GY-521
>    boards pull SDA/SCL up to VCC, so 5 V would drive the I²C lines to 5 V and **over-volt the
>    XIAO's 3.3 V GPIO (abs-max ~3.6 V).**
> 2. **Rail-monitor ADC needs a 2:1 divider.** The XIAO ADC maxes at 3.3 V, feed the 5 V rail
>    through **two equal ~10 kΩ resistors** (5 V → 2.5 V), never straight in. (Resistors are in
>    the kit.)
> 3. **IR 5 V + the divider tap the RAIL, not the XIAO's 5 V pin**, keeps the pulsed strobe
>    current off the MCU's power path.
>
> All three are buildable with parts already in the BOM, no extra components.

```
  AC mains
   └─ 12 V DC brick (the industrial hub's own PSU)
        └─ INDUSTRIAL USB 3.0 HUB  (12 V in → regulates to 5 V)
             └───────────────  5 V / 3 A (15 W) MAIN RAIL  ───────────────┐
                  │   decoupling: 10 V 470 µF electrolytic + 0.1 µF        │
                  │   ceramic across the rail at the carrier (stabilises   │
                  │   the 5 V against the pulsed IR load + camera inrush)  │
                  │                                                        │
       ┌──────────┴───────────┐                          ┌────────────────┴───────────────┐
       │ CAMERAS + hub logic  │                          │ 300 mA PTC POLYFUSE             │
       │ (6× UVC, bus-powered │                          │   └─► IR branch (on carrier):   │
       │  5 V on their own    │                          │     IR LED brackets 2×/eye 940nm│
       │  USB cables)         │                          │        switched by a 2N7000     │
       └──────────────────────┘                          │        MOSFET (MCU strobe)      │
                                                          └────────────────────────────────┘
```

- **12 V → hub → 5 V/3 A rail.** The hub's internal regulator is the 5 V/3 A (15 W) source.
  At MJPEG / modest resolution (~0.25-0.35 A per UVC camera) the 6 cameras draw ~1.5-2.1 A,
  leaving headroom for the low-current IR (**~0.05 A: 4 LEDs × ~12 mA**) + IMU branch. ⚠️
  **Verify your cameras' actual draw**, at full resolution 6 cams can approach the 3 A limit;
  if so, raise the rail budget (a higher-current industrial hub) or run lower resolution.
 (The SABRENT 60 W / 12 V-5 A hub supplies ~5 A at 5 V, comfortable margin over 3 A.)
- **The rail SPLITS two ways:**
  1. **Cameras + hub controller**: the six cameras are USB **bus-powered**, taking clean 5 V
     from the hub's own ports. No separate camera PSU.
  2. **300 mA PTC polyfuse → IR-bracket branch**: the IR branch taps the 5 V rail
     through a **resettable 300 mA polyfuse** so any IR-side short or overcurrent trips the
     branch open (and self-resets after power-down) without taking down the cameras.
     ⚠️ **Tap this 5 V from the rail (a hub-port 5 V), NOT through the XIAO's 5 V/VBUS pin** , 
     so the pulsed strobe current stays off the MCU's power path. The XIAO only supplies the
     *gate signal* and reads the rail (below).
- **Decoupling caps:** a **10 V 470 µF electrolytic** (bulk) **+ a 0.1 µF ceramic** (HF) sit
  across the 5 V rail at the carrier. The bulk cap absorbs the IR strobe's pulsed current and
  camera inrush so the rail doesn't sag/ring; the ceramic kills high-frequency switching
  noise. Place one set near the IR driver, one near the camera hub feed.

### Wire gauge
- **Main 5 V trunk** (hub → carrier): **24 or 26 AWG silicone wire**: low resistance so the
  rail holds 5 V under the full 3 A with minimal drop and warmth. Use a separate matched
  return of the same gauge.
- **Individual component branches** (a single LED string, the IMU 3V3, one cap lead):
  **30 AWG silicone** only, thin and flexible so the bundle stays light on the face.
- Never run the 3 A trunk on 30 AWG.

### IR power vs data, EM separation + star ground
The IR LEDs are **pulsed** (strobed in sync with the shutter), so their supply current is a
square wave that will couple into nearby high-speed USB data if you let it. Two rules:

1. **Separate the pulsing IR power lines from the data lines.** Run the IR V+/return as their
   own **twisted pair**, physically routed away from the USB camera cables (cross at 90°, never
   bundle them parallel for any length). This kills the magnetic-loop coupling.
2. **Isolated return / STAR GROUND.** The IR branch gets its **own return conductor back to a
   single star-ground point** at the 5 V rail, it does **not** share the camera/data ground
   along its length. That keeps the pulsed IR current out of the data ground, so it can't
   create ground-bounce on the USB signals. One star point; IR ground and data ground meet
   only there.

---

## ⚠️ Electrical SAFETY INTERLOCKS (all default to IR-OFF, fail-safe)

The retina cannot feel IR (no blink reflex to warn of overexposure), so the IR drive is built
**fail-safe**: it is OFF unless the MCU is **actively** driving it during an exposure window,
with the host connected and the rail in spec. Logic lives in `firmware/ir_strobe/`.

1. **Strobe in sync with the shutter.** The MCU pulses the IR only during each camera's
   exposure window (a few hundred µs), not continuously. Average IR power = peak × duty cycle
   (≪ 1), so dose and heat are a fraction of continuous-on. The 2N7000 gate is driven only
   inside that window.
2. **USB drop instantly kills IR.** The MCU requires a periodic host heartbeat over USB; if
   the USB/serial link drops (unplug, host sleep, app crash), a **watchdog forces the 2N7000
   gate low within one frame** → IR off. (And because the LEDs are powered from the hub's 5 V
   rail, pulling USB/host power also de-energises them outright.)
3. **Voltage safeguard.** The MCU watches the 5 V rail on an ADC; if it leaves a safe window
   (≈ 4.5-5.5 V, brownout, regulator fault, wrong PSU) it disables the strobe. ⚠️ **The XIAO
   ADC maxes at 3.3 V, so the 5 V rail MUST feed it through a 2:1 resistor divider** (two equal
   ~10 kΩ from the resistor kit; 5 V → 2.5 V, so firmware scales the reading ×2). **Never feed
 5 V straight into the ADC pin, it will damage it.** A **TVS diode / clamp** (SMAJ5.0A)
   across the rail handles fast transients; the polyfuse handles sustained overcurrent.
4. **Polyfuse overcurrent protection.** The **300 mA PTC** in series with the IR branch trips
   open on any IR-side short/overcurrent and self-resets after power-down, overcurrent can
   never drive the LEDs (or the wiring) to a dangerous level.
5. **IR cutoff on blinks.** The host runs `software/blink.py`; on a detected blink it commands
   the MCU to drop that eye's IR for the closure. No point illuminating a closed lid, it cuts
   heat build-up and average dose with zero tracking cost.
6. **Any power anomaly → IR off immediately.** Brown-out, over/under-voltage, polyfuse trip,
   watchdog timeout, or MCU reset all converge on the same state: **gate low, IR off.** A
   gate **pull-down resistor** guarantees OFF during power-up and any MCU reset.
7. **Mechanical IR keep-out (see CAD).** A printed **baffle/standoff** around each LED keeps
   the emitter recessed and ≥ 10 mm from the eye and blocks any close-range direct path
   (`ir_baffle` in `cad/xreal_one_mount.scad`): the electrical limits and the mechanical
   block back each other up. Run each LED at ≈ 5-15 mA through its resistor regardless.

---

## Connection table

| Item | Connector | To | Power | Notes |
|---|---|---|---|---|
| World cam L / R | USB | hub | bus 5 V | visible, wide FOV, shared by both eyes |
| Eye-corner cam L / R | USB | hub | bus 5 V | OV9281 mono global shutter, NoIR |
| NIR pupil cam L / R | USB | hub | bus 5 V | OV9281 mono + IR-pass filter (one per eye) |
| IMU 6-axis (MPU-6050; ICM-20948 OK) | I2C (SDA/SCL/**3V3**/GND) | strobe MCU (Mac path) | ~5 mA, **3.3 V, NOT 5 V** | ⚠️ power from the XIAO **3V3** pin: many GY-521 boards pull SDA/SCL up to VCC, so 5 V would push the I²C lines to 5 V and **over-volt the XIAO's 3.3 V GPIO**. Rigid on the midline tower; accel+gyro for slip + Kalman drift (`imu.py`) |
| IR LED brackets (2 LEDs/eye = 4) | twisted pair | 5 V rail **via 300 mA polyfuse**, low-side **2N7000** | ~8-12 mA/LED (330-470 Ω each), ~48 mA total | 940 nm; strobed; per-LED resistor; 5 V tapped from the **rail, not the XIAO**; **isolated return / star ground** |
| Strobe MCU (Seeed XIAO) | USB | Mac | bus | strobes IR (2N7000), bridges IMU I2C→USB, runs the safety watchdog |
| **10 kΩ gate pull-down** | XIAO strobe GPIO → GND | at the MOSFET gate |, | GPIOs FLOAT during MCU boot/reset; the pull-down holds the gate OFF until firmware takes over (the LEDs would only reach the resistor-limited safe current anyway, Rule 7, but a floating gate must not flash them at all) |
| Industrial USB 3.0 hub | USB-C/A + 12 V brick | Mac + AC | 12 V → 5 V/3 A | the 5 V/3 A (15 W) main rail; self-powered |
| Decoupling |, | across 5 V rail |, | 10 V 470 µF electrolytic + 0.1 µF ceramic |

---

## Pin map, Seeed XIAO RP2040 (exact connections)

| XIAO pin | Connects to | Wire | Function |
|---|---|---|---|
| **D0** (GPIO26) | 100 Ω series → 2N7000 **gate**; **10 kΩ pull-down** gate→GND at the FET | 30 AWG | IR strobe control (LOW = off; floats-at-boot held off by the pull-down) |
| **D4** (GPIO6, SDA) | MPU-6050 **SDA** | 30 AWG (twisted with SCL) | IMU I²C data |
| **D5** (GPIO7, SCL) | MPU-6050 **SCL** | 30 AWG | IMU I²C clock |
| **3V3** | MPU-6050 **VDD** (⚠️ **3.3 V, NOT the 5 V pin**, keeps its I²C at 3.3 V) | 30 AWG | IMU power (~5 mA) |
| **A1** (GPIO27, ADC) | **2:1 divider midpoint** (5 V rail → 10 kΩ → A1 → 10 kΩ → GND) | 30 AWG | rail monitor; reads ~2.5 V at 5 V, firmware ×2. ⚠️ never wire 5 V straight to A1 |
| **GND** | MPU-6050 GND + 2N7000 **source** + IR-branch return + divider bottom (star point) | 30 AWG | common ground, ONE star point at the perfboard |
| **USB-C** | Mac (direct or dock, NOT through the camera hub) | stock | power + serial (IMU stream out, strobe/watchdog control in) |

2N7000: **drain** → IR LED cathode rail; LED anodes → per-LED 330-470 Ω → 5 V **via the
300 mA polyfuse** off the hub rail (~48 mA total, 4 LEDs). 470 µF + 0.1 µF + SMAJ5.0A TVS
across 5 V/GND at the perfboard. **The IR 5 V and the ADC divider both tap the RAIL, not the
XIAO's 5 V pin.** Firmware contract: gate LOW at boot, RP2040 **hardware watchdog** armed
before the first strobe, any host silence > 500 ms ⇒ gate LOW + watchdog reset.

## Cable routing on the glasses (comfort + strain relief + EM)

1. **Thin leads** (IR twisted pair, IMU I2C) lie IN the carrier rail's wire groove (top-rear,
   3×2.5 mm, under the retaining tabs). **Fat stock USB cables** (all 6 cameras) lie ON the
   rail's rear top edge, lashed by zip ties through the rail's 4 through-slots (x ±8 / ±25).
2. The combined bundle exits at ONE rail end and runs along that **temple arm** to the tip
   (centred loads only in the groove, so nothing tugs one nose pad).
3. **Keep the IR twisted pair separate from the USB data cables** inside the bundle, a thin
   spiral wrap or its own channel; cross other cables at 90°, never parallel-bundle for length.
4. **Strain-relieve at two points**: a clip at the bridge and one at the temple tip, so a
   yank is taken by the frame, not the nose or a solder joint.
5. **Main 5 V trunk = 24/26 AWG silicone; component branches = 30 AWG.**

---

## Bring-up sequence (electrical)

1. Plug the hub's **12 V brick into the wall first**, then the cameras into the hub, then the
   hub to the Mac. (Rail up before devices = clean enumeration.)
2. Confirm the **5 V rail reads 4.9-5.1 V** under load before energising IR.
3. `python3 software/main.py --list-cams` → you should see **6** camera indices. Note which
   is which (worldL/R, eyeL/R, pupilL/R).
4. Flash `firmware/ir_strobe/` to the XIAO. Verify the **fail-safe**: with the host app NOT
   running, the IR gate is **low (off)** and stays off.
5. Only then enable IR strobing **at low current**, with the host running. ⚠️ 940 nm, ~5-15 mA,
   spread out, strobed, see `EYE_TRACKING.md §3`.
6. `python3 software/pupil_tracker.py --cam <pupil-index>` → confirm a live pupil lock.

---

## Bandwidth note

Six UVC MJPEG streams fit a single quality **industrial** USB 3.0 hub on one Mac controller;
that is why the build standardises on one hub (and one 5 V/3 A rail). The **8-camera FULL
upgrade** (+2 stereo) is the case that exceeds one controller's headroom → split across a
second powered hub on a separate host port, or move to a **Jetson Orin Nano** (the cameras
stay UVC, so the capture code ports with little change). Run MJPEG either way.

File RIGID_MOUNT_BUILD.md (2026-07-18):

# Rigid‑Mount Build, design + complete order list

Why rigid (not a clip): the camera‑to‑display geometry must be a **fixed, one‑time‑calibrated
constant**, not a per‑use unknown. If it flexes it becomes a second unknown confounded with the
eye geometry (under‑determined, can't solve). The sim's whole premise is that this geometry is
constant and factory‑calibratable. Target: **camera‑to‑frame motion < 0.2 mm / 0.2°** (1 mm/1° =
+1.3 px, more than the entire accuracy budget, from the flex sweep in simulation; the
`data/` outputs are generated locally and not committed).

The glasses are the rigid reference: **XREAL One Pro** front frame (flat X‑prism optic, ~11 mm
front, 87 g). We bond a single stiff camera carrier to it.

---

## 1. Mount design

### Architecture
One **monolithic carrier** holds every sensor at the exact positions in `software/rig.py`.
The **6‑camera binocular CORE** = world ±[33.5,44,5] (2) + eye‑corner ±[69.5,−2,−6] (2) + NIR
pupil ±[25.5,−33,6] (2, one per eye); the **8‑cam FULL** future upgrade adds the stereo
eye‑corner pair ±[69.5,−16,−10] (optic‑centre origin, MEASURED IPD 67). World cams RAISED 30→44
(2026‑07‑02): at 30 the 38 mm board's lower standoffs + PCB edge sat inside the glasses BROW , 
found by `software/cad_overlap.py`, the printed‑solid vs glasses/cone/eyeball intersection check. These positions are **WEARABLE**:
the real 36-38 mm camera boards
clear the see‑through cone, the eyeball, **and the facial surface** (so the glasses still rest
normally on the nose + ears), verified by `software/cad_fit.py` (cone + eyeball) and
`software/wearable.py` (face). The eye cams sit at the temple with their boards extending **out**
to the temple (not deep into the gap, where a 36 mm board would jam into the cheek). The carrier
couples to the front frame two ways, pick one:

- **A. Bonded (recommended, most rigid).** Epoxy the carrier's 3 hard‑points (brow centre + both
  temple corners, `bond_pads()` in `xreal_one_mount.scad`) to the front frame. Semi‑permanent;
  makes cameras + display effectively one body. Best dimensional stability.
- **B. Kinematic (rigid *and* removable).** Bond 3 steel balls to the frame; the carrier has 3
  mating vee/cone seats + magnet preload → seats to microns, repeatably → no re‑calibration on
  re‑mount. Choose this only if the glasses must come off intact.

### Camera holders (they actually hold the modules)
Each camera (6 CORE / 8 FULL) mounts as its **real board**, not an abstract pocket: the carrier gives every
camera a **backing plate + 4 standoffs at the module's mount pitch** (≈28 mm for the OV9281;
**self-tapping M2 screws** into 1.8 mm bores + zip-tie backup slots, the PCB screws on), the **M12 lens looks out through open air**, and a
**cable‑exit notch** clears the connector. The optical centre (front of the M12 lens) sits at the
`rig.py` position; the PCB sits ~10 mm behind it, so the board stays out of the see‑through cone
(`board_cam` / `camera_holder` in `xreal_one_mount.scad`). Module footprints the holders are built
for: **ELP AR0234 USB 38×38 mm** (world), **Arducam OV9281 USB 36×36 mm** (eye/stereo/pupil). Run
`python3 software/cad_fit.py` after any position change, it re‑checks that the real boards still fit.

### Stiffening (stacks with A or B), the frame must be STIFF
- **Carbon‑fibre rod** (1.5 mm) glued through each cantilevered eye‑corner/pupil boom, `cf_rod_d`
  in the CAD bores the channel; CF beam ≈ 10× stiffer than PETG.
- **Print the carrier in a stiff material:** SLA resin (most rigid/precise) or PC / nylon‑CF FDM.
  Avoid plain PETG/PLA for the carrier. Short, thick, ribbed booms; a spread **truss** (two
  struts + root tie per boom, in `cam_at`) so no cantilever can sag or resonate.
- **IMU** in a rigid pocket on the carrier, board axes X→+x, Y→+y (`imu_mount`, matches `imu.py`).
  Rigid coupling matters: any flex reads as false tilt before the Kalman drift filter sees it.

### Face-contact padding + IR keep-out (comfort + safety)
- **Pad every printed surface that touches the face.** Each face-contact pad (nose pads, any
  brow/cheek rest) is a recess that takes a **soft silicone / PORON foam pad**: no bare hard
  plastic on skin. Round all edges (the CAD does).
- **IR blocking / standoff.** Each IR LED sits in a printed **baffle** that keeps it recessed
  and **≥ 10 mm from the eye** and blocks any close-range direct path (`ir_baffle` in
  `xreal_one_mount.scad`): the mechanical block backs up the electrical current/strobe limits.

### One‑time rig calibration (this is what "rigid" buys you)
Before/after bonding, calibrate the camera→display geometry **once** with a checkerboard imaged
through the optic from an **eyebox camera** (reuse a spare OV9281 or even a phone camera placed at
the eye position, no new part needed), store it as the fixed device extrinsics, and never touch it. A printed **bonding jig** holds the carrier at the correct pose relative to the frame while
the epoxy cures, accuracy of the bond depends on it.

### Build order
print carrier → press in cameras/IMU + glue CF rods → wire + strain‑relieve → mount on bonding
jig at correct pose → factory‑calibrate rig geometry → epoxy (or kinematic‑seat) to frame → cure
→ verify rigidity (wiggle test < 0.2 mm) → per‑user eye calibration.

---

## 2. Order list

Prices are rough CAD, verify at checkout. **CORE** = first build (honest sim accuracy ~4.3 px perceived with the vernier
calibration UI). **STEREO/▲** = upgrades for margin (~0.5 px), add after core works.

### A. Display + compute
| ✔ | tier | part | qty | ~CAD | notes / search |
|---|---|---|---|---|---|
| ☐ | core | **XREAL One Pro** AR glasses | 1 | 600-700 | the display + rigid frame; USB‑C DP. "XREAL One Pro" |
| ☐ | core | **Mac** (host) | have |, | USB‑C w/ DisplayPort‑alt‑mode (drives the glasses) |
| ☐ | ▲ | **NVIDIA Jetson Orin Nano** dev kit | 1 | 400-500 | **needed for the 8‑camera FULL stereo build** (USB bandwidth); the 6‑cam CORE runs on the Mac |

### B. Cameras + lenses
| ✔ | tier | part | qty | ~CAD ea | notes |
|---|---|---|---|---|---|
| ☐ | core | **NIR global‑shutter mono cam** (Arducam **OV9281** USB, **no IR‑cut**, M12), eye‑corner ×2 + NIR pupil ×2 (one per eye, binocular) | 4 | 75-95 | global shutter (freezes saccades), NIR‑sensitive, mono |
| ☐ | ▲ | same OV9281, **stereo** 2nd eye‑corner pair (8‑cam FULL upgrade) | +2 | 75-95 | second view per eye → triangulates canthus/CoR depth (1.5→1.15 px) |
| ☐ | core | **World camera** (ELP 2 MP wide‑angle USB, ~70-100°) | 2 | 40-55 | forward, at the pupils; sees the target/scene |
| ☐ | core | **M12 lens assortment** (90° eye, 55° pupil, 70° world) | 1 kit | 15-25 | if modules' stock lenses don't match the FOVs in `rig.py` |

### C. NIR illumination (PCCR for the pupil cam + lighting the eye‑corner cams)
| ✔ | tier | part | qty | ~CAD | notes |
|---|---|---|---|---|---|
| ☐ | core | **940 nm IR LEDs**, 3 mm (NOT 850 nm) | 1 pack (20-50) | 10-15 | spread around both eyes for even light + glints |
| ☐ | core | **IR‑pass filter** 850-1000 nm (one per NIR cam) | 3 (▲5) | 10-18 ea | passes 940 nm, blocks visible |
| ☐ | core | **Resistor kit** (need 330-470 Ω, ~10 mA/LED) | 1 | 10-14 | one current‑limit resistor per LED |
| ☐ | core | **Seeed XIAO** (SAMD21/RP2040) or Arduino Nano | 1 | 10-20 | strobes the LEDs, bridges IMU I²C→USB, runs the safety watchdog (`firmware/ir_strobe/`) |
| ☐ | core | **2N7002 logic‑level MOSFET** (low‑side IR strobe; NOT a 2N2222 BJT) | 1 pack | 8-12 | switches from 3V3, gate pull‑down = fail‑safe OFF |
| ☐ | core | **300 mA PTC polyfuse** + **470 µF 10 V caps** + **0.1 µF** + **5 V TVS** | 1 ea | 10-16 | IR‑branch overcurrent + 5 V rail decoupling + transient/voltage safeguard |
| ☐ | core | **Perfboard** | 1 | 9-13 | tidy LED + resistor + MOSFET board |

### D. IMU (robustness, slip/bump/motion, not geometry ID)
| ✔ | tier | part | qty | ~CAD | notes |
|---|---|---|---|---|---|
| ☐ | core | **6/9‑axis IMU** (ICM‑20948 or BNO055) breakout | 1 | 15-28 | rigid on the carrier; 3V3 logic |

### E. Mounting / structural, the rigid mount
| ✔ | tier | part | qty | ~CAD | notes |
|---|---|---|---|---|---|
| ☐ | core | **Rigid print material:** SLA resin **or** PC / nylon‑CF filament (1 kg) | 1 | 40-70 | the carrier MUST be stiff; not plain PETG/PLA. No printer → use a print service |
| ☐ | core | **Carbon‑fibre rod, 1.5 mm** (pack) | 1 | 10-15 | reinforce the eye‑corner booms (`cf_rod_d`) |
| ☐ | core | **Structural epoxy** (2‑part, plastic‑bonding e.g. JB Weld PlasticWeld / 3M DP) | 1 | 10-15 | bonds carrier to the frame; **+ isopropyl + abrasive** for surface prep |
| ☐ | core | **Self-tapping M2 screw assortment** (bores are 1.8 mm; inserts don't fit) | 1 | 10-18 | secure cameras + IMU in the carrier |
| ☐ | ▲ | **Kinematic kit:** 3× 6 mm precision steel balls + 3× neodymium magnets | 1 | 10-20 | only if you want it removable (Option B) |
| ☐ | core | **Bonding/alignment jig** | printed |, | holds the carrier at the correct pose while epoxy cures (print from the CAD) |

### F. Wiring / connectivity
| ✔ | tier | part | qty | ~CAD | notes |
|---|---|---|---|---|---|
| ☐ | core | **Industrial powered USB 3.0 hub w/ own 12 V PSU** | 1 (▲+1) | 40-70 | regulates 12 V → the **5 V/3 A (15 W) main rail**; one hub carries the 6‑cam CORE, ▲ a 2nd hub/Jetson for the 8‑cam FULL |
| ☐ | core | **USB‑C dock / multiport adapter** | 1 | 25-45 | the glasses take one Mac USB‑C (DP‑alt) and the hub another; a dock frees ports |
| ☐ | core | **Short USB cables / micro‑USB leads** for each camera | ~6 (▲8) | 3-6 ea | keep short; strain‑relieved |
| ☐ | core | **24/26 AWG silicone** (5 V trunk, 3 A) **+ 30 AWG silicone** (component branches) + heat‑shrink | 1 | 16-24 | trunk vs branch gauges; keep the IR pair separate from data (star ground) |
| ☐ | core | **JST‑SH connectors / Kapton tape** | 1 | 10-15 | tidy detachable joints + stray‑light baffling |

### G. Calibration + tooling
| ✔ | tier | part | qty | ~CAD | notes |
|---|---|---|---|---|---|
| ☐ | core | **Digital calipers** | 1 | 20-30 | measure the frame + your IPD to tune the CAD |
| ☐ | core | **Checkerboard / calibration target** (rigid, printed on flat board) | 1 | 15-30 | for the one‑time camera→display rig calibration |
| ☐ | core | **Soldering iron kit** | if needed | 30-55 | LED/wire work |
| ☐ | core | **Gamepad** (8BitDo / Xbox wired) | 1 | 30-60 | nudge / vernier alignment input |
| ☐ | ▲ | **IR / optical power meter** | 1 | 45-75 | verify corneal IR is eye‑safe (< ~1 mW/cm²), borrow if possible |

### H. Comfort / consumables
| ✔ | tier | part | qty | ~CAD | notes |
|---|---|---|---|---|---|
| ☐ | core | **Adhesive silicone nose pads** | 1 | 8-12 | comfort on the bridge module |
| ☐ | core | **Soft silicone / PORON foam pad stock** | 1 | 6-10 | pad **every** printed face‑contact surface (no bare hard plastic on skin) |
| ☐ | core | **Foam / Kapton tape** | 1 | 8-12 | baffle stray light around the eye cams |

---

## 3. Rough totals
- **CORE (6 cameras, Mac, bonded):** XREAL ~650 + 4 OV9281 ~340 + 2 world ~95 + IMU ~22 +
  IR/driver + protection (2N7002/polyfuse/caps/TVS) ~70 + filters ~45 + mount/epoxy/CF/inserts
  ~120 + industrial 12 V hub ~60 + wiring ~45 + calipers/target ~60 ≈
  **CA$1,550-1,850** (assumes you own a printer + soldering gear).
- **FULL/▲ upgrade (8 cameras):** +2 OV9281 ~190 + Jetson ~450 + 2nd hub ~40 + extra filters ~36 ≈
  **+CA$700-800**.

---

## 4. Don't‑miss / verification checklist
1. **Cameras (6 core / 8 full):** 2 world + 2 eye‑corner + 2 NIR pupil (one per eye), +2 stereo ▲
  , matches `rig.py` roles. Eye/pupil = global‑shutter mono NIR; world = wide‑angle. ✔
2. **Illumination:** 940 nm LEDs (both eyes) + per‑NIR‑cam IR‑pass filter + resistors + strobe
   MCU + **2N7002 MOSFET**; eye‑safety meter. (850 nm is wrong, visible + higher hazard.) ✔
3. **Power + safety:** 12 V → industrial hub → **5 V/3 A rail**; split to cameras+hub and (via a
   **300 mA polyfuse**) to IR; **470 µF/0.1 µF** decoupling, **TVS** clamp; strobe‑sync, USB‑drop
   kill, voltage safeguard, blink cutoff, fail‑safe‑OFF (`WIRING.md`/`firmware/ir_strobe/`). ✔
4. **Rigidity + padding:** stiff carrier material + CF rods + truss booms + structural epoxy
   (+ surface prep); bonding jig; **soft pads on all face‑contact surfaces**;
   **IR baffle ≥10 mm standoff**. ✔
5. **Compute/bandwidth:** the **6‑cam CORE** runs on Mac + one industrial hub; the **8‑cam FULL**
   needs a 2nd hub or a Jetson, UVC streams saturate USB. MCU also bridges the IMU's I²C. ✔
6. **Calibration/fit/tools:** checkerboard + eyebox view for the one‑time rig calibration; calipers
   to set IPD/`OPTIC_DROP`/vertex in the CAD; keyboard arrow keys for alignment (vernier.py); nose pads + baffling. ✔

Open hardware unknowns to settle by measurement (not simulation): the XREAL front‑frame material
(epoxy compatibility), the true vertex distance (~4.5 mm sim/CAD gap), and real human alignment
precision (sets how close the kappa calibration gets to the sub‑1 px result).

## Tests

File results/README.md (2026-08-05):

# Results: SIMULATION only

Everything in this directory is a **simulation** result: no number here is a hardware
measurement. I generated these in July 2026, before the rig existed, to decide whether the
approach was worth building. The hardware now exists and its measurements live in the dated
session write-ups at the repository root, not here.

- **`kappa_separation.png`**, the angle-kappa / perceptual-bias confound, and the
  multi-distance way around it. Generated 2026-07-13 by `python3 software/kappa.py`.
  - *Left:* overlay error vs the number of the user's own corrections. Against geometric
    truth the error plateaus at **~9 px**, the kappa + perceptual-bias confound that a
    single-condition calibration cannot separate.
  - *Right:* registration error across target distances 300–1800 mm. Calibrating at a
    **single distance** mistakes the vergence-accommodation bias for a constant and
    carries **13.0 px** median to other distances; regressing **across distances**
    separates kappa (the constant) from the vergence bias (the slope) and holds
    **2.4 px** median everywhere, no extra hardware.
- **`kappa_run.log`**, the raw program output the plot numbers were taken from.

Reproduce: `cd software && python3 kappa.py` (numpy only; the raw `data/` experiment
outputs referenced elsewhere are generated locally and are not committed).

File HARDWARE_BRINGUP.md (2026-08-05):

# Hardware bring-up: plugging the rig into the Mac

Everything below runs from `software/` in the venv:

```bash
cd ~/ar-eye-calibration/software
source .venv/bin/activate      # numpy + opencv (already installed)
```

The whole stack is **simulation-first**: every module has a `--selftest` that runs headless with
no cameras, so the logic is proven before hardware. `python3 verify_all.py --fast` runs them all
as part of the release gate.

## The 6 cameras → roles

The pipeline addresses cameras by **role**, not by USB index:

| Role | Sensor | What it sees |
|---|---|---|
| `worldL`, `worldR` | AR0234 color, 1280 | the real world (stereo), the mesh + overlay register to this |
| `eyeL`, `eyeR` | OV9281 mono NoIR, 640 | outer eye corner (canthus), how the glasses sit on the face |
| `pupilL`, `pupilR` | OV9281 mono NoIR, 640 | the IR-lit pupil + glints (dark-pupil / PCCR gaze) |

### 1. Map the cameras (once)

```bash
python3 connect.py --auto        # probe + classify: splits 2 color/1280 world vs 4 mono/640
python3 connect.py --identify    # live view; press 1-6 to confirm each role, s to save
python3 connect.py --show        # print the saved map (data/rig_cameras.json)
```

`--auto` classifies by color-vs-mono and resolution automatically. It can't tell **L from R** or
**eye from pupil** from a static frame, so confirm those with `--identify` (or the IR-strobe test
in `rig_test.py`, where only the pupil cams brighten when the LEDs pulse).

### 2. Test the rig is fit to use

```bash
python3 rig_test.py --run        # enumerate · per-role fps · SYNC JITTER · IR test · FOCUS
```

Watch for: every role **OK**, `fps ≥ 30`, **sync jitter under your budget** (default 3 ms), the
2 pupil cams showing a positive **IRΔ** when strobed, and each `focus` high (set the lenses now , 
they're glued after). A `CHECK` row tells you which camera to fix.

### 3. Grab synchronized snapshots

```bash
python3 snapshot.py              # one synchronized set -> data/snapshots/<stamp>/
python3 snapshot.py --burst 20   # 20 sets (e.g. a calibration sweep)
```

Each set is 6 PNGs + `meta.json` carrying the timestamps, measured `jitter_ms`, and a `synced`
flag. A smeared (over-budget) set is saved but flagged `synced:false` so it never becomes a
calibration sample by mistake.

## Synchronous capture

`sync_capture.SyncBank` runs one background thread per camera parked on a shared **barrier**; a
`sync_frame()` releases them together so all six `grab()` calls fire in the same window
(global-shutter OV9281 + AR0234 ⇒ a genuinely comparable set). Every set reports `jitter_ms` , 
the honest spread of capture instants. In the selftest the barrier holds ~0.2 ms vs ~60 ms for a
naive one-at-a-time sweep. For tighter-than-software sync, strobe the IR LEDs
(`firmware/ir_strobe`) inside the shared exposure window.

```bash
python3 sync_capture.py --probe  # open real cameras, print live jitter
```

## The image constantly adjusts itself

`autoexpose.AutoExposureBank` closes an exposure/gain loop **per role, every frame**:

- **world** → mid-gray, exposure capped so motion stays sharp for the mesh tracker;
- **eye-corner** → mid-toned canthus for stable template matching;
- **pupil** → the *glints* (99th percentile) sit just under clipping while the field stays dark , 
  the opposite of consumer auto-exposure, which would blow the glints out.

It keeps adjusting as the light changes and settles without hunting.

## Real-world mesh tracking

`world_mesh.py` turns the two world cameras into a live model of the real world:

1. **triangulate** ORB features matched across the stereo pair → 3D points (left-cam frame);
2. **track** them frame-to-frame (optical flow) and solve the rigid **camera motion** with a
   robust Kabsch fit (RANSAC + Tukey-IRLS rejects mismatched features);
3. **fuse the IMU**, `imu_serial.GyroIntegrator` integrates the gyro into a per-frame rotation
   increment, used as a prior and to carry the pose through a visual dropout;
4. **maintain the mesh**, a growing cloud of world map points + a Delaunay surface over the
   visible ones. This is the frame the AR overlay locks onto as the head moves.

The geometry is proven in numpy (`--selftest` recovers a known trajectory + map, survives 25%
feature outliers, and shows the IMU carrying a dropout). On hardware `WorldTracker` feeds it
ORB/LK features from the world cams.

## Run everything together

```bash
python3 live_rig.py --run          # sync grab -> auto-expose -> mesh track -> feature capture
python3 live_rig.py --run --imu    # also fuse the XIAO gyro
```

One loop: `SyncBank` → `AutoExposureBank` → `WorldTracker`/`WorldMesh` → `capture.LiveCapture`
features, printing live telemetry (fps, jitter, exposure-settled, mesh size, camera pose,
tracking health). This is the "cameras capture synchronously and constantly track + adjust the
image" driver.

## USB / power notes

Six UVC streams need a **powered USB hub** and MJPG (already set) to fit the bandwidth; if a
camera drops out under load, lower `fps` in `SyncBank` or the world resolution. Running 6 cameras
+ the IMU is I/O-bound, not CPU-bound, it will not fry the Mac (the trackers are light; the mesh
front-end is the heaviest and still runs comfortably at capture rate).

## One command to verify the whole software stack

```bash
python3 verify_all.py --fast       # includes every hardware-layer selftest above
```

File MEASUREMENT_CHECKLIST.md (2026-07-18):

# XREAL One Pro, measurement checklist (do this once, carefully)

Each row maps a measurement → the parameter it sets → the file → the nominal value to sanity-check
against. XREAL publishes no mechanical CAD, so these come off **your** unit with calipers. After
measuring: edit the files, run `python3 software/cad_fit.py`, then re-run the sims.

**Already known (no measuring):**
- IPD = **67 mm** (measured) → `NOMINAL_IPD` (`rig.py`) + camera-bracket `ipd` (`xreal_one_mount.scad`)
- Size = **L** → `xr_size = "L"` (display optic centers ≈ 69 mm)
- `target = "xreal_one_pro"`

Tools: digital calipers, a small ruler, and the glasses both **on the table** and **on your face**.

---

## A. Frame measurements (glasses on the table)

| # | Measure | Sets | File | Nominal | How |
|---|---|---|---|---|-----|
| A1 | **Brow rail thickness** (front-to-back depth of the top edge the carrier clips over) | `xr_brow_z` | `xreal_one_mount.scad` | ~**11 mm** | calipers across the top edge, front face to back face |
| A2 | **Flat clamp span on the brow** (width of a flat, grip-able section, clear of sensors/dimming module) | `clip_x` + clip width | `xreal_one_mount.scad` | ~**38 mm** | find a flat run on the brow; note its width + where it is |
| A3 | **Optic drop**: vertical distance from the brow rail (where the carrier sits) DOWN to the **lens optical center** | **`OPTIC_DROP`** ⭐ | `xreal_one_mount.scad` | ~**17 mm** | ruler from the top brow edge straight down to the center of the see-through window |
| A4 | **Optic-center horizontal spacing** (center-to-center of the two see-through windows) | display IPD / `OPTIC_L/R` | `rig.py` | ~**69 mm** (L) | calipers between the two lens centers |
| A5 | **Front frame width** (outer temple hinge to hinge, front) | glasses stand-in, `clip_x` bound | `xreal_one_mount.scad` | ~**151.6 mm** | calipers across the front |
| A6 | **Front frame height** (top brow to bottom of the optic housing) | stand-in | `xreal_one_mount.scad` | ~**50 mm** | calipers vertically |
| A7 | **See-through window size** (the clear aperture per eye) | cone keep-out check | `cad_fit.py` |, | W × H of the transparent area (cameras must clear it) |
| A8 | **Brow-frame material** (note plastic type / finish) | epoxy choice for the bond pads |, |, | check for a resin code; note glossy/matte (affects surface prep) |
| A9 | **Obstructions on the top edge** (sensors, the electrochromic dimming module, ribbon cables) | where the clip may grip | `xreal_one_mount.scad` |, | note their positions so the clip avoids them |
| A10 | *(optional)* **Bridge bar thickness** (front-to-back), only if you also want the clip-on nose support | `xr_bridge_t` | `eye_tracking_bridge.scad` | ~**3.6 mm** | calipers across the nose-bridge bar |

## B. As-worn measurements (glasses on your face)

| # | Measure | Sets | File | Nominal | How |
|---|---|---|---|---|-----|
| B1 | **Vertex distance**: back of the lens/optic to the front of your **eye (cornea)** when worn | `EYE_BEHIND` (= vertex + ~12 mm globe) | `rig.py` | vertex ~**12 mm** → `EYE_BEHIND` ~**24 mm** | side view in a mirror; ruler from lens back to your eye surface (or have a friend judge) |
| B2 | **Pantoscopic tilt**: SET your preferred tilt stage first, then RECORD it; measure the lens-plane angle from vertical if you can | `PANTO_DEG` | `rig.py` | **−3.5°** = the max nose-down stage (One Pro adjusts ±3.5° in 3 stages; the sim now uses the achievable −3.5, fixed 2026-07-06) | note the stage; optionally photograph from the side and measure the angle |
| B3 | **Pupil vs optic center**: where your pupil sits relative to the lens center, vertically (horizontal you already have via IPD) | seating check |, | should be near center | look straight ahead in a mirror; note if your pupil sits high/low/off-center in the window |

---

## After measuring, the update loop
1. Edit `xreal_one_mount.scad`: `xr_size="L"`, `ipd=67`, `xr_brow_z`, `clip_x`, `OPTIC_DROP` (+ obstruction notes).
2. Edit `rig.py`: `NOMINAL_IPD=67`, `EYE_BEHIND`, `PANTO_DEG`.
3. `python3 software/cad_fit.py`: confirms every camera board still clears the cone + eyeball + face.
4. Open `xreal_one_mount.scad` in OpenSCAD (F5), eyeball that the clip matches your brow and no camera enters the see-through cone.
5. Re-run the sim suite (`--complete-geometry`, `--physics-preset`, etc.) for build-real numbers.
6. Print a **cheap PLA draft** of the carrier and dry-fit on the glasses BEFORE the rigid print.

## The three that matter most (if you do nothing else, nail these)
- **A3 `OPTIC_DROP`**: places every camera vertically. Get this wrong and everything is off.
- **A1 `xr_brow_z`**: whether the clip actually grips your brow.
- **B1 vertex / `EYE_BEHIND`**: the eye-relief the whole registration is built on (currently an open ~4.5 mm unknown).

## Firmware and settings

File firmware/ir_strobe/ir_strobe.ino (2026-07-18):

// =====================================================================
//  ir_strobe.ino — IR strobe + SAFETY INTERLOCK firmware (Seeed XIAO / Arduino)
// ---------------------------------------------------------------------
//  Reference firmware for the 6-camera binocular AR eye-tracking rig. It drives the
//  940 nm IR LED rings through 2N7002 low-side MOSFETs, strobed in sync with the camera
//  shutter, and ENFORCES the eye-safety envelope in hardware+firmware so the IR is OFF
//  unless every condition is met. See WIRING.md and EYE_TRACKING.md §3.
//
//  The retina cannot feel IR, so this is built FAIL-SAFE: default OFF, and ANY anomaly
//  (host/USB drop, rail out of range, over-long pulse, blink, reset) forces the gates low.
//
//  SAFETY INTERLOCKS implemented here:
//    1. Strobe in sync with the shutter   -> IR fires only as a bounded PULSE on a host
//                                             "P" command issued at each exposure.
//    2. USB / host drop instantly kills IR -> heartbeat watchdog: no host line within
//                                             HB_TIMEOUT_MS forces both gates low.
//    3. Voltage safeguard                  -> the 5 V rail is read every loop; outside
//                                             [VMIN,VMAX] disables IR.
//    4. IR cutoff on blinks                -> host "B L|R|0" flags closed eyes; that eye's
//                                             ring is held off.
//    5. Dose / duty caps                   -> pulse width clamped to MAX_PULSE_US and a
//                                             minimum OFF time enforces a low duty cycle.
//    6. Any power anomaly -> IR off + a gate PULL-DOWN (external 100k) guarantees OFF
//                            through power-up and MCU reset.
//
//  HARDWARE NOTES (see WIRING.md):
//    * 2N7002 low-side switch per ring; gate from IR_GATE_* with an external 100k pull-down.
//    * IR branch fed from the 5 V rail THROUGH a 300 mA PTC polyfuse (overcurrent).
//    * RAIL_SENSE = the 5 V rail through a divider into an ADC pin (scale set below).
//    * IR power pair is twisted + star-grounded, separate from the USB data cables.
//    * The XIAO also bridges the IMU (I2C -> USB); that stub is at the bottom.
// =====================================================================

// ---- pins (adjust to your board) ----
const int IR_GATE_L  = D1;   // gate of the LEFT ring's 2N7002  (external 100k pull-down to GND)
const int IR_GATE_R  = D2;   // gate of the RIGHT ring's 2N7002 (external 100k pull-down to GND)
const int RAIL_SENSE = A0;   // 5 V rail via a divider (e.g. 2:1) into the ADC

// ---- safety envelope ----
const unsigned long HB_TIMEOUT_MS = 100;    // no host heartbeat within this -> IR off
const unsigned int  MAX_PULSE_US  = 2000;   // hard cap on a single IR pulse (dose cap)
const unsigned long MIN_OFF_US    = 6000;   // min gap between pulses (duty-cycle cap)
const float VMIN = 4.5, VMAX = 5.5;         // acceptable 5 V rail window (volts)

// ---- ADC scaling: reads 0..ADC_MAX over 0..ADC_VREF, rail divided by RAIL_DIV ----
const float ADC_VREF = 3.3;     // XIAO ADC reference (volts)
const int   ADC_MAX  = 1023;    // 10-bit; set 4095 if you switch to 12-bit
const float RAIL_DIV = 2.0;     // divider ratio on RAIL_SENSE (rail = reading * RAIL_DIV)

// ---- state ----
unsigned long lastHeartbeat = 0;
unsigned long lastPulseEnd  = 0;
bool enabled   = false;         // host must "EN" to arm strobing
bool blinkL    = false;
bool blinkR    = false;
String line;

void gatesOff() {
  digitalWrite(IR_GATE_L, LOW);
  digitalWrite(IR_GATE_R, LOW);
}

float railVolts() {
  int raw = analogRead(RAIL_SENSE);
  return (raw * ADC_VREF / ADC_MAX) * RAIL_DIV;
}

// every interlock that must hold for IR to be allowed AT ALL this instant
bool envelopeOK() {
  if (!enabled) return false;
  if (millis() - lastHeartbeat > HB_TIMEOUT_MS) return false;   // USB/host drop
  float v = railVolts();
  if (v < VMIN || v > VMAX) return false;                       // voltage safeguard
  return true;
}

// fire ONE bounded, interlocked IR pulse on the requested ring(s)
void pulse(unsigned int us, bool left, bool right) {
  if (!envelopeOK()) { gatesOff(); return; }
  if (micros() - lastPulseEnd < MIN_OFF_US) return;             // duty-cycle cap
  if (us > MAX_PULSE_US) us = MAX_PULSE_US;                     // dose cap
  bool l = left  && !blinkL;                                    // blink cutoff (per eye)
  bool r = right && !blinkR;
  if (!l && !r) return;
  if (l) digitalWrite(IR_GATE_L, HIGH);
  if (r) digitalWrite(IR_GATE_R, HIGH);
  unsigned long t0 = micros();
  while (micros() - t0 < us) {
    if (millis() - lastHeartbeat > HB_TIMEOUT_MS) break;        // abort mid-pulse on host drop
  }
  gatesOff();
  lastPulseEnd = micros();
}

void setup() {
  pinMode(IR_GATE_L, OUTPUT);
  pinMode(IR_GATE_R, OUTPUT);
  gatesOff();                 // fail-safe OFF on boot
  Serial.begin(115200);
  // Wire.begin();            // <- enable for the IMU I2C bridge stub below
}

void loop() {
  // ---- continuous safety: if the envelope breaks, gates go low immediately ----
  if (!envelopeOK()) gatesOff();

  // ---- parse host commands (newline-terminated) ----
  while (Serial.available()) {
    char c = Serial.read();
    if (c == '\n') { handleLine(line); line = ""; }
    else if (c != '\r' && line.length() < 32) line += c;
  }

  // forwardImu();            // <- enable for the IMU I2C->USB bridge
}

void handleLine(const String &s) {
  lastHeartbeat = millis();                 // ANY recognized host line is also a heartbeat
  if (s == "HB") {
    return;                                 // pure heartbeat
  } else if (s == "EN") {
    enabled = true;
  } else if (s == "DIS") {
    enabled = false; gatesOff();
  } else if (s.startsWith("P")) {           // "P <us>"  -> one strobe pulse, both rings
    int us = s.length() > 2 ? s.substring(2).toInt() : 1000;
    pulse((unsigned int)us, true, true);
  } else if (s.startsWith("B")) {           // "B L" | "B R" | "B 0"  -> blink state
    char e = s.length() > 2 ? s.charAt(2) : '0';
    blinkL = (e == 'L' || e == 'l');
    blinkR = (e == 'R' || e == 'r');
    if (blinkL) digitalWrite(IR_GATE_L, LOW);
    if (blinkR) digitalWrite(IR_GATE_R, LOW);
  } else {
    Serial.println("ERR");
  }
}

// =====================================================================
//  IMU I2C -> USB bridge (stub). The Mac has no native I2C, so the XIAO relays the
//  ICM-20948. Use SparkFun_ICM-20948 (or your driver) to read accel+gyro and Serial.print
//  them; software/imu.py's Kalman filter consumes accel-tilt + gyro-rate. Kept minimal so
//  this file stays focused on the SAFETY logic above.
// =====================================================================
// void forwardImu() {
//   // read accel (g) + gyro (deg/s) from the ICM-20948 over I2C, then:
//   // Serial.print("IMU "); Serial.print(ax); ... Serial.println(gz);
// }

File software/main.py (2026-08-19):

#!/usr/bin/env python3
"""AR eye-corner pixel calibration, real-time loop.

Modes:
  python3 main.py --selftest            headless convergence test (numpy only)
  python3 main.py --simulate            interactive GUI sim (align red onto green)
  python3 main.py --world-cam-left 0 --world-cam-right 1 --eye-cam-left 2 --eye-cam-right 3
  python3 main.py --list-cams           probe which camera indices are connected
  python3 main.py --calibrate-corners   capture the eye-corner templates (do once)

The live loop each frame:
  1. read features  = [worldL_dot, worldR_dot, eyeL_corner, eyeR_corner] (8, norm [0,1])
  2. predicted pixel = calibrator.predict(features)
  3. shown pixel     = predicted + your accumulated joystick/key nudge
  4. render red dot (sim also renders the green truth target)
  5. on APPROVE: high-speed snapshot the eye corners, store
       (features -> shown pixel), retrain, reset nudge, next dot.
"""
import argparse
import json
import sys
import time

import numpy as np

from config import Config
from dataset import Dataset
from calibrator import Calibrator
import autosim
import rig


# ----------------------------------------------------------------------
#  Shared: load dataset + (re)fit a calibrator
# ----------------------------------------------------------------------
def make_lambdas(cfg: Config) -> np.ndarray:
    return np.logspace(np.log10(cfg.lambda_lo), np.log10(cfg.lambda_hi),
                       cfg.lambda_steps)


def new_calibrator(cfg: Config) -> Calibrator:
    return Calibrator(cfg.n_features, cfg.poly_degree, cfg.min_samples_for_model,
                      make_lambdas(cfg), cfg.robust_iters, cfg.huber_k)


def build_calibrator(cfg: Config, ds: Dataset) -> Calibrator:
    cal = new_calibrator(cfg)
    X, Y, W = ds.load()
    cal.fit(X, Y, W)
    return cal


# ----------------------------------------------------------------------
#  Headless self-test: prove the learning loop converges, no hardware/GUI
# ----------------------------------------------------------------------
def run_selftest(cfg: Config, iterations: int = 240, seed: int = 0) -> int:
    print("== headless self-test (anatomy simulator, one subject) ==")
    print("Closed-loop calibration with the glasses slipping naturally each step and")
    print("~12% GROSS outliers injected (mis-tracked corners / fat-fingered approves)")
    print("to prove robustness. 'residual' = the overlay miss BEFORE the correction.\n")
    sim = autosim.Simulator(seed)
    subject = sim.new_subject()
    dev = sim.seat()
    rng = np.random.default_rng(seed + 1)
    cal = new_calibrator(cfg)
    X = np.empty((0, cfg.n_features)); Y = np.empty((0, 2)); Wt = np.empty((0,))
    window = []
    outliers = 0
    print("%6s | %12s | %9s | %8s | %s" %
          ("sample", "residual px", "median px", "lambda", "model"))
    print("-" * 60)
    for i in range(1, iterations + 1):
        dev = sim.slip(dev)                           # glasses move, naturally
        obs = sim.observe(subject, dev, sim.world_point())
        if obs is None:
            continue
        f, label, truth = obs
        residual = float(np.linalg.norm(cal.predict(f) - truth))   # real overlay miss
        window.append(residual)
        if len(window) > 25:
            window.pop(0)
        feat, approved = f, label                     # train on the human answer
        conf = float(np.clip(rng.normal(0.85, 0.1), 0.2, 1.0))
        if rng.random() < 0.12:                       # inject a gross outlier
            outliers += 1
            if rng.random() < 0.5:
                approved = rng.uniform(0, 1, 2)        # fat-fingered approve
            else:
                feat = np.clip(f + rng.normal(0, 0.25, f.shape), 0, 1)  # bad track
            conf = min(conf, float(rng.uniform(0.2, 0.45)))
        X = np.vstack([X, feat]); Y = np.vstack([Y, approved])
        Wt = np.append(Wt, conf)
        cal.fit(X, Y, Wt)
        if i % 20 == 0:
            avg = float(np.mean(window))
            he = cal.holdout_error(X, Y, Wt)
            med = he[1] * 1080 if he else float("nan")
            print("%6d | %12.1f | %9.1f | %8.3f | %s" %
                  (i, avg * 1080, med, cal.lambda_ or 0,
                   "trained" if cal.is_trained else "warming up"))
    final = float(np.mean(window))
    he = cal.holdout_error(X, Y, Wt)
    print("-" * 60)
    print("injected outliers : %d of %d samples (%.0f%%)"
          % (outliers, iterations, 100.0 * outliers / iterations))
    print("final residual    : %.1f px @1080p (auto-prediction vs truth)"
          % (final * 1080))
    if he is not None:
        print("holdout error     : %.1f px RMS / %.1f px median @1080p"
              % (he[0] * 1080, he[1] * 1080))
    auto_med = he[1] if he else 0.0
    ok = final < 0.025 and auto_med < 0.025
    print("\nRESULT:", "PASS, learned an accurate map despite outliers ✅" if ok
          else "WEAK, residual still high ⚠️")
    return 0 if ok else 1


# ----------------------------------------------------------------------
#  Camera helpers (import cv2-dependent modules lazily)
# ----------------------------------------------------------------------
def run_list_cams() -> int:
    from cameras import list_cameras
    print("Probing camera indices 0..7 ...")
    for idx, ok in list_cameras():
        print("  index %d : %s" % (idx, "OK, frames flowing" if ok else
                                    "opens but no frame"))
    print("Map these to --world-cam-left/right and --eye-cam-left/right "
          "(world + eye-corner base of the 6-cam binocular build: 2 world + 2 eye-corner;")
    print("the 2 NIR pupil cams attach via the pupil/live_features path, +2 stereo = 8-cam FULL)")
    return 0


# Minimum eye-corner template size, in CAPTURE pixels. Measured on this rig 2026-08-02: the
# cross-frame localisation margin is dominated by template SIZE, not by placement or contrast
# enhancement. Sweep at the eyeR corner, cropping one frame and matching into a frame 1.2 s later:
#     30px 0.041  45px 0.049  60px 0.057  80px 0.064  110px 0.066  150px 0.091  200px 0.207
# Enforcing 150 took the two real captures from 0.046/0.021 to 0.121/0.057, confirming size is the
# lever; 200 is where eyeR clears the bar with room to spare.
#
# TRADE-OFF, deliberately taken: 200 px is a quarter of the frame height, so the patch is as much
# "face around the corner" as it is the canthus, and rig.py models the tracked point as the canthus
# ITSELF. A constant offset is absorbed by the calibrator (it learns a mapping), and the patch
# still MOVES with the corner, which is what the features encode. What it costs is sensitivity to
# soft-tissue deformation -- and SOFT_TISSUE_SD=0.15mm in rig.py is a "holding still" placeholder
# that squinting/talking already blows past. So: hold a neutral face when calibrating. A lock that
# wanders is useless; a slightly impure landmark is merely biased, and bias is learnable.
TEMPLATE_MIN_PX = 200
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

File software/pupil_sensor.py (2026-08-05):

"""NIR pupil / iris sensor model, the sensor that breaks the identifiability wall.

WHY this exists
---------------
The fingerprint-matching study (`match.py`) found two eye parameters that the eye-corner
cameras + guess inaccuracy CANNOT recover:

 * entrance-pupil depth `ep_dist`, it IS in the physics (the entrance pupil sits
    `ep_dist` ahead of the center of rotation and drives parallax), but its imprint on the
    registration error is tiny, so it stays buried in noise (~80% of population spread).
 * eyeball radius `globe_r`, it is in the anatomy descriptor but has NO effect on any
    current observable, so it is non-identifiable BY CONSTRUCTION (recovery ~= guessing the
    mean). A sensor can only recover it once the model gives it a physical effect.

This module adds the sensor the eye-tracking upgrade already calls for (an NIR camera at the
display eye imaging the pupil + iris, cf. EYE_TRACKING.md / pupil_tracker.py) and the two
observables that make those parameters identifiable:

  1. PUPIL CENTRE across gaze. The entrance pupil is `cor + ep_dist*gaze`; as the eye
     rotates to fixate different dots it sweeps a sphere of radius `ep_dist` about the
     centre of rotation. An eye camera sees that arc, so fitting it across several gaze
     directions recovers `ep_dist` directly (geometry, not buried in registration noise).
  2. IRIS DIAMETER. The visible iris (HVID ~11.7 mm) scales with eyeball size, so the
     imaged iris diameter is a direct, if noisy, read on `globe_r`. This is the physical
     effect `globe_r` was missing.

The camera is modelled separately from rig.build so the validated registration pipeline is
untouched; it only adds NEW observables for identification. Magnitudes are PLACEHOLDERS at
plausible values, replace with the measured OV9281 + IR-LED rig once built.
"""
import numpy as np

import rig
import anatomy
from optics import look_at, PinholeCamera

# iris size model: HVID correlates with axial length / eyeball radius
IRIS_R_MEAN = 5.85                 # mm, mean visible iris radius (HVID/2)
IRIS_R_PER_GLOBE = 0.55            # mm visible-iris-radius per mm of globe_r deviation
NIR_PIX_SD = 0.0016                # pupil-centre localisation noise (norm, ~1 px @640)
IRIS_DIAM_SD = 0.004               # iris-diameter measurement noise (norm)

def build_camera():
    # single source of truth: the same NIR pupil cam the rig/simulator use (rig.py)
    return rig.build_pupil_camera()


def pupil_read(subject, dev, P, rng, cam):
    """Imaged (pupil_centre_xy (2,), iris_diameter (1,)) for this face/pose/gaze, or None.

    pupil_centre encodes ep_dist (+ cor); iris_diameter encodes globe_r.
    """
    R, t = rig.pose_R_t(dev)
    cor = (R @ subject.cor.T).T + t
    e = rig.DISPLAY_EYE
    gaze = P - cor[e]
    gaze = gaze / np.linalg.norm(gaze)
    pupil = cor[e] + subject.ep_dist * gaze          # the entrance pupil (same as the oracle)
    uv = cam.project(pupil)
    if uv is None:
        return None
    uv = uv + rng.normal(0, NIR_PIX_SD, 2)

    iris_r = IRIS_R_MEAN + IRIS_R_PER_GLOBE * (subject.globe_r - anatomy.GLOBE_R_MEAN)
    dist = np.linalg.norm(pupil - cam.pos)
    diam = cam.f * (2.0 * iris_r) / dist             # imaged iris diameter (normalised)
    diam = diam + rng.normal(0, IRIS_DIAM_SD)
    return uv, np.array([diam])

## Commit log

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2026-07-24 Assembly fixes + camera viewer
    CAD: widen M2 bores 1.8->2.3 (printed holes were closing) + boss 5->5.5; remove
    holeless strain posts; clamp 1.5mm tighter + rear jaw down 5mm; raise world cams
    WC_UP 44->49 so lower screws clear; fill the front-boom-to-holder junction gap.
    Software: cam_view.py live USB camera viewer (enumerate, IR remote test, focus).
    [xreal_one_mount.scad]
2026-07-24 Boom + plate refinements from PLA dry-fit
    - Fix world junction fill: ball no longer pokes through the plate front (biased behind)
    - Lower side (eye) booms 2mm and bottom (pupil) boom 1mm via transit-height override
    (arms only; cameras unmoved, parity exact)
    - Fill the pupil boom turn-down elbows
    - USB pass-through slot thin side 4.5->5.5 for more cable room
    - World cam cable: centered back slot clear of the 4 screw holes (was edge notch)
    [xreal_one_mount.scad]
2026-07-24 More dry-fit fixes: robust ball fix, straight-up world riser, wider holes
    - World boom ball: extend the boss BACKWARD (boss_depth) so the boom attaches fully
    behind the plate; no forward fill ball -> cannot poke the plate front
    - World riser goes straight up to the plate centre (x=33.5); shorten the eye foot-wing
    24->12 so it clears; world foot fuses into the clamp top (reclassified)
    - Fix wire-retaining tabs floating off (coincident face -> now dip into the rail)
    - Screw bores 2.3->2.5; USB slot thin side 5.5->6.5; fill eye down-joints
    - verified: parity exact, world clear of cone/glasses/eye, STL 1 shell
    [xreal_one_mount.scad]
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2026-07-24 World boom: fill the turn-down elbow but skip the top corner (it sits behind the plate and would poke the front)
    [xreal_one_mount.scad]
2026-07-24 Boom joints: hull-gusset fills + no overshoot for above-rail holders
    - elbow_gusset() webs each bend with a hull of leg stubs (fills the concave crook,
    which a centre sphere left open) and stays within the tube envelope
    - world/above-rail booms rise straight to the boss (no up-over-down overshoot), so
    the top elbow's legs point away from the plate and its gusset embeds in the plate
    instead of poking the front
    - verified: 1 shell, world clear of cone/glasses/eye, no forward poke
    [xreal_one_mount.scad]
2026-07-24 Revert to v4 boom geometry; fill only the down-facing (pupil) boom elbow for print stability
    [xreal_one_mount.scad]
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2026-07-24 Actually enable the pupil LED shelf (led_pad=true was silently lost in the v4 revert)
    The shelf geometry existed but was never called, so it never rendered in v10/v11 -
    that's why it was invisible. Enabled on both pupil holders; NOW verified with the
    shelf present: clear of face (30mm), cone, glasses, eyeball, eye holder; 1 shell.
    [xreal_one_mount.scad]
2026-07-24 LED shelf: follow the mirror (led_pad = side) so both pupil shelves point outboard
    The left holder is mirrored, so a fixed local-+x tab sent its shelf inboard. Passing
    led_pad = side flips the left shelf to its temple side. Both now outboard, symmetric, 1 shell.
    [xreal_one_mount.scad]
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2026-07-25 Host software stack: connect, synchronized capture, auto-exposure, world-mesh tracking
    Adds the hardware bring-up layer that runs the 6-camera rig on the Mac, all with
    headless --selftest (now in the release gate):
    - connect.py auto-classify/assign the 6 USB cams to roles + persist rig_cameras.json
    - sync_capture.py SyncBank: barrier-aligned synchronized grab + measured jitter
    (0.2ms vs 60ms naive sequential in selftest)
    - autoexpose.py continuous per-role exposure/gain (world sharp; pupil glints hot, field dark)
    - world_mesh.py real-world mesh tracking: stereo triangulate + robust Kabsch VO
    (RANSAC+Tukey-IRLS, 8mm @ 25% outliers) + IMU-fused pose +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
    [autoexpose.py, capture.py, connect.py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]
2026-07-25 World-locked overlay on moving people (turn-people-into-monkeys)
    Adds the full real-world overlay pipeline on top of the calibrated rig, all sim-first
    with headless --selftest (now in the release gate):
    - anchor.py world-locked projection: 3D world point + mesh pose + calibrated map
    -> display pixel, parallax-correct via stereo depth. Proven: 0.00px
    lock across head poses, 252px drift without re-projection.
    - people_track.py detect+track people across the world stereo pair -> stereo 3D world
    position, STABLE IDs, alpha-beta velocity model that dead-reckons
    through detector dropouts/occlusion. Default detector = Op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
    [anchor.py, augment_rig.py, avatar.py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]
2026-07-25 Overlay quality: temporal smoothing, better monkey asset, face-aligned head
    - avatar.py: rewrote make_monkey_texture (brown fur, radial shading, tan face +
    muzzle, eyes w/ highlights, belly) so it reads as a monkey not a flat blob.
    Added RenderSmoother (per-id EMA on the drawn quad) -> ~3.5x less on-screen
    jitter (0.0092->0.0026 in selftest), wired into MonkeyAugmenter.step.
    - people_track.py: face-box-aware head anchor — when a face is detected, EMA its
    3D position as the head point (aligns the monkey face to the real face); lands
    within 20mm of the true head in sim. Additive: a no-op when no face detected.
    - Regenerated ~/Desktop/monkey_sprite.png + monkey_overlay_demo.png.
    Se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
    [augment_rig.py, avatar.py, people_track.py]
2026-07-26 Eye-corner cams: re-aim down+outward to centre the outer canthus
    Mounted left-arm test showed the outer corner riding the bottom-left edge of the
    eye cam frame (risk of losing it on a glasses slip). Bias the eye-cam aim DOWN 6mm
    + OUTWARD 3mm at the aim point (~11 deg down tilt), mirrored both sides. Applied in
    BOTH the CAD (eye_cam) and rig.py (build eye) so they stay consistent; CANTH_SIM /
    nominal_outer_canthus() and all camera POSITIONS unchanged (parity 0.0003mm holds).
    Verified: cad_fit + wearable pass, eye boom clears its own board, accuracy neutral
    (1.88px median vs 1.90 before -- canthus is still the tracked landmark, re-centred).
    Draft carrier = 1 shell; diff vs v9 = LED wings + e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
    [xreal_one_mount.scad]
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2026-08-02 perf: don't degrade quality when it doesn't help (measured on the rig)
    First full-load run on real hardware (4 cams + world mesh + 1920x1080 overlay,
    45 s, 601 frames):
    track 45.65 ms 62% FRAME 73.61 ms (p95 84.20)
    sync 19.56 ms 27% achieved 13.4 fps vs a 30 fps budget
    overlay 8.78 ms 12% cpu 9% of 16 cores (peak 9%)
    Two findings. First, the CPU was never the risk -- 9% of the machine with
    everything running. The pathology was compose() at 401 ms/frame, already fixed.
    Second, and the reason for this commit: QualityController walked straight to
    `min` and held it for 45 s while frame time barely moved (91 -> 77 ms). 27% of
    the frame is USB wait it cannot co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
    [perf.py]
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2026-08-02 Bring-up truth: 640x480 by default, honest BANK UP, disparity-sign check
    Three things this rig kept re-deriving, now fixed in code so they cannot be
    re-litigated from a transcript.
    bank_bringup.py
    * The --run opener re-derived `h = ROLE_RES[role] * 3 // 4`, asking the 16:10
    world cams for 1280x960 -- a mode neither sensor has. The driver falls back
    to uncompressed, four streams swamp the shared USB 2.0 bus, and
    sync_capture's barrier stalls the bank. Now reads SyncBank.ROLE_MODE, the
    single source of truth. Measured on hardware, same rig, same session:
    default : 8 sets/15 s, eyeR + worldL at 100% misses, ~1 fps, 118.36 ms
    640x480 : 297 sets, zero misses on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
    [bank_bringup.py, calib_preflight.py]
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2026-08-02 calibrate-corners: live preview, per-eye re-do, and DRAW IT BIG
    Three fixes to a step that cost several runs on 2026-08-02.
    LIVE PREVIEW. The old flow grabbed ONE frame per eye and made you draw on
    whatever it caught -- a blink or a bad exposure and the only recourse was to
    re-run and redo the eye you had already got right. Now SPACE freezes the frame
    you like, Q skips, and the overlay shows live texture + saturation readings.
    --eye L|R re-does a single eye, leaving the other template alone.
    DRAW IT BIG -- this reverses the old "small tight box" instruction, which is
    wrong for this rig. Measured cross-frame localisation margin vs box size (crop
    from one frame, match into a frame 1.2 s lat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
    [main.py]
2026-08-02 templates: enforce a minimum size in code, not in the instructions
    Template SIZE, not placement or contrast, is what decides whether an eye-corner
    template localises on this rig. Measured 2026-08-02, cropping one frame and
    matching into a frame 1.2 s later (what tracking actually does):
    30px 0.041 45px 0.049 60px 0.057 80px 0.064 110px 0.066
    150px 0.091 200px 0.207
    The instruction "draw it 150-200px" does not work, and that is not the user's
    fault: cv2.selectROI renders the frame scaled into a window with no size
    readout, so nobody can judge 150 image-pixels by eye. Three consecutive captures
    came out 26-77 px when 150 was asked for, and every one failed.
    * EyeCornerTracker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
    [eye_tracker.py, main.py]
2026-08-02 canthus_data: build a labelled corpus from the rig, no hand-labelling
    Step 1 of replacing hand-boxed templates with a learned inner-canthus detector.
    Dylan, 2026-08-02: "i cant box every time." Template capture is a MANUAL step
    every session, and a slightly-wrong box yields a template that scores ~1.0 and
    localises nowhere. That is the thing to delete, and it needs training data.
    NOT web images. Face photos online are frontal, visible-light, 0.5-2 m out.
    These cameras sit ~3 cm from the eye, oblique, mono NoIR, wide-angle, low
    contrast -- a different distribution, which is precisely why this project
    rejected face-mesh landmarkers already ("glasses-mounted close-up can't use
    face-mesh"). A m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
    [canthus_data.py]
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2026-08-02 canthus_data: record that template auto-labelling FAILED, and why
    The plan was to let the template teach the model: match over thousands of
    frames, keep unambiguous locks, call those labels. Measured on a real 1500-frame
    run, it does not work.
    When the rig shifts on the face the matcher settles on FEATURELESS SKIN -- nose
    bridge, cheek -- and does so confidently. Labels more than 0.20 frame-units from
    the per-eye median were 34.8% of eyeL and 5.2% of eyeR, and those outliers
    averaged margin 0.486 against a corpus median of 0.414.
    THE WRONG LABELS SCORED HIGHER THAN THE RIGHT ONES. No confidence threshold
    filters that -- the gate is anti-correlated with correctness. Eyelashes fail the
    same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
    [canthus_data.py]
2026-08-03 canthus: hand-label tool + two-model ensemble trainer
    Dylan's call: "ML can be better than current. have it for hundreds, then have
    another confirm each labeling is correct. if hundreds isn't enough, thousands."
    The verifier half is what fixes the failure that killed auto-labelling.
    canthus_label.py -- the seed set, made cheap:
    * template's guess is PRE-FILLED; ENTER accepts, click only corrects the ones
    that are wrong. Most are right, so most frames are one keypress.
    * deterministic shuffled order so 300 labels span every seating/blink/lighting
    in the session rather than 300 near-duplicates of one instant
    * resumable, undoable, skippable
    * reports how often the human overru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
    [canthus_label.py, canthus_train.py]
2026-08-03 canthus: detect closed eyes as a second head
    Dylan asked for it, and it fills a real gap: rig.py already MODELS blink
    dropouts, but nothing in the live loop DETECTS one. A sample recorded mid-blink
    is bad twice over -- the gaze is not fixated, and the lid deforms exactly the
    soft tissue a 200px landmark patch sits in. The calibration loop should be able
    to skip those frames.
    * canthus_label.py --closed-pass: binary second pass, one key per frame
    (O open / C closed). Kept SEPARATE from the position pass on purpose --
    binary judgements go at a completely different speed from precise clicking
    and mixing them slows both. Warns if fewer than ~15 closed examples, since
    the head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
    [canthus_label.py, canthus_train.py]
2026-08-03 canthus_auto: propose / correct / confirm, judged by the anatomical prior
    Dylan's design: "the first one guesses, the second corrects, and then they go
    until it is correctly confirmed by the second one. then next image." Same pattern
    pixel_sweep.py already uses (GuessingAI proposes, UserAI corrects, accept only
    when right TWICE IN A ROW) and the same shape as main.py's human loop.
    THIRD JUDGE, NOT LEARNED. Agreement between two estimators is evidence only if
    their errors are uncorrelated, and template matching taught us they need not be:
    it was CONFIDENTLY wrong, with bad labels scoring HIGHER margin than good ones.
    So every confirmed proposal is also tested against the ANATOMICAL PRIOR --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
    [canthus_auto.py]
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2026-08-03 canthus_auto: fix the prior units and the dead closed-eye detector
    TWO REAL BUGS FIXED, ONE FINDING THAT SURVIVES THEM.
    1. PRIOR WAS IN THE WRONG UNITS. optics.PinholeCamera normalises u AND v by the
    same focal ("half-size 0.5 spans half-FOV"), i.e. it models a SQUARE frame.
    The OV9281 is 1280x800, so the sensor covers the full width but only the
    middle 62.5% vertically: v_square in [0.1875, 0.8125]. A measured label is
    normalised over the real 800-px height and spans [0,1]. build_prior compared
    the two directly.
    Converted, the prior is v [0.110, 0.620] median 0.362, not [0.256, 0.575].
    u was never affected because the square's width IS the sensor width -- which
    is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
    [canthus_auto.py]
2026-08-03 canthus_auto: use the MOUNT as a fiducial instead of hunting by appearance
    Dylan: "don't just go by brightness. we know that the nose bridge support is in a
    fixed position and has a given size and color. use the known object location and
    relativity instead of just looking to find one piece of the painting."
    Correct, and it fixes the failure. The mount is bolted to the camera, so it
    projects to the SAME pixels in every frame regardless of how the glasses sit on
    the face. It is a built-in fiducial: the face moves relative to it, it never
    moves relative to the sensor. Measured on the real corpus by intersecting DARK
    with TEMPORALLY STATIC:
    eyeL covers 7.3% of frame, floor v=0.340, 4.4x m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
    [canthus_auto.py]
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2026-08-03 canthus_auto: record that the bootstrap cannot originate the landmark
    With the mount fiducial, prior box, confirm loop and closed-eye skip all working,
    the module confirms ~58% of frames with tight consistent labels (eyeR u std
    0.006, v std 0.021) sitting ON THE EYE. Zoomed in they sit on the UPPER LID and
    brow skin -- not the tear duct. Every aggregate metric looked good.
    Structural, not a tuning miss: nothing in the classical chain IDENTIFIES a
    canthus. The mount constrains WHERE to look, the template reports WHAT matched,
    and the pupil offset was fitted from those same template hits -- every link
    anchored to something that is not the landmark, so the system is self-consistent
    and wrong.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
    [canthus_auto.py]
2026-08-03 canthus_auto: independent A/B estimators, and the real root cause
    Dylan was right twice over. First: the estimators could not disagree because I
    fitted the corrector's offset from the proposer's own output -- my bug, not a
    limit of the design. Proof of how bad it was: the labels came out as
    pupil-plus-a-constant, correlating +0.99 with the pupil and with a
    label-minus-pupil std of 0.004. The "confirmation" was vacuous.
    Second: separate estimation with a proximity gate is the right construction.
    Rebuilt that way, sharing no fitted parameter:
    A appearance -- template match in the mount band, single frame
    B motion -- textured AND temporally stationary over a window. The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
    [canthus_auto.py]
2026-08-03 canthus: the landmark model trains, and the ensemble verifier works
    First end-to-end run on real ground truth. Dylan placed 30 seed points (26 open,
    4 closed) on full uncropped native frames; everything below follows from that.
    TRAINING (seed only, 30 points):
    model 0 held-out median 0.0338 frame units (43.2 px of 1280)
    model 1 held-out median 0.0296 frame units (37.9 px of 1280)
    Dylan's own click scatter was +-0.021 to +-0.027, so the models reproduce his
    labels about as precisely as his labels agree with each other -- i.e. trained to
    the label-noise floor. More seeds would now help more than more training.
    ENSEMBLE VERIFIER (Dylan's design: estimate separately, require proximit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
    [canthus_data.py, canthus_label.py, canthus_train.py]
2026-08-03 canthus_net: numpy runtime for the trained model
    The missing half. canthus_train exported weights but nothing could USE them --
    there was a trained model and no way to run it.
    Pure numpy, no torch: five convolutions with BatchNorm pre-folded into
    scale/shift at export, so the live loop inherits no 200 MB dependency and
    verify_all stays self-contained. This also sidesteps the platform trap -- this
    Intel Mac tops out at torch 2.2.2, which predates numpy 2 and breaks interop with
    the main venv outright.
    Returns (u, v, closed_prob, SHARPNESS). The sharpness term is the point: it is
    how peaked the heatmap is, and a flat heatmap means the model does not know.
    Template matching could never say th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
    [canthus_net.py]
2026-08-03 canthus_net: confidence, jump and smoothing gates for the live tracker
    Dylan on hardware: the prediction "moved off when I open my eyes super wide or
    look outside glasses frame". Both are OUT OF DISTRIBUTION -- the 30 seed points
    were normal-gaze frames, so the model has never seen an eye held wide or rotated
    to an extreme. The real fix is seed coverage at those poses; this makes the
    failure SAFE meanwhile, which matters because a silently wrong landmark is worse
    than an admitted gap.
    CONFIDENCE GATE, threshold measured not guessed. Heatmap peak on eyeL:
    confident frames (all 30 seeds included) 0.018 - 0.022, min 0.0182
    whole-corpus 5th percentile 0.0152
    blank fra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
    [canthus_net.py]
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2026-08-03 canthus: gaze-diverse seed breaks the eyeball-following shortcut
    Dylan on hardware: "when i look off screen, guess goes to my eye ball." That is
    the model having learned a SHORTCUT. With 13 labelled frames the iris sat at a
    near-constant offset from the canthus, so "somewhere relative to the big dark
    circle" fitted the training data as well as the real landmark did -- and at
    extreme gaze, where the iris goes somewhere it never saw, the prediction followed
    it. Same pupil-anchoring trap that broke the classical pipeline, reappearing in
    the model for the same reason.
    FIX, two parts:
    1. CORPUS. Re-collected 1200 frames targeting the measured gaps. Before/after:
    eyeL closed 0.0% -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
    [canthus_label.py]
2026-08-03 main: --use-model runs calibration on the learned canthus, not templates
    The step that connects today's work to the actual goal. CanthusTracker gains a
    track() with EyeCornerTracker's signature, so it drops into the live loop
    unchanged, and --use-model selects it.
    Confidence maps onto machinery that already exists rather than a new special
    case: state ok -> 1.0, held -> 0.3, lost -> 0.0, against config.eye_conf_min =
    0.45. So a sample is recorded only when the tracker is both confident and
    physically plausible; a held or lost frame is refused by the same gate that
    already guarded template matches.
    REMOVED THE SHARPNESS GATE ENTIRELY. It worked on the 30-seed model and INVERTED
    on the 98-se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
    [canthus_net.py, main.py]
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2026-08-03 calibrator: track head motion before training; surface the raw keycode
    TWO HARDWARE FINDINGS FROM DYLAN, both real.
    1. "when i move my head up, the dot should move down to counteract and stay on
    the dot. dot is just staying in position."
    Correct, and the cause was structural: predict() returned a FIXED fallback
    whenever self.W is None, i.e. before the first sample. A constant cannot track
    anything, so the very first corrections -- the ones that bootstrap everything
    else -- were being made against a marker nailed to the screen while the world
    moved behind it.
    Added Calibrator.geometric_bootstrap(): the world cameras already measure the
    dot's DIRECTION, and a display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
    [calibrator.py, main.py, overlay.py]
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2026-08-03 calib_preflight: --use-model checks the LEARNED tracker, not the templates
    The corner-lock row tests EyeCornerTracker against hand-drawn patches. Under
    --use-model those templates are never loaded, so that row answers a question the
    run is not asking: it can fail while the real tracker is fine (observed: eyeL
    0.47 while the model was tracking) or pass while the model is broken. Neither is
    useful, and a check that measures the wrong thing is the failure mode that has
    cost this project the most time.
    check_model_lock() runs CanthusTracker on the live frames and passes only when
    both eyes report state 'ok' -- a position that is anatomically plausible for that
    camera and did not jump. Those gat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
    [calib_preflight.py]
2026-08-03 canthus_net: use the mount as a fiducial — flex watchdog + camera-shift invariance
    Dylan's idea, and it turns the rig's own hardware into an instrument. The mount
    is bolted to the camera, so its image position is fixed by rigid geometry: it
    should never move in frame whatever the face does. Measured repeatability on this
    rig, centroid over 100 frames:
    eyeL u +-1.96 px of 1280 v +-0.06 px
    eyeR u +-1.72 px v +-1.40 px
    TWO USES, and the second is the valuable one.
    FLEX WATCHDOG. If the mount's apparent position changes, the camera has moved
    relative to the carrier. data/flex.log identified that as critical -- 0.2mm/0.2deg
    costs +0.05 px but 1mm/1deg costs +1.3 px, mor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
    [canthus_net.py]
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2026-08-03 canthus_net: the tracker could not be constructed at all — and 38 checks said it could
    THE BLOCKER ON THE CALIBRATION RUN, and it was never the keyboard.
    CanthusTracker.__init__ never created self.anchor / self._warm / self.flexed. The
    mount-anchor commit 12d2c13 added their USE in update() and set them only inside
    the selftest, which built the object with CanthusTracker.__new__(...) and assigned
    every attribute by hand. `git log -S "self.anchor = MountAnchor()"` proves that line
    had never existed in any commit. So main.py --use-model raised AttributeError on
    FRAME ONE of both eye cameras.
    THE TIMELINE EXPLAINS THE WHOLE PREVIOUS HANDOFF: 12d2c13 landed 07:41, the handoff
    was written 07: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
    [canthus_net.py, main.py]
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2026-08-03 eye_check --live: seating aid, and the geometry of how far the carrier must move
    NO CAD CHANGE AND NO REPRINT IS INVOLVED IN ANY OF THIS. The brow clamp is a
    physical adjustment by design -- ASSEMBLY.md section 6.1: silicone pads line both
    jaws, the clamps drop over the brow, M3 thumbscrews snug them. Loosen, shift,
    retighten. Recording that explicitly because "adjust the brow clamp" read as a
    request to re-print, and the carrier being final is a settled fact.
    HOW FAR IT MUST MOVE, computed from rig.py rather than guessed: the eye cam sits
    55.0 mm from the nominal inner canthus, and a 45 deg horizontal FOV on a 16:10
    sensor gives 29.0 deg vertically over 800 px (0.0363 deg/px). Recovering t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
    [eye_check.py]
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
